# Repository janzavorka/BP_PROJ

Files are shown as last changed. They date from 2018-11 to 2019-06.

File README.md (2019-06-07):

# BP_PROJ

### piskvorky_MP [➥](piskvorky_MP/)
- Piškvorky pro až 5 hráčů
- 1x arduino Due jako server, max 5x arduino Ethernet s dotykovým displejem jako client
- připojovánou přes router s DHCP (serveru nutno přidělit pevnou IP)
- aktualizovaný návod na ovládání [zde](https://github.com/janzavorka/BP_PROJ/blob/master/piskvorky_MP/manual.md)
---

### Piskvorky_red [➥](Piskvorky_red/)
- Původní verze verze hry pouze pro dva hráče
- HW: 2x Arduino Ethernet, 2x 2,4" dotykový display
- jedno arduino jako server, druhé jako client (pevná IP adresa)
---

### Knihovny [➥](Knihovny/)
- Knihovny použité pro ovládání (nemusí být aktuální verze)
- Domovské stránky knihoven:
    - [SimpleTimer](https://github.com/schinken/SimpleTimer)
    - Pro ovládání displeje:
        - [MCUFRIEND_kbv](https://github.com/prenticedavid/MCUFRIEND_kbv)
        - [Adafruit_TouchScreen](https://github.com/adafruit/Adafruit_TouchScreen)
---

### Menu [➥](Menu/)
- Návrh původního menu pro piškvorky
---

### piskvorky_case [➥](piskvorky_case/)
- Návrh krabiček pro jednotlivá zařízení ([Autodesk Inventor Professional 2019 Student Edition](https://www.autodesk.cz/products/inventor/overview))
- Realizace pomocí 3D tisku

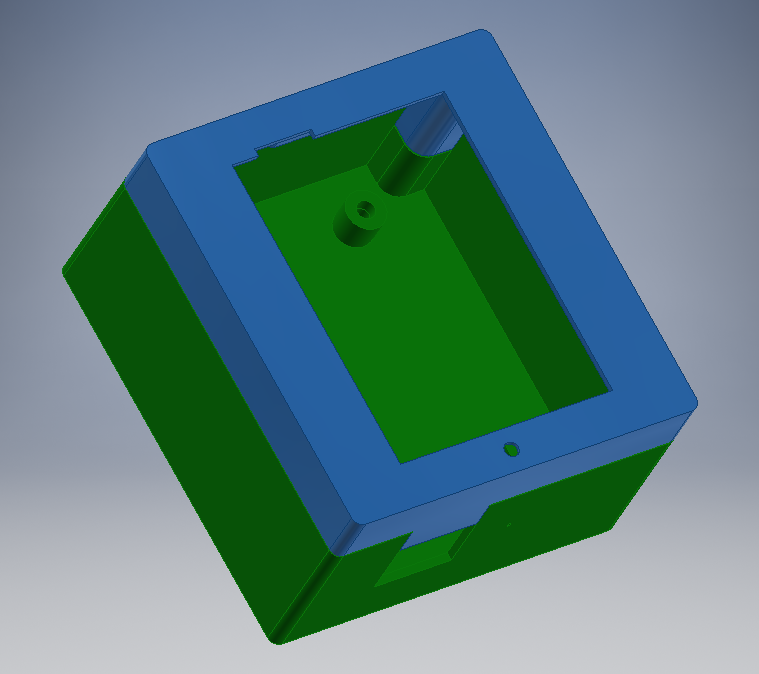
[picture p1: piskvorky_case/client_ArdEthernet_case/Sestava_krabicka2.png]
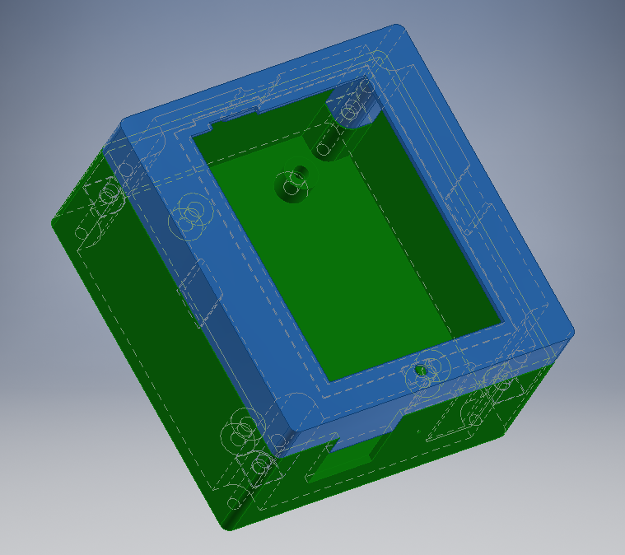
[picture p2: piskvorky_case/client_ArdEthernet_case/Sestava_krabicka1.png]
|   |
|:---------:|
|Krabička pro clienta (Arduino Ethernet s 2,4" displejem)|

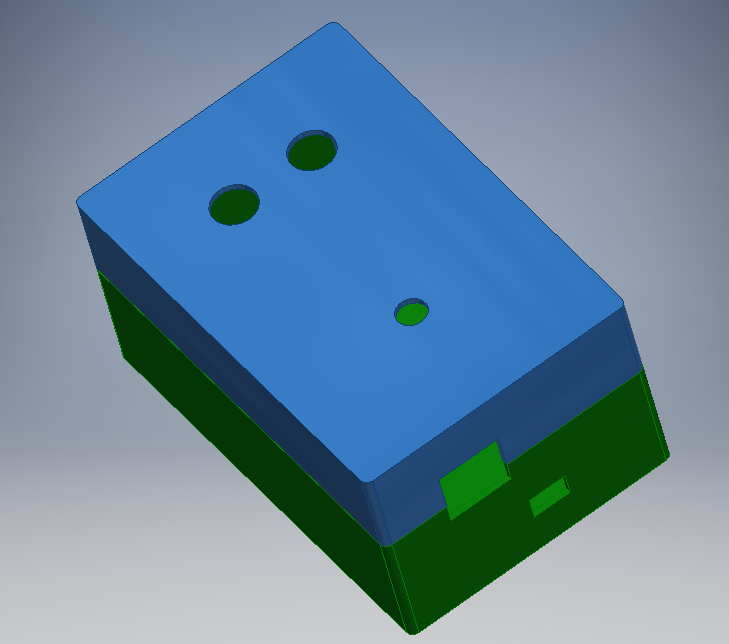
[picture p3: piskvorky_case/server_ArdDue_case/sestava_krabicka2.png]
Krabička pro server
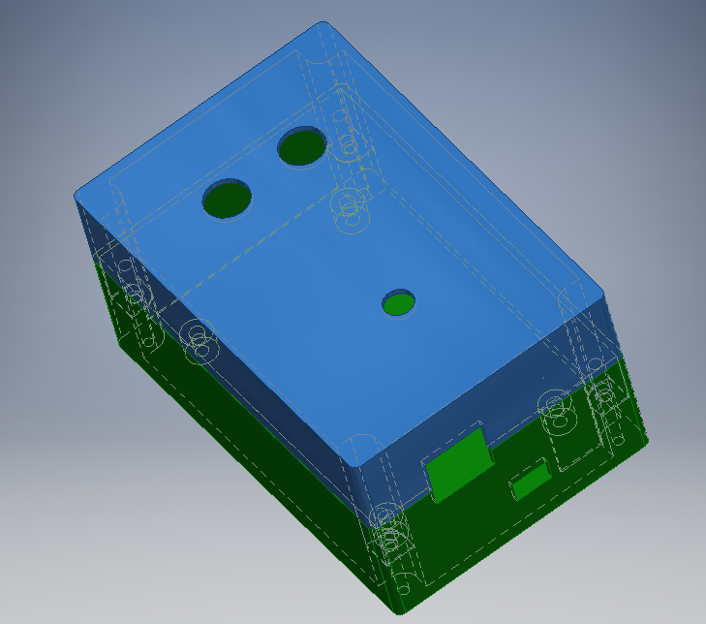
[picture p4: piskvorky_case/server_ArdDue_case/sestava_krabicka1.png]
Krabička pro server
|   |
|:---------:|
|Krabička pro server (Arduino Due s Ethernet modulem + tlačítka a signalizační LED)|

 ---

### piskvorky_MP_old [➥](piskvorky_MP_old/)
- Starší funkční verze projektu
---

### BAP [➥](BAP/zaverecna_prace_FEL/)
-  Bakalářská práce, předmět BBAP15	 [(pdf)](BAP/zaverecna_prace_FEL/main.pdf)
- Prezentace k obhajobě [(pdf)](BAP/prezentace_obhajoba/zavorja4_BAP_prezentace.pdf)
---

### Zprava_BPROJ [➥](Zprava_BPROJ/)
-  Výstupní zpráva z celého projektu pro předmět B2BPROJ4 [(pdf)](Zprava_BPROJ/BPROJ_zprava.pdf)
---

### RGB_LED_cal [➥](RGB_LED_cal/)
- Slouží ke kalibraci barev pro RGB LED u serveru (Arduino Due)
- RGB LED připojení:
    - R -> D6
    - G -> D7
    - B -> D8
- RGB LED se připojí na příslušné PWM piny, změna barev a celkové intenzity probíhá pomocí sériového monitoru
- Příkaz _"help"_ vypíše nápovědu přímo na sériový monitor
- Příkaz: _"led rrr,ggg,bbb,inten"_, kde:
    - _rrr,ggg,bbb_ jsou voleny z <0;&nbsp;255> a reprezentují jednotlivé barvy
    - _inten_ je volena z <0;&nbsp;100> a reprezentuje celkovou intenzitu LED
 ---

 ### Notes.md [➥](Notes.md)
 - Několik zjištění a postřehů z tvorby tohoto projektu

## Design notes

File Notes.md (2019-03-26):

# Notes for this project

### Plugin pro Atom
- Funkční plugin pro Atom: [arduino-upload](https://atom.io/packages/arduino-upload)
- Pro funkčnost nutné Arduino IDE, v nastavení pluginu specifikovat cestu k _arduino_debug.exe_
- Vytváří .bin, .hex soubory, ignorovány pomocí [.gitignore](/.gitignore)
- Pro správný výpis informací/chyb během kompilace/uploadu by měl být jazyk v Arduino IDE nastaven na _English_

### Kalibrace displejů
- Při kalibraci displeje se standardně připojí Arduino k počítači pomocí převodníku USB->USART aby bylo možné číst údaje při kalibraci ze sériové linky
- Připojený displej ovšem odebírá kolem 300 mA což s při připojení delším USB kabelem vytvoří úbytek napětí a kalibrace není tak přesná (výkyv klidně o 300 mV)
- Eliminováno připojením externího zdroje 5 V

### Arduino PoE
- Pro Arduino Ethernet lze dokoupit a připájet PoE shield, tato sestava byla i ofociálně prodávána na [Arduino storu.](https://store.arduino.cc/arduino-ethernet-rev3-with-poe)
- Příslušné otvory jsou na Arduinu Ethernet k dispozici a jsou zapojeny
- Problém pro tento projekt je, že napájení z PoE modulu je přivedeno na vstup regulátoru, co má Arduino na desce. Při použití PoE modulu s 5 V na výstupu bude napětí na výstupu regulátoru o cca 0,8 V nižší (tj. ne potřebnýcch 5 V). Při použití modulu s 12 V výstupem se bude regulátor přehřívat kvůli velkému odběru displeje.
- Z [datasheetu](https://www.semiconductorstore.com/pages/asp/DownloadDirect.asp?sid=1553431563413) PoE modulu plyne, že pokud je pin ADJ připojen na pin +VDC, bude napětí na výstupu PoE modulu 5,50 V (což je na desce Arduina realizováno). Po započítání úbytku napětí na regulátoru by bylo napětí cca 4,8 V (musel by se překalibrovat displej na tuto hodnotu).

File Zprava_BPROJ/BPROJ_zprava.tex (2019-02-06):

\documentclass[a4paper,12pt, twoside]{article} % papír A4, písmo 12 bodu
\usepackage[utf8x]{inputenc} %kodovaní UTF-8
\usepackage{ucs} %kodovani unicode
\usepackage[czech]{babel} %podpora cestiny
\usepackage[T1]{fontenc} %pouzij variantu pisma T1 (hacky, carky)
\usepackage[left=3.5cm,right=2cm,top=2.5cm,bottom=2.5cm]{geometry} %okraje stranky
\usepackage{amsmath,amsfonts,amssymb} %podpora matematiky
\usepackage{gensymb,marvosym} %symboly celsius (\celsius) apod.
\usepackage{times} %font Times New Roman (matematika bude vychozim pismem Computer Modern) 
\clubpenalty 10000  %kontrolovat sirotky
\widowpenalty 10000 %kontrolovat vdovy
\usepackage{setspace} \onehalfspacing %podpora pro zmenu radkovani + radkovani 1,5
\usepackage{enumerate} %podpora pro zmenu cislovani
\usepackage[unicode]{hyperref} %podpora hypertextu
\usepackage{fancyhdr} %vlastni zahlavi a zapati
\usepackage{graphicx} %podpora grafiky
\graphicspath{{img/}} %vychozi adresar s obrazky
\usepackage[normalem]{ulem} %Pro tabulku z Tablesgenerator.com
\useunder{\uline}{\ul}{} %Pro tabulku z Tablesgenerator.com
%"\catcode`\-=12" %V případě nefunkčnosti tabulek z tablegenerator.com
%--prostredi pro vkladani grafu ---
\usepackage{float}
\newfloat{graf}{hbtp}{ext}
\floatname{graf}{Graf}
%---pouziti:
%	\begin{graf}[hbtp]
%	\includegraphics[width=10cm]{graf.png}
%	\caption{Popisek grafu}
%	\end{graf}
%

%Redefinice prostředí abstract
\renewenvironment{abstract}
 {\small
  \begin{center}
  \bfseries \large \abstractname\vspace{-.5em}\vspace{0pt}
  \end{center}
  \list{}{%
  \itshape
    \setlength{\leftmargin}{0mm}
    \setlength{\rightmargin}{\leftmargin}%
  }%
  \item\relax}
 {\endlist}
 
%Prostředí pro klíčová slova
\newenvironment{keywords}
 {\small
 \vspace*{1cm}
  \list{Klíčová slova:}{
    \setlength{\leftmargin}{1cm}%
    \setlength{\rightmargin}{0cm}%
  }%
  \item\relax}
 {\endlist}

%--------------- UDAJE O PRACI -------
\newcommand{\jmeno}{Jan Závorka} %Jméno autora 
\newcommand{\nazev}{Arduino - piškvorky} %Název práce (čeština)
\newcommand{\nazevEN}{Arduino - tic-tac-toe}
\newcommand{\workType}{Projekt bakalářský} %Typ práce
\newcommand{\fakulta}{Fakulta elektrotechnická} %Fakulta
\newcommand{\katedra}{Katedra radioelektroniky} %Katedra
\newcommand{\vedouci}{Ing. Stanislav Vítek, Ph.D.} %Vedoucí práce
\newcommand{\datum}{\today} %Případně místo \today vložit svoje napevno 
%-------------------------------------

\begin{document}
%>>>>>>> Titulní strana
\begin{titlepage}
\centering

\begin{center}
\vspace*{1cm}{\Large \bf ČESKÉ VYSOKÉ UČENÍ TECHNICKÉ V PRAZE} \\
{\large \bf \fakulta} \\
{\large \bf \katedra} \\
\vspace*{2cm} {\LARGE {\bf \nazev}}\\
\vspace*{0.7cm}
{\LARGE {\bf \nazevEN}} \\
\vspace*{1.cm}{\large \workType}
\end{center}

~\vfill
\begin{tabular}{p{.2\linewidth} p{.5\linewidth} p{.25\linewidth}}
~ & ~ & ~ \\
Studijní obor: & {\bf Elektronika a komunikace} & ~\\[.4em]
{ Vedoucí práce:} & \multicolumn{2}{l}{{\bf \vedouci} } \\
\end{tabular}\\
~\vfill
\begin{center}
{\Large \bf \jmeno} \\
{\Large \bf Praha, \datum}
\end{center}
\end{titlepage}
%>>>>>>> Prohlášení
\setcounter{page}{0} %cislo strany
\pagestyle{empty} %Nezobrazovat číslo stránky
\newpage ~\vfill „Prohlašuji, že jsem předloženou práci vypracoval samostatně a že jsem uvedl
veškeré použité informační zdroje v souladu s Metodickým pokynem o
dodržování etických principů při přípravě vysokoškolských závěrečných prací.“\\[3em]
V~Praze dne \today \hspace{.2\textwidth} \dotfill\\
\hspace*{11cm} Podpis
%>>>>> ABSTRACT <<<<<<
\newpage
%\begin{abstract}
%----- TADY BUDE ABSTRACT -----
%\end{abstract}
%>>>>>>> KEYWORDS <<<<<<<
%\begin{keywords}
%Arduino ethernet, piškvorky, komunikace Arduino-Arduino
%\end{keywords}
%>>>>> Obsah <<<<<<<
\newpage
\tableofcontents %vytiskne obsah
%>>>>>>> Seznam tabulek a obrázků <<<<<<<
\newpage
\listoftables
\listoffigures
% --- definice zapati a cislovani ---
\newpage 
\pagestyle{fancy} %vlastni zahlavi/zapati
\renewcommand{\headrulewidth}{0pt} %bez linky v zahlavi
\renewcommand{\footrulewidth}{.5pt} %linka v zapati
\lhead{}       \chead{} \rhead{} %pole zahlavi (prazdna)
\lfoot{\nazev} \cfoot{} \rfoot{\thepage} %pole zapati
%
%>>>>>>> Vlatní text práce <<<<<<<
\clearpage
\section{Úvod} 
\label{sec:uvod}
Cílem bylo vytvořit jednoduchý projekt, který by demonstroval možnosti komunikace Arduin po lokální síti. Po několika experimentech se jako zajímavá varianta jevila jednoduchá hra pro více hráčů. Vzhledem k použitému hardwaru se jako nejlepší možnost ukázala hra Piškvorky (v této verzi pro 2 - 5 hráčů). 
%
%=====================================
\section{Hardware}
\label{sec:hardware}
Z počátku bylo vše postaveno na deskách Aruino Ethernet. Pro možnost hry více než dvou hráčů bylo jedno Arduino použito jako server (bez displeje), které mělo za úkol řídit celou hru a Arduina s displejem (jako clienti) sloužili pouze jako zobrazovací zařízení a ke komunikaci s uživatelem (prostřednictvím dotykové displeje). Tato volba s sebou přinesla několik problému. 

Prvním problémem je malá paměť Arduina Ethernet (dle \cite{arduinoEthernet_page} je pro program k dispozici 32 kB paměti). 
Po přidání všech knihoven (konkrétně popsáno v kapitole \ref{sec:knihovny}) zůstane pro samotný program k dispozici 30 \% programové paměti, což je dost limitující ve spojení s použitím barevného dotykového displeje.

Dalším problém s omezenými prostředky Arduina Ethernet nastal při vývoji serveru. Díky absenci dotykového displeje bylo pro samotný kód k dispozici dostatek místa, ale problémy nastaly při komunikaci, kdy během odesílání dat (přenáší se pole o velikosti 140 bajtů pro každého clienta zvlášť, detailněji v kapitole   \ref{sec:komunikace_server_client}) docházelo k náhodným pádům a restartům Arduina. Tento problém byl vyřešen použitím desky Arduino Due.

Celková finální sestava pro tento projekt se sestávala z následujícího hardwaru:
\begin{itemize}
\item 1x router Huawei EchoLife HG520i, viz. kapitola \ref{sec:router}.
\item 3x client s Arduino Ethernet (celková sestava clienta popsána v kapitole \ref{sec:client}).
\item 1x server s Arduino Due (celková sestava serveru popsána v kapitole \ref{sec:server}).
\item příslušné napájecí adaptéry pro router (součástí balení) a pro Arduina (5 V, 2000 mA).
\end{itemize}

\begin{figure}[hbtp]
\centering
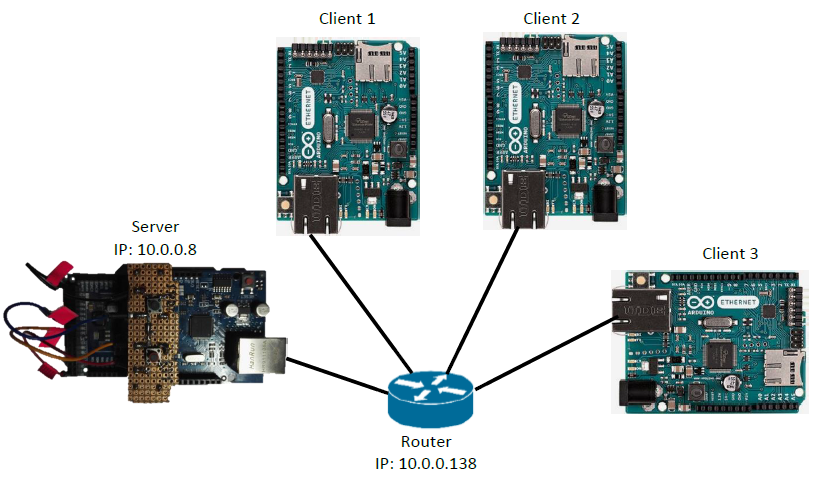
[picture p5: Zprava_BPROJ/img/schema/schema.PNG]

\caption{Schéma zapojení celé sestavy, zdroj \cite{router_symbol}, \cite{arduinoEthernet_page}}
\end{figure}
%_____________________________________
\newpage
\subsection{Client}
\label{sec:client}
Základem je, jak už bylo zmíněno výše, Arduino Ethernet s mikrokontrolérem ATmega328P. Jako zobrazovací a ovládací prvek byl zvolen 2.4" barevný TFT LCD displej s rozlišením 320x240 pixelů s rezistivní dotykovou plochou ve formě shieldu.
Vzhledem k rozměrům (výšce) RJ-45 konektoru, který je umístěný na desce s Arduinem, je nutné pro správné připojení displeje použít lištu s oboustrannými kolíky o délce minimálně 15 mm. Protože u displejů použitých v této práci byly kolíky připájené už od výrobce, byla dodatečně vyrobena patice z dutinkové lišty a lišty s oboustrannými kolíky.

%Foto clienta
\begin{figure}[hbtp]
\centering
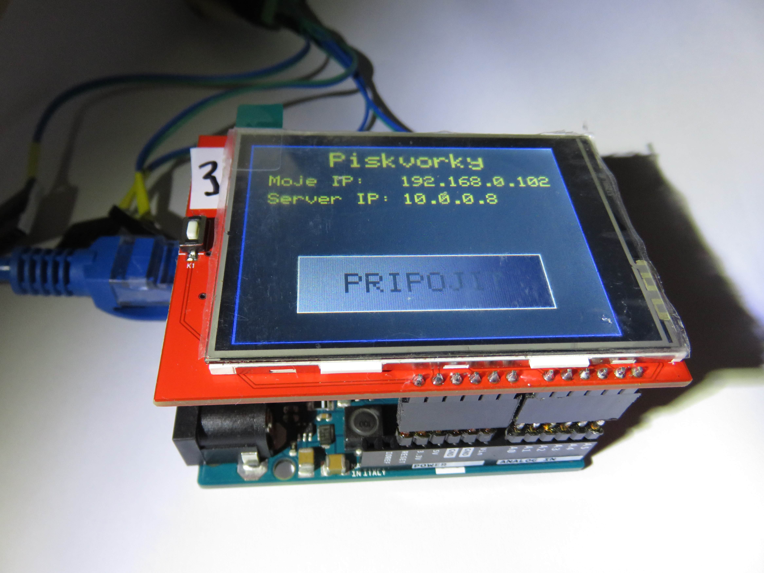
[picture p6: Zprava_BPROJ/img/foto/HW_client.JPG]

\caption{\label{fig:HW_client} Fotografie funkční verze clienta}
\end{figure}
%_____________________________________

\subsection{Server}
\label{sec:server}
Základem serveru je Arduino Due (bližší specifikace v \cite{ArduinoDue_page}). Pro připojení do sítě byl zvolen Ethernetový shield s čipem Wiznet W5100. 

Pro pohodlné ovládání hry jsou k serveru připojena dvě tlačítka, tlačítko s červeným kroužkem slouží pro zastavení a restart hry, tlačítko se zeleným kroužkem slouží pro start hry. Schéma zapojení je vidět na obrázku \ref{fig:server_switch_module}. Zapojení bylo pro testovací účely zhotoveno na univerzální desce plošných spojů. Připojení je realizováno pomocí vodičů, kolíky umístěné v desce slouží pouze k připevnění k Arduinu nebo shieldu. Vodiče s připojí podle barvy následovně: 
\begin{enumerate}
\item Černý - GND
\item Modrý - D40
\item Oranžový - D38
\item Červený - 5 V
\end{enumerate}
Místo pinů D40 a D38 lze použít libovolné jiné, ale tato změna musí být upravena v kódu pro server (viz. kapitola \ref{sec:nastaveni_server}).
%Schéma modulu s tlačítky
\begin{figure}[hbtp]
\centering
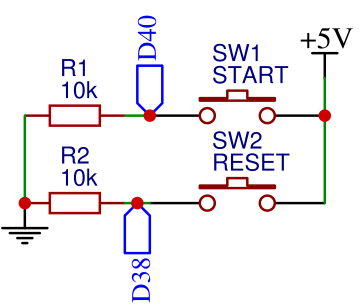
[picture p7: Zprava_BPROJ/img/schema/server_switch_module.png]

\caption{\label{fig:server_switch_module}Schéma zapojení tlačítek pro ovládání serveru}
\end{figure}
%Fotografie serveru
\begin{figure}[hbtp]
\centering
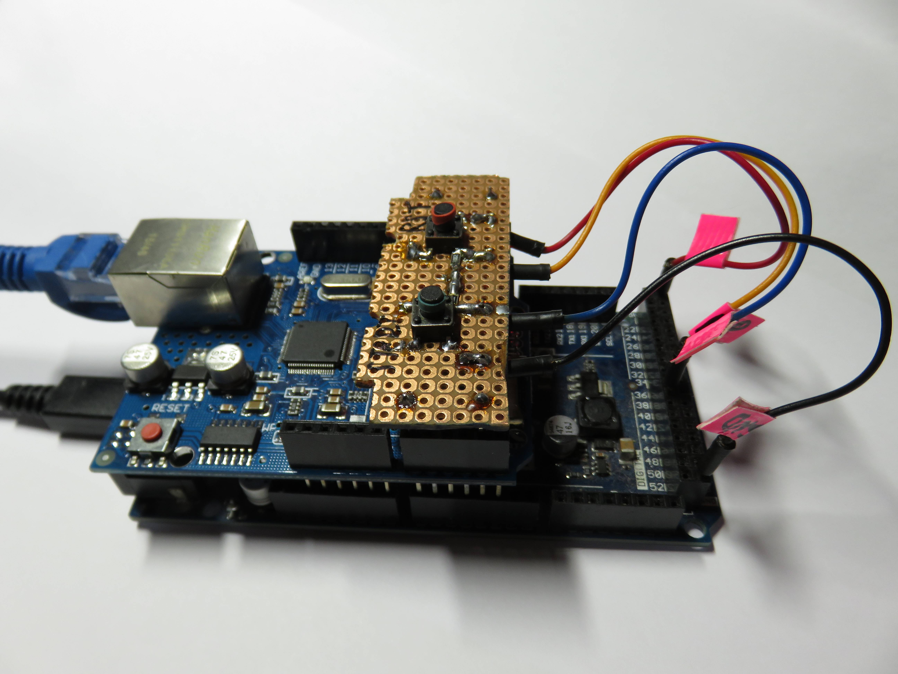
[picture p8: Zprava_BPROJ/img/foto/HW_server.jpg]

\caption{\label{fig:HW_server}Fotografie funkční verze serveru}
\end{figure}
%____________________________________
\subsection{Napájení}
\label{sec:napajeni}
Napájení je řešeno externím zdrojem 5 V DC. Client se k napájení připojuje na programovací vstup (místo převodníku USB/UART), na piny: 1 = GND a 3 = 5V (zprava). Připojení externího zdroje pomocí souosého konektoru a využití integrovaného stabilizátoru není možné, protože client s displejem odebírá za provozu kolem 300 mA. 

Je třeba také dbát na správné dimenzování napájecího zdroje, aby nedocházelo k poklesu napájecího napětí, protože tím by došlo k výkyvu reference pro dotykovou plochu a dotyky by nemusely být správně vyhodnoceny. 
%_____________________________________
\subsection{Router a nastavení sítě}
\label{sec:router}
Pro testování byl použit Huawei EchoLife HG520i. V nastavení byly vypnuty všechny funkce (WiFi apod.) a byl nakonfigurován DHCP server. Konfigurační soubor dostupný v příloze \ref{priloha:github_router_conf}.

Aby se Arduina mohla spojit, je nutná aby měl server statickou IP adresu. Tento router neumožňuje přiřazení IP adresy k dané MAC, proto má server pevně přiřazenou IP (její změna popsána v kapitole \ref{sec:nastaveni_server}). Tato adresa musí být ze stejné sítě jako je router ale mimo rozsah DHCP serveru.

Clientům je IP adresa přiřazována automaticky pomocí DHCP.
%_____________________________________
%=====================================
\clearpage
\section{Software}
%_____________________________________
\subsection{Knihovny}
\label{sec:knihovny}
Seznam použitých knihoven pro clienta:
\begin{itemize}
\item \textit{Ethernet library}: komunikace po LAN (se serverem), zdroj \cite{library_ethernet}.
\item \textit{UTFGLUE}: ovládání displeje, zdroj \cite{library_UTFGLUE}.
\item \textit{TouchScreen}: práce s dotykovou plochou, zdroj  \cite{library_touch}.
\end{itemize}

Seznam použitých knihoven pro server:
\begin{itemize}
\item \textit{Ethernet library}: komunikace po LAN (s jednotlivými clienty), zdroj \cite{library_ethernet}.
\end{itemize}
%_____________________________________
\subsection{Komunikace}
\subsubsection{Komunikace Server -> Client}
\label{sec:komunikace_server_client}
Během komunikace tímto směrem vždy server odešle celou herní desku (pole typu byte \textit{board}), celkem tedy 136 bajtů. Pokud client toto pole v pořádku přijme, dojde k jeho vyhodnocení a vykonání potřebných funkcí (překreslení displeje, vyžádání akce od uživatele, zobrazení hlášky). Hodnoty pole mění pouze server. Popis pole a co které hodnoty představují je vidět v tabulce \ref{tab:board_content}. 

Při odesílání je pole rozděleno do packetů. Každý packet obsahuje 8 bajtů pole \textit{board}, pořadové číslo packetu (aby client mohl pole zpětně sestavit) a dva bajty kontrolního součtu. 

Client průběžně přijímá jednotlivé části, pokud dorazí nějaká část chybná (nesedí kontrolní součet), client si může vyžádat od serveru znovuodeslání (realizace popsána v kapitole \ref{sec:komunikace_client_server}). Pokud client přijme všechny části, pole \textit{board} vyhodnotí.
%Tabulka herní desky (pole board)
\input{img/tabulky/board_content.tex}
%
\subsubsection{Komunikace Client -> Server}
\label{sec:komunikace_client_server}
Při této komunikaci se přenáší vždy dva bajty, přičemž celá zpráva je odeslána dvakrát po sobě. Server po přijetí obou zpráv zprávy porovná a pokud se neliší provede dané instrukce (význam v tabulce \ref{table:clietn-server}). V případě neshody je zpráva zahozena. 
%Tabulka přenášeného packetu
\input{img/tabulky/client_packet.tex}
%_____________________________________
\newpage
\subsection{Změny a nastavení}
Všechny hodnoty, které je možno podle potřeby konfigurovat a nedojde tím k nesprávnému fungování zařízení jsou vždy označeny komentářem v kódu:
\begin{verbatim}
/* ---------- KONFIGURACE ----------*/
\end{verbatim}
Konkrétní konfigurovatelného hodnoty jsou popsány v podkapitolách, detaily pak přímo ve zdrojovém kódu (příloha \ref{priloha:github_zdrojovy_kod}) pomocí komentářů.
\subsubsection{Server}
\label{sec:nastaveni_server}
\begin{itemize}
\item \textit{Adresa MAC} \ldots vzhledem k tomu, že zařízení je provozováno na samostatné síti, adresy byly voleny náhodně a nemůže dojít ke kolizi MAC adres. V případě, že zařízení bude provozováno v síti s cizími zařízeními,  může být nutné MAC adresu změnit. K odstranění nebo snížení pravděpodobnosti kolize lze použít například postup popsaný v \cite{nastaveni_mac}. Zjistí se MAC existujícího cizího zařízení (byla mu přidělena výrobcem), zvětší se poslední bajt o jedna a takto vzniklá MAC adresa se přidělí našemu zařízení.
%%%
\item \textit{Připojení tlačítek} \ldots nastavují se čísla pinů, ke kterým jsou připojena ovládací tlačítka, nastavení pouze změnou kódu.
%%%
\item \textit{IP adresa} \ldots požadavky v kapitole \ref{sec:router}, nastavení změnou v kódu.
%%%
\item \textit{počet polí k výhře} \ldots nastavení počtu polí, které je nutné obsadit aby došlo k výhře. Obsazené pole musí být v souvislé řadě svisle, vodorovně nebo diagonálně. 
\end{itemize}
%%%%%%%
\subsubsection{Client}
\label{sec:nastaveni_client}
\begin{itemize}
\item \textit{Adresa MAC} \ldots platí to stejné jako pro server, popsáno v kapitole \ref{sec:nastaveni_server}.
%%%
\item \textit{IP adresa serveru} \ldots nastavuje se IPv4 adresa, která byla přiřazena serveru.
%%%
\item \textit{Kalibrace dotykové plochy} \ldots nastavují se čtyři hodnoty, minimum a maximum pro osu \textit{x} a pro osu \textit{y}. Hodnoty lze zjistit například použitím příkladového programu obsažené v knihovně UTFGLUE. Lze ho nalézt v příklady~->~MCUFRIEND\_kbv~->~TouchScreen\_calibr\_kbv.
\end{itemize}
%_____________________________________
%=====================================
\clearpage
\section{Uvedení do provozu a postup hry}
\subsection{Server}
\begin{enumerate}
\item Server se připojí pomocí síťového kabelu k routeru a připojí se i napájení. Server lze připojit microUSB kabelem k počítači a sledovat informace a stav hry na sériové lince.

%%
\item Po připojení alespoň dvou clientů lze spustit hru zeleným tlačítkem. Hru lze kdykoliv přerušit červeným tlačítkem. Ovládání hry je možné kromě tlačítky také příkazy přes sériovou linku (v Arduino IDE: Nástroje->Sériový monitor nebo například pomocí \href{https://www.putty.org/}{Putty}), jejich seznam je v tabulce \ref{tab:server_prikazy}.
\end{enumerate}
%Tabulka příkazů
\input{img/tabulky/server_prikazy.tex}
%_____________________________________
\subsection{Client}
\begin{enumerate}
\item Client se připojí pomocí síťového kabelu k routeru a připojí se k napájení. Pokud nebyl kabel správně připojen nebo client neobdržel IP adresu od DHCP serveru, zobrazí se na displeji žlutá hláška \uv{Zkontrolujte pripojeni kabelu}.

%%%
\item Pokud připojení do sítě proběhlo v pořádku, zobrazí se úvodní obrazovka (obrázek:~\ref{fig:faze1}).  Zobrazeny jsou informace o nastavené IP adrese serveru a o IP adrese, která byla clientovi přiřazena DHCP serverem.  
\begin{figure}[H]
\centering
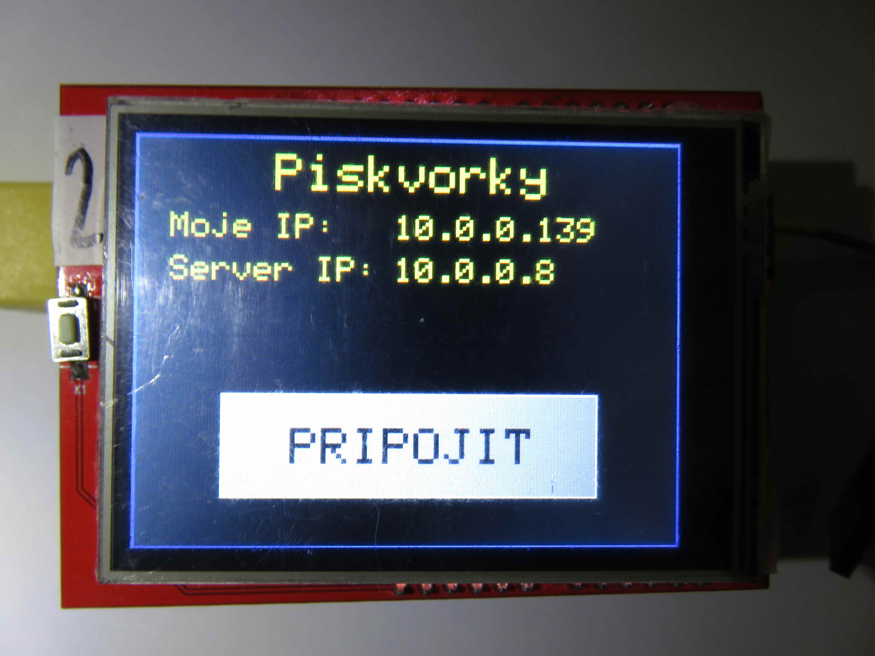
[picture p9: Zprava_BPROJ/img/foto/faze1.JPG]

\caption{\label{fig:faze1} Obrazovka clienta po úspěšném připojení do sítě}
\end{figure}

%%%
\item Připojení k piškvorkovému serveru lze spustit stisknutím tlačítka \uv{\textit{PRIPOJIT}}. Připojování je indikováno pomocí displeje (obrázek \ref{fig:faze2}). Připojování může být kdykoliv přerušena stiskem tlačítka \uv{\textit{PRERUSIT}}. Připojování bude dokončeno pokud na serveru není rozehraná hra.
\begin{figure}[H]
\centering
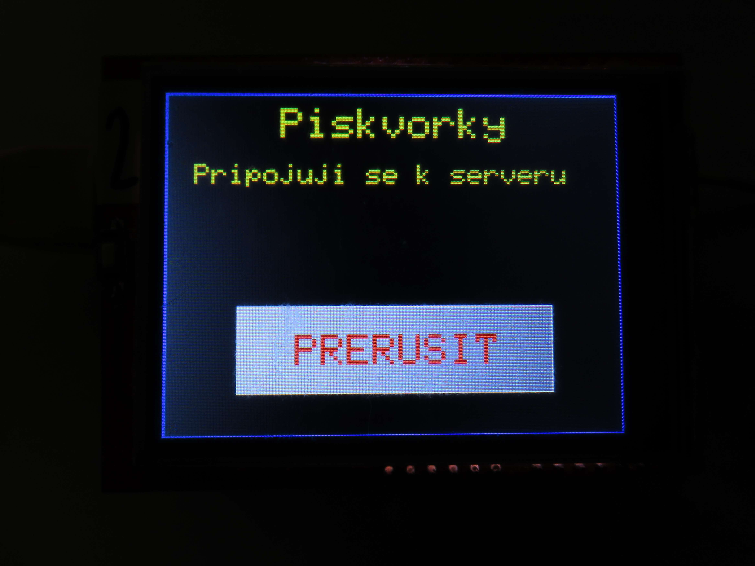
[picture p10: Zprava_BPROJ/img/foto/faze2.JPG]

\caption{\label{fig:faze2} Obrazovka clienta při připojování k serveru}
\end{figure}

%%%
\item Pokud připojení proběhlo úspěšně, client má od serveru přiřazené číslo a barvu. To je indikováno pomocí displeje (obrázek \ref{fig:faze3}), kde barva textu odpovídá barvě hráče. Než započne hra je možné se ze serveru odpojit stiskem tlačítka \uv{\textit{ODPOJIT}}. Nyní se čeká na zahájení hry.
\begin{figure}[H]
\centering
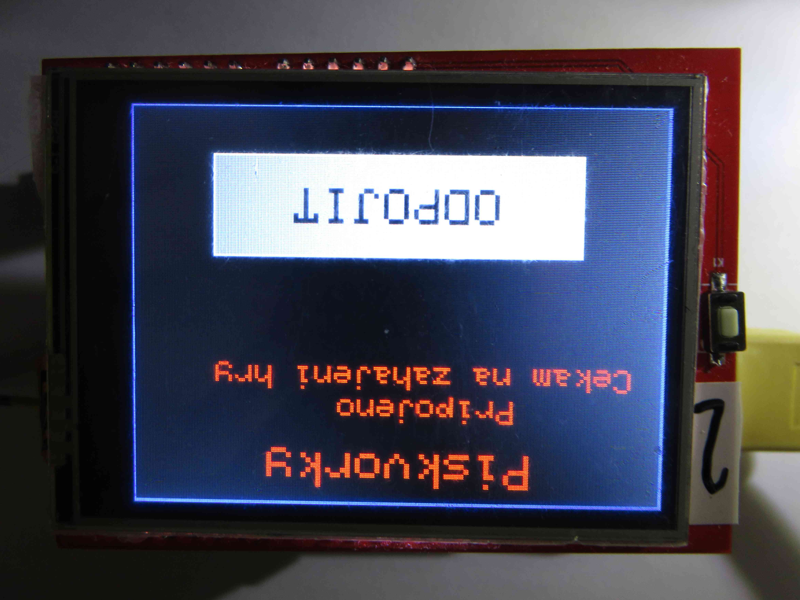
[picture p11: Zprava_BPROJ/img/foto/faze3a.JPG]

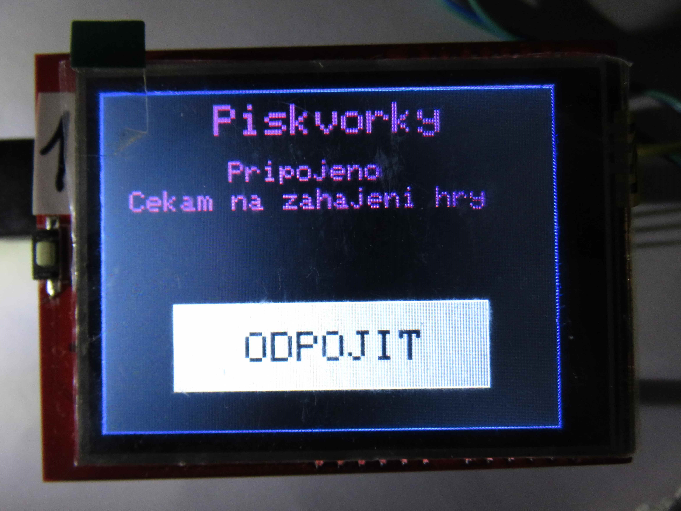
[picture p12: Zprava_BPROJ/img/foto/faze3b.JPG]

\caption{\label{fig:faze3} Obrazovky dvou různých clientů  po úspěšném připojení k piškvorkovému serveru}
\end{figure}
\label{item:faze3}

%%%
\item V případě, že ze strany serveru byla započata hra, vykreslí se na obrazovce herní pole (obrázek \ref{fig:faze4}). 
\begin{figure}[H]
\centering
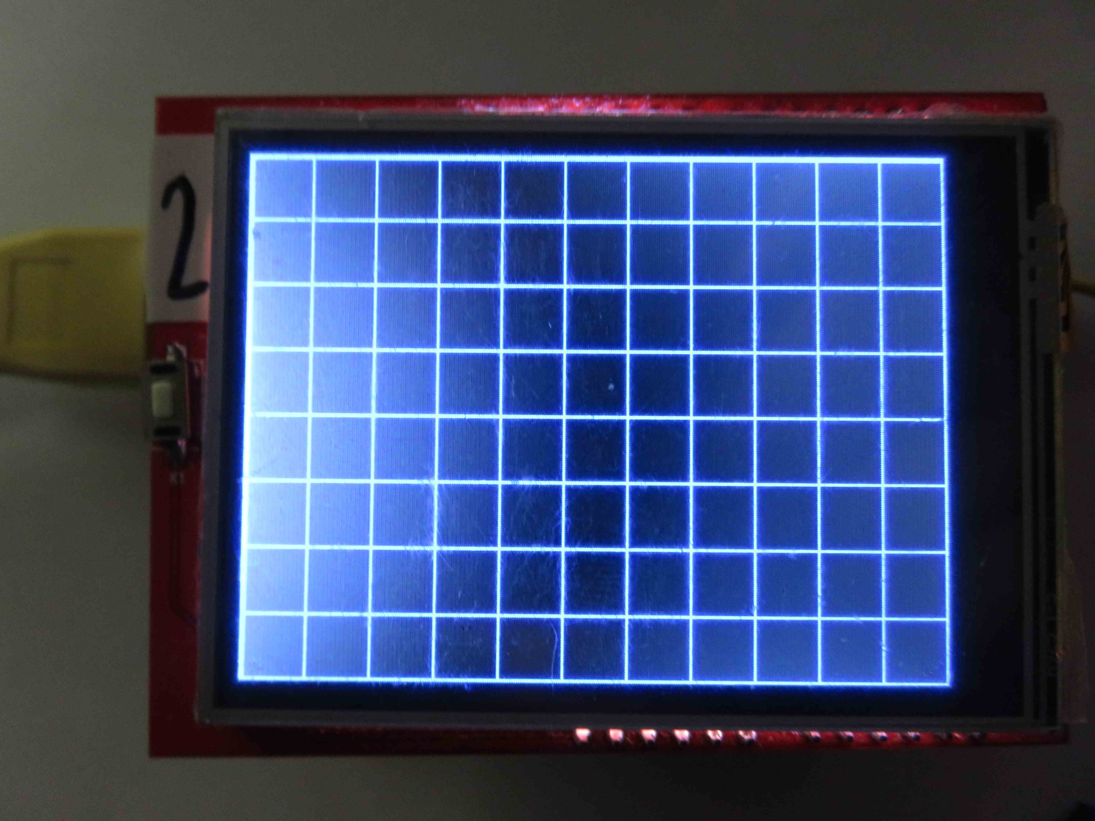
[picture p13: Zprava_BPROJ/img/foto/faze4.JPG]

\caption{\label{fig:faze4} Obrazovka clienta po započaté hře}
\end{figure}

%%
\item Během hry: pokud je mřížky šedá, hraje jiný hráč, pokud má mřížka nějakou barvu (barva se shoduje s barvou hráče) je na tahu daný hráč. Ten má za úkol stiskem libovolného volného čtverečku umístit svůj žeton. 

Pokud ho stiskne, dojde k jeho vyplnění příslušným žetonem (barevným kruhem), mříž zešedne a je na řadě další hráč. Rozehraná hra je vidět na obrázku \ref{fig:faze5}.
\begin{figure}[H]
\centering
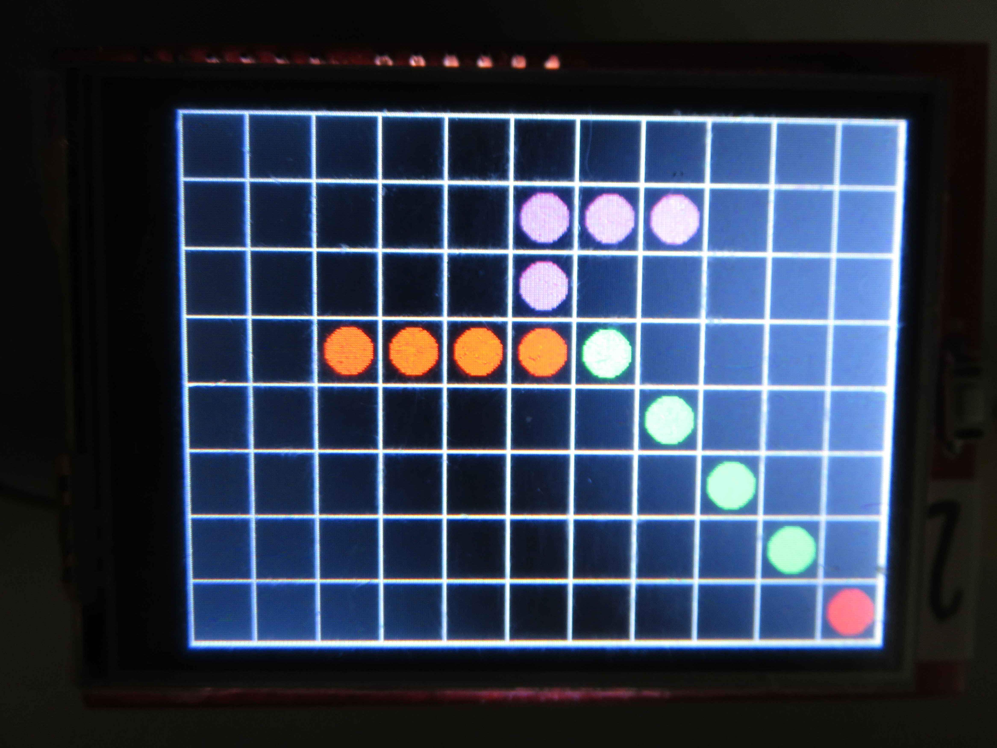
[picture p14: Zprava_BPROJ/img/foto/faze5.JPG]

\caption{\label{fig:faze5} Rozehraná hra tří hráčů, obrazovka jednoho z clientů}
\end{figure}

%%
\item Hráči se střídají do té doby než: jsou všechna pole vyplněna (ukončeno remízou) nebo některý hráč spojil požadovaný počet žetonů (podle nastavení serveru, možnosti uvedeny v kapitole \ref{sec:nastaveni_server}). O výsledku hry jsou hráči informováni hláškou na displeji (obrázek \ref{fig:faze6}). Tato hláška po deseti sekundách zmizí a hra přechází do fáze \ref{item:faze3}.
\begin{figure}[H]
\centering
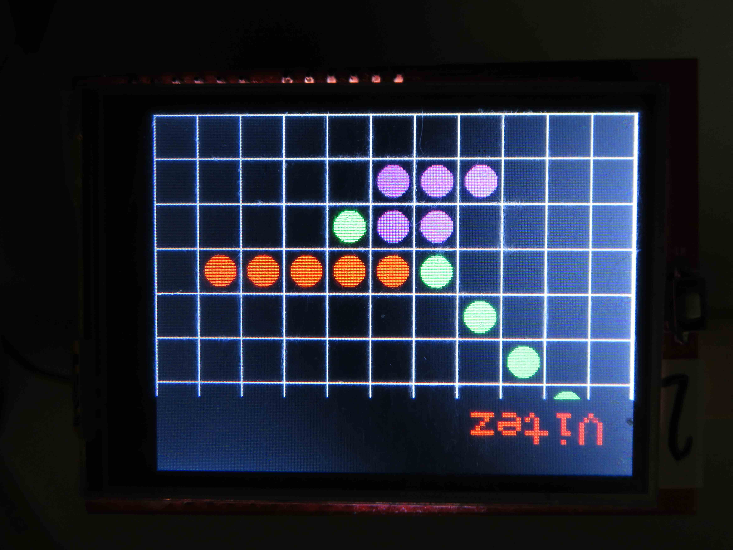
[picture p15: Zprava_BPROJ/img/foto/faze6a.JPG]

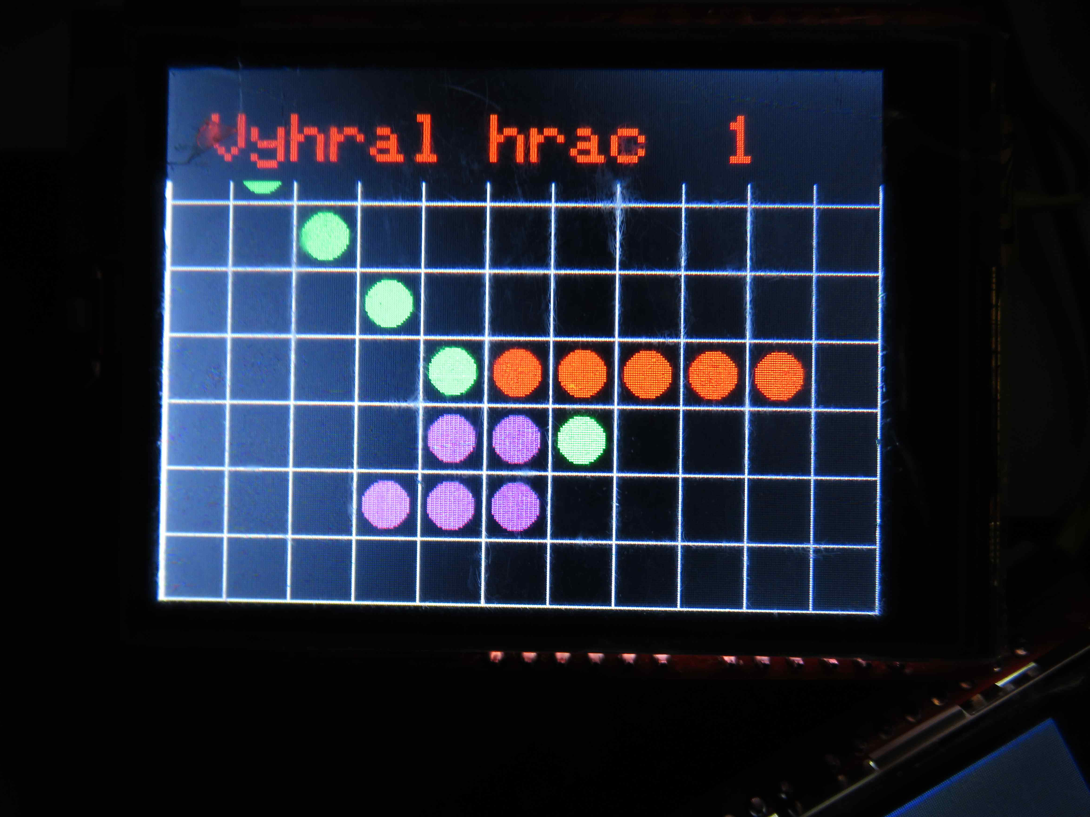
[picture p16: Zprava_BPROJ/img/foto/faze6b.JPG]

\caption{\label{fig:faze6} Zobrazená hláška na displeji výherce (vlevo) a ostatních hráčů (vpravo), barva textu se shoduje s barvou hráče}
\end{figure}
\end{enumerate}
\clearpage
\section{Závěr}
Podařilo se sestrojit zařízení, které zábavnou formu ukazuje možnosti komunikace Arduin po lokální síti. Během realizace se vyskytly určitě problém (z nichž většina byla popsána v této zprávě), které se podařilo vyřešit ať už změnou hardwaru nebo případně určitými kompromisy na straně softwaru (například možnost připojení omezeného počtu hráčů).  

Všechny zdrojové kódy, konfigurační soubory a i elektronická verze této práce (včetně  \LaTeX ového  kódu) jsou k dispozici na autorově \href{https://github.com/janzavorka/BP_PROJ}{Githubu}. Dále zde budou umisťovány i aktualizované kódy s opravami případných chyb.
%
%>>>>>>> Seznam literatury <<<<<<<
\clearpage
%--- Změna nadpisu literatury
\renewcommand{\refname}{Seznam použité literatury a zdrojů informací}
\addcontentsline{toc}{section}{Seznam použité literatury a zdrojů informací}
\begin{thebibliography}{99}
\bibitem{router_symbol}
Network Diagram Symbols and Icons. \textit{LucidChart} [online]. [cit. 2019-02-06]. Dostupné z: https://www.lucidchart.com/pages/network-diagram-icons-and-symbols?a=0
%%%
\bibitem{arduinoEthernet_page}
\textit{Arduino store: ARDUINO ETHERNET REV3} [online]. [cit. 2019-02-05]. Dostupné z: https://store.arduino.cc/arduino-ethernet-rev3-without-poe
%%%
\bibitem{library_ethernet}
\textit{Arduino: Ethernet library} [online]. [cit. 2018-12-18]. Dostupné z: https://www.arduino.cc/en/Reference/Ethernet
%%%
\bibitem{ArduinoDue_page}
\textit{Arduino store: ARDUINO DUE} [online]. [cit. 2019-02-05]. Dostupné z: https://store.arduino.cc/arduino-due
%%%
\bibitem{library_UTFGLUE}
MCUFRIEND\_kbv library. \textit{Github} [online]. [cit. 2019-02-05]. Dostupné z: https://github.com/prenticedavid/MCUFRIEND\_kbv
%%%
\bibitem{library_touch}
Adafruit\_TouchScreen library. \textit{Github} [online]. [cit. 2019-02-05]. Dostupné z: https://github.com/adafruit/Adafruit\_TouchScreen
%%%
\bibitem{nastaveni_mac}
MALÝ, Martin. Arduino: webový server i klient do ruky. \textit{Root.cz} [online]. 27. 7. 2010 [cit. 2019-02-06]. Dostupné z: https://www.root.cz/clanky/arduino-webovy-server-i-klient-do-ruky/
\end{thebibliography}
%--- SEZNAM SOFTWARU ---
\clearpage
\phantomsection %pridej odkaz do PDF zalozek
\addcontentsline{toc}{section}{Seznam použitého softwaru}
\section*{Seznam použitého softwaru}
\begin{enumerate}%[--]
	\item \TeX maker, \TeX Live
	\item \href{https://www.arduino.cc/en/main/software}{Arduino IDE}
	\item \href{https://www.tablesgenerator.com/latex_tables}{Tables Generator}
	\item \href{https://www.citace.com/citace-pro}{Citace.com}
	\item \href{https://easyeda.com/}{EasyEDA}
	\item \href{https://www.irfanview.com/}{IrfanView}
	\item \href{https://linuxmint.com/}{Linux Mint 18.1 Cinnamon 64-bit}
\end{enumerate}
%--- SEZNAM PRILOH ---
\phantomsection %pridej odkaz do PDF zalozek
\addcontentsline{toc}{section}{Seznam příloh}
\section*{Seznam příloh} 
\begin{enumerate}[{Příloha} 1:]
\item \label{priloha:github_router_conf} Konfigurační soubor routeru Huawei EchoLife HG520i na Githubu, dostupné z: \href{https://goo.gl/h8494S}{https://goo.gl/h8494S}
%%%
\item \label{priloha:github_zdrojovy_kod} Zdrojové kódy pro server i clienta na Githubu, dostupné z: \href{https://goo.gl/5roM9V}{https://goo.gl/5roM9V}
\end{enumerate}
\end{document}

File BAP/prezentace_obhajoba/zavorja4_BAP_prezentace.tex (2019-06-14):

\documentclass{beamer}
\usepackage[utf8x]{inputenc} %kodovaní UTF-8
\usepackage{ucs} %kodovani unicode
\usepackage[czech]{babel} %podpora cestiny
\usepackage[T1]{fontenc} %pouzij variantu pisma T1 (hacky, carky)
\usepackage{graphicx}
%\usepackage[dvipsnames]{xcolor} %barvy textu

% >>>>>>> Šablona pro prezentaci <<<<<<<
\usetheme{Frankfurt}
\useinnertheme{circles}
\usepackage{subfigure}
\usefonttheme{professionalfonts}
\usepackage{lmodern} % fonts in a LaTeX document
\usepackage{color}
\definecolor{mygray}{rgb}{0.5,0.5,0.5}
\definecolor{CVUTblue}{cmyk}{1, 0.43, 0, 0} % CVUT blue

%\usecolortheme[named=CVUTblue]{structure}

\usepackage{movie15} %Pro video
\usepackage{geometry}

%Figure numbering
\setbeamertemplate{caption}[numbered]

%Odstranění navigační lišty a přidání čísle slajdů
\beamertemplatenavigationsymbolsempty

%\addtobeamertemplate{navigation symbols}{}{%
%    \usebeamerfont{footline}%
%    \usebeamercolor[fg]{footline}%
%    \hspace{1em}%
%    \insertframenumber/\inserttotalframenumber
%}

\makeatletter
\setbeamertemplate{navigation symbols}{
    \ifbeamer@inappendix%
  \else%
    \usebeamerfont{footline}%
        \usebeamercolor[fg]{footline}%
    \insertframenumber\,/\,\insertmainframenumber%
  \fi%
}
\makeatother

% >>>>>>> Funkce <<<<<<<

% >>>>>>> Informace o práci <<<<<<<
\def\uv#1{\char92\relax #1\char34\relax}
%%%%%%%%%%%%%%%%%%%%%%%%%%%%%%%%%%%%%%%%%%%%%%%%%%%%%%%%%%%%%%%%%%
\newcommand\FirstName{Jan}
\newcommand\FirstNameAbbreviated{F}
\newcommand\LastName{Závorka}
\newcommand\Email{zavorja4@fel.cvut.cz}
\newcommand\DissertationTitle{Interaktivní hra využívající IoT prostředky}
\newcommand\Department{Katedra radioelektroniky}
\newcommand\Faculty{Fakulta elektrotechnická}
\newcommand\University{České vysoké učení technické v Praze \\[.3em] }
\newcommand\FacultyAndUniversityAbbr{FEL ČVUT}
%%%%%%%%%%%%%%%%%%%%%%%%%%%%%%%%%%%%%%%%%%%%%%%%%%%%%%%%%%%%%%%%%%
\subject{SUBJECT}
\author[\FirstNameAbbreviated. \LastName]{\FirstName{} \LastName \\ {\color{mygray}\Email}}
\title{\DissertationTitle}
%\titlegraphic{\includegraphics[width=1.5cm]{img/LogoCVUT.pdf}}
\institute[\FacultyAndUniversityAbbr]{\Department\\ \Faculty\\ \University \\[1em]}
\date{\today}
%\logo{\includegraphics[width=4cm]{img/LogoCVUT.pdf}}

\begin{document}
%\setcounter{numberoframes}{\inserttotalframenumber}
{
\beamertemplatenavigationsymbolsempty
\begin{frame}[plain]
\maketitle
\end{frame}
\addtocounter{framenumber}{-1}
}
%
\section*{Obsah}
\begin{frame}[allowframebreaks]
\frametitle{Obsah}
\tableofcontents
\end{frame}

\section{Cíl práce}
\begin{frame}
\frametitle{Cíl práce}
Demonstrační zařízení:
\begin{itemize}
\item Energeticky nenáročná zařízení
\item Forma jednoduché hry
\item Komunikace po síti 
\item Využití při propagačních akcích
\end{itemize}
\end{frame}

\section{Realizace}
\subsection{Návrh}
\begin{frame}
\frametitle{Realizace}
 \begin{itemize}
 \item Hra piškvorky
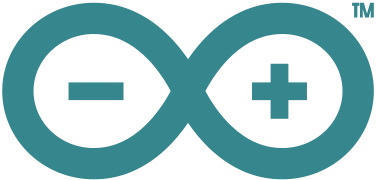
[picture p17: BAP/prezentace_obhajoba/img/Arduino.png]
 \item Platforma Arduino 
 	\begin{itemize}
 		\item Server - řízení hry
 		\item Klient - interakce s uživatelem (3x)
 	\end{itemize}
 \item 3D tisk krabiček (PLA)
 \item Komunikace po lokální síti (centrální prvek switch)
 
 \pause
 \begin{figure}
 \centering
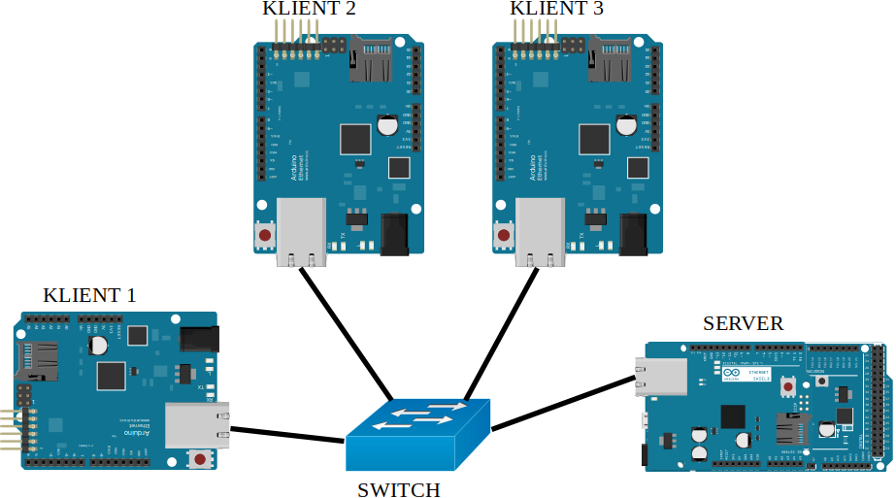
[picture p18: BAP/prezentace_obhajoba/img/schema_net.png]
 
 \caption{Schéma zapojení jednotlivých zařízení do sítě}
 \end{figure}
 \end{itemize}
\end{frame}

\subsection{Zařízení typu server}
\begin{frame}
\frametitle{Realizace - server}
\begin{columns}[c]
 \column{.5\textwidth}
	\begin{figure}
		\centering
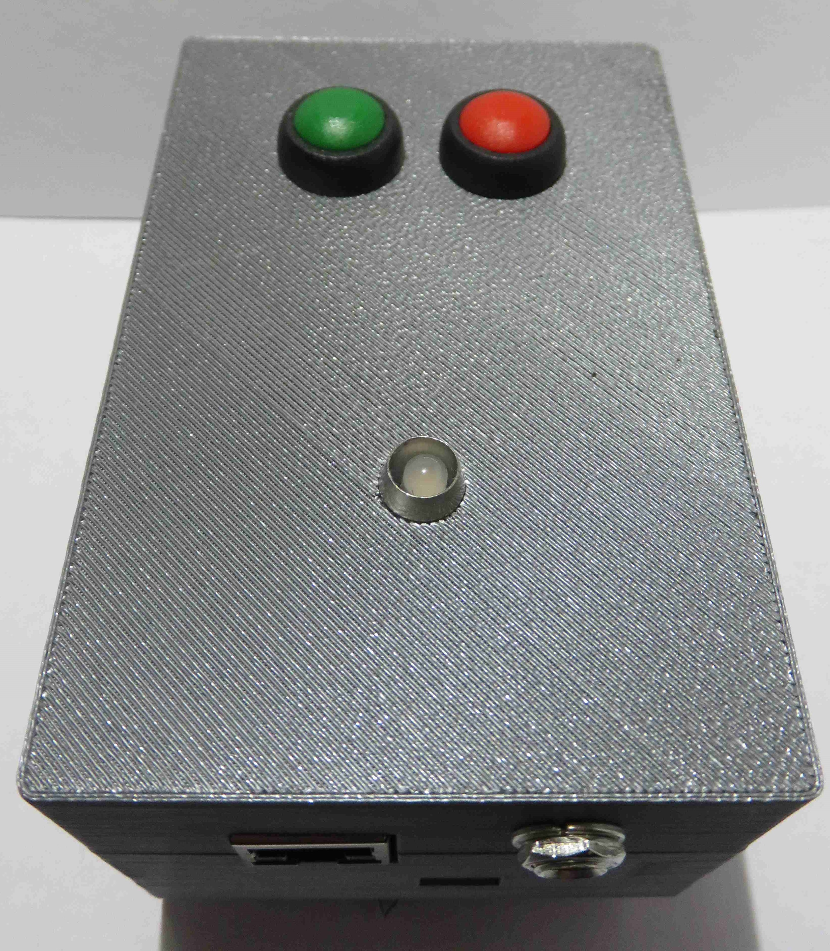
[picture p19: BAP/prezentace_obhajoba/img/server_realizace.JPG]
		
		\caption{Fotografie serveru}
	\end{figure}
%
 \column{.5\textwidth}
	\only<1>{
 		\begin{itemize}
 			\item Arduino Due + Ethernet shield + vlastní DPS
 			\item RJ-45 konektor
 			\item Souosý napájecí konektor (6~-~16~V)
 			\item Indikace stavu pomocí svítivé diody
 			\item Ovládání pomocí tlačítek a sériového rozhraní (microUSB)
 		\end{itemize}
	} 	
 	\only<2>{
		\refstepcounter{framenumber}
		
 		{\color{green} Zelené tlačítko:} Spuštění hry, 
 		
 		\hspace{2.5cm} posun hráče
 		
		{\color{red} Červené tlačítko:} Zastavení hry 	
		\begin{table}
			\centering
			\caption{Stavy svítivé diody}
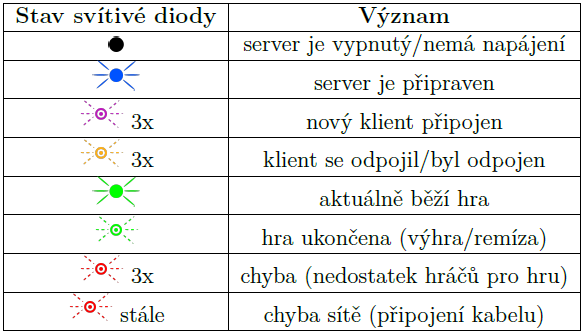
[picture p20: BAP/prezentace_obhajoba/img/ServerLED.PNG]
			
		\end{table}
	}
\end{columns}
\end{frame}

\subsection{Zařízení typu klient}
\begin{frame}
\frametitle{Realizace - klient}
\begin{columns}[c]
 \column{.5\textwidth}
	\begin{figure}
		\centering
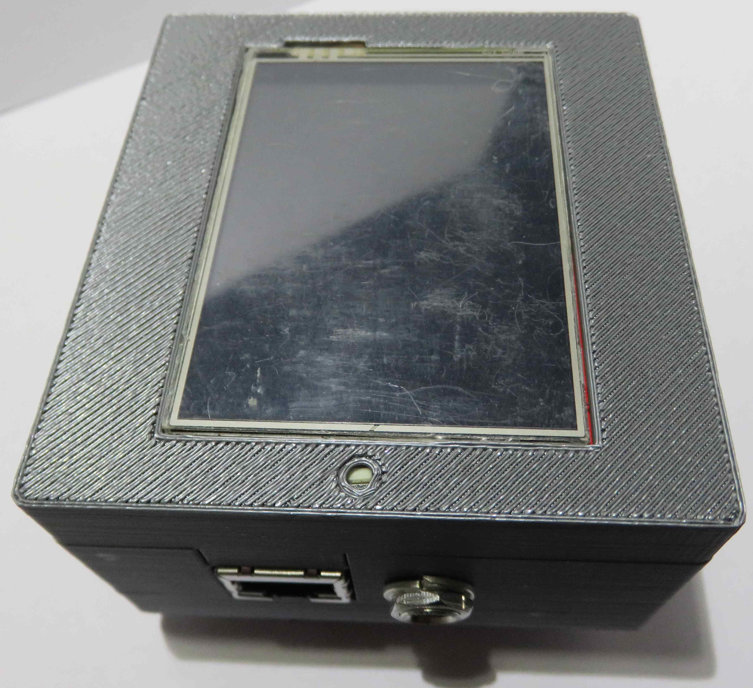
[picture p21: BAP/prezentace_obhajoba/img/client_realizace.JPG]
		
		\caption{Fotografie klienta}
	\end{figure}
%
 \column{.5\textwidth}
 		\begin{itemize}
 			\item Arduino Ethernet
 			\item RJ-45 konektor
 			\item Souosý napájecí konektor (6~-~20~V), modul s DC-DC měničem
 			\item $2,4^{\prime\prime}$ barevný displej
 			\item Rezistivní dotyková plocha
 		\end{itemize}	
\end{columns}
\end{frame}

\begin{frame}
\frametitle{Realizace - klient}
\begin{columns}[c]
 \column{.5\textwidth}
	\begin{figure}
		\centering
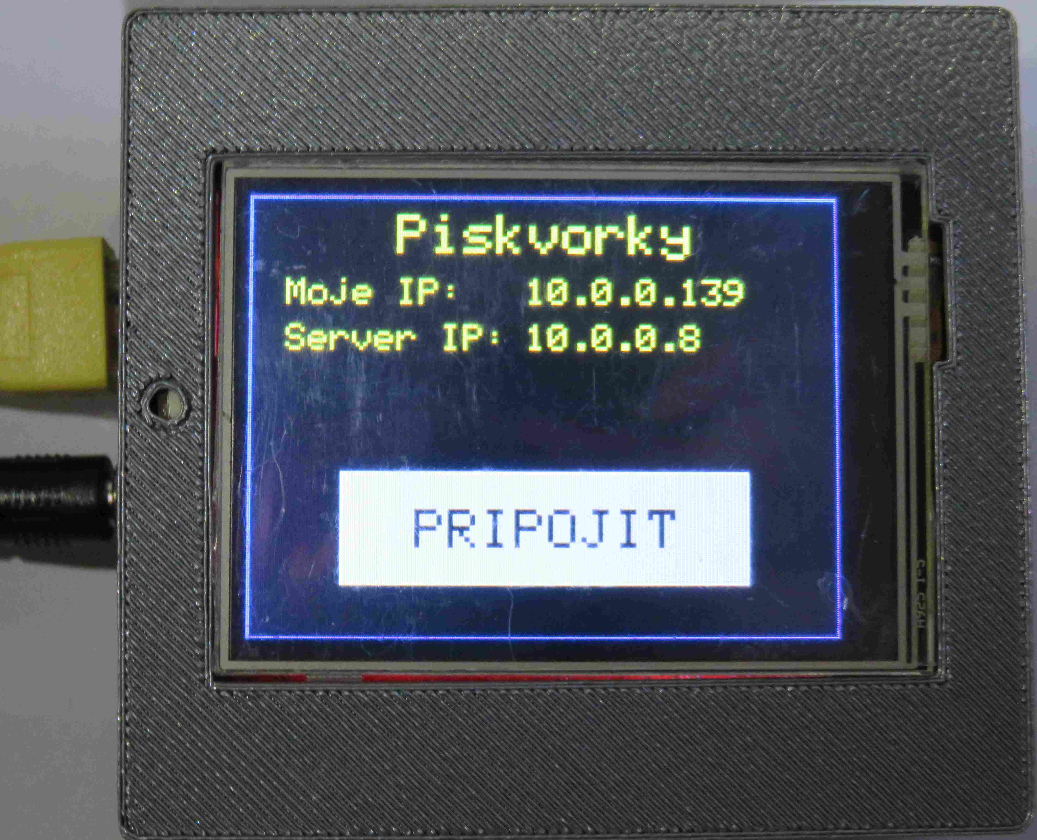
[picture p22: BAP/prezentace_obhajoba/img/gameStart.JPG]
		
		\caption{Obrazovka klienta po spuštění}
	\end{figure}
	
	Hl. obrazovka -> připojování -> připojeno -> hra -> oznámení o~ukončení -> připojeno
	
%
 \column{.5\textwidth}
 	\begin{figure}
		\centering
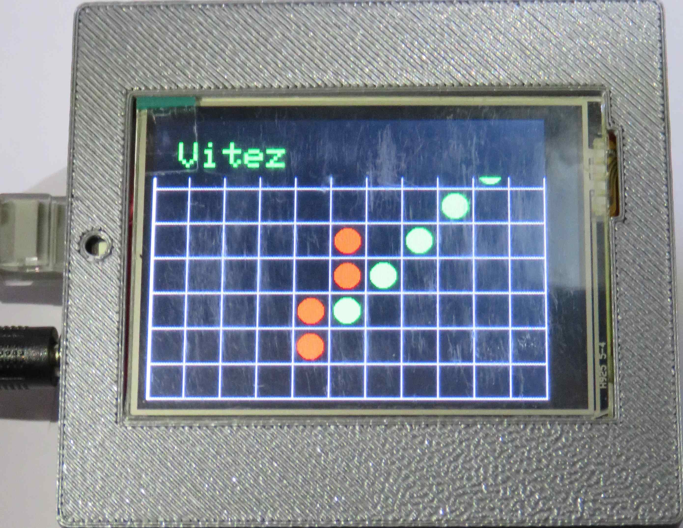
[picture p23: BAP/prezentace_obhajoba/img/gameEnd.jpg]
		
		\caption{Obrazovka klienta - konec hry}
	\end{figure}
	
	Políčka 5x5 mm - stylus i prst
	\vspace{.9cm}
 		
\end{columns}
\end{frame}

\subsection{Komunikace}
\begin{frame}
\frametitle{Komunikace server - klient}
\begin{itemize}
	\item Přenos pomocí pole (136 bajtů)
	\item Obsah:
	\begin{itemize}
		\item obsazenost jednotlivých políček
		\item řídicí kód
		\item počet odehraných kol
		\item číslo klienta na tahu
		\item barvy klientů
		\item IP adresy klientů
	\end{itemize}
	 \item Odesílání: 
	 \begin{itemize}
	 	\item rozděleno na pole po 8 bajtech
	 	\item vybaveno pořadovým číslem
	 	\item zabezpečeno kontrolním součtem
	 \end{itemize}
	 \item Pokud nesedí kontrolní součet, klient si může vyžádat znovuodeslání
\end{itemize}
\end{frame}

\begin{frame}
\frametitle{Komunikace klient - server}
\begin{itemize}
	\item Přenos pole (2 bajty)
	\item Řídicí kód a daná informace
	\item Pole se odesílá 2x, na straně serveru se porovnává
\end{itemize}

\begin{table}
	\centering
	\caption{Rozložení pole pro komunikaci klient - server}
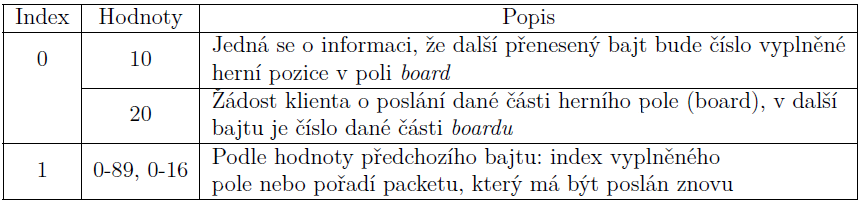
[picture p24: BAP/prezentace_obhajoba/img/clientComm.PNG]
	
\end{table}
\end{frame}

\section{Diskuze a ukázka}
\begin{frame}
\begin{center}
\vspace*{1cm}
{\bf Děkuji za pozonost!}\\
\vspace*{1.2cm}
{\bf\Large \FirstName{} \LastName{}}\\
{\tt \Email} \\[1em]
Stránka projektu na GitHubu: \\
\url{https://github.com/janzavorka/BP_PROJ}
\vspace*{1cm}
\end{center}
\end{frame}

\appendix

\section{Otázka 1}
\begin{frame}
\frametitle{Využití PoE (Power over Ethernet)}
Možnosti pro klientské zařízení:
\begin{itemize}
	\item deska Arduino Ethernet má přípravu pro PoE (existují varianty osazeným PoE modulem)
	\only<2->{
		\item Modul s výstupním napětí 5~V nebo 12~V (resp. 5,5~V a 12,5~V)
		\item Výstup PoE modulu napojen na vstup lin. stabilizátoru Arduina
	}
\end{itemize}
\only<1>{
	\begin{figure}
		\centering
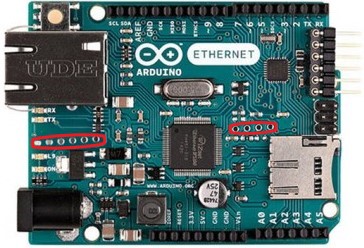
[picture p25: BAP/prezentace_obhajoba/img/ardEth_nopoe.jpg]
		
		\caption{Arduino Ethernet s označenými piny pro připojení PoE modulu}
	\end{figure}
}

\only<2>{
	\refstepcounter{figure}
	\begin{figure}
		\centering
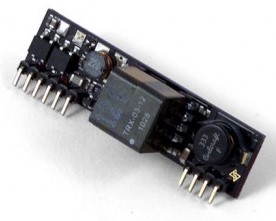
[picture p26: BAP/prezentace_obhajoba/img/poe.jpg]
		
		\caption{Modul PoE pro Arduino}
	\end{figure}
}

\only<3->{
Problémy:
\begin{itemize}
	\item 5~V modul - úbytek na lin. stab. $\approx 0,8~V$: reference pro displej
	\item 12~V modul - stabilizátor nezvládá velký ztrátový výkon (odběr 350~mA)
\end{itemize}
}
\end{frame}

%\begin{frame}
%\frametitle{Využití PoE (Power over Ethernet)}
%Pro server:
%\begin{itemize}%
%	\item Ethernet shield s PoE
%	\item Nutný switch s podporou PoE
%	\item PoE čistě pro server zbytečné
%\end{itemize}
%\end{frame}

\end{document}

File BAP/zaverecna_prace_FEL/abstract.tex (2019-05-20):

\section*{Abstrakt}
Tato bakalářská práce se zabývá vývojem a výrobou jednoduchých zařízení, která umožňují demonstrovat využití energeticky nenáročných zařízení v~IoT sítích. Propojená zařízení mají podobu jednoduché hry pro více hráčů~-~piškvorek a je postaveno na platformě Arduino. Vzniklá síť je tvořena až pěti koncovými zařízeními (klienty) s~dotykovými displeji pro interakci s uživatelem a jednoho centrálního řídicího prvku (serveru). V práci je popsán konkrétní použitý hardware, včetně návrhu krabiček. Dále je zde podrobně rozepsán vytvořený software, včetně možnosti úprav pro použití s~jinými moduly. Nakonec je uveden i návod na oživení a obsluhu.\\

\vspace{.5cm}
\noindent
Klíčová slova: Arduino Ethernet, IoT demonstrátor, Arduino hra, Arduino IoT

\section*{Abstract}
{
\selectlanguage{english}
This bachelor thesis deals with the development and production of a simple devices which can demonstrate usage of low power devices in~IoT networks. This network of devices have a form of the multiplayer game - Noughts and crosses, and it is based on Arduino platform. The network have up to five end nodes (clients) with touch screen for~interaction with the user and one control device (server).  There is described used hardware including design of cases for all devices in this thesis. There is also a~description of software including a~list of possible changes which could be made for the purpose to use this product with different modules. In the end, there is a manual for~starting and operating this devices.

\vspace{.5cm}
\noindent
Key words: Arduino Ethernet, IoT demonstration device, Game based on Arduino, Arduino IoT
}

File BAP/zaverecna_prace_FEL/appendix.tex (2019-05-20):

\appendix
\section{Soubor s daty}
Součástí této práce je i soubor \uv{zavorja4\_BP\_priloha.zip} s zdrojovými kódy a dalšími daty. Soubor má následující strukturu:
\vspace*{.5cm}
\noindent
%
\setlength{\DTbaselineskip}{20pt}
\DTsetlength{1em}{2em}{0.1em}{1pt}{4pt}
\dirtree{%
.1 zavorja4\_BP\_priloha  .
.2 {bakalarska\_prace\_JanZavorka.pdf}.
.2 soubory\_krabicek.
.3 klient.
.4 {case\_bottom.stl}.
.4 {case\_top.stl}.
.3 server.
.4 {case\_bottom.stl}.
.4 {case\_top.stl}.
.2 zdrojove\_kody.
.3 piskvorky\_MP\_client \makebox[1cm]{\dotfill} \begin{minipage}[t]{5cm}\fontfamily{cmr}\selectfont\textit{Zdrojové kódy pro klienta, pro správné fungování musí být zachován název složky a souborů uvnitř}{.}
\end{minipage}
.
.4 {piskvorky\_MP\_client.ino}.
.4 {displayControl.ino}.
.4 {gameControl.ino}.
.4 {communication.ino}.
.3 piskvorky\_MP\_server\makebox[1cm]{\dotfill} \begin{minipage}[t]{5cm}\fontfamily{cmr}\selectfont\textit{Zdrojové kódy pro server, pro správné fungování musí být zachován název složky a souborů uvnitř}{.}
\end{minipage}.
.4 {piskvorky\_MP\_server.ino}.
.4 {boardControl.ino}.
.4 {gameControl.ino}.
.4 {communication.ino}.
.4 {indicationLED.ino}.
.4 {SerialControl.ino}.
}%
%

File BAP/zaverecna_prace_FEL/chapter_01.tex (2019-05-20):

\section{Hardware}
Celá platforma se skládá z jednoho řídicího prvku (viz. kapitola~\ref{sec:HWserver}) a třech klientských zařízení (viz. kapitola~\ref{sec:HWclient}), přičemž maximální počet je softwarově omezen na pět. Při~použití s WIZnet W5100 kontrolérem na straně serveru lze maximálně připojit čtyři klienty. Datové spojení je realizováno hvězdicovou topologií (schéma na obrázku~\ref{fig:schema_net}). Jako centrální prvek byl použit switch \mbox{D-Link DGS-105}.
Celá demonstrační sestava se~pak skládá z:
\begin{itemize}
  \item 1x switch D-Link DGS-105
  \item 1x server s Arduino DUE
  \item 3x klient s Arduino Ethernet a dotykovým displejem
  \item 4x propojovací UTP kabel
  \item 1x napájecí adaptér pro switch (5 V/1 A součástí balení)
  \item 4x napájecí adaptér 12 V/1500 mA
\end{itemize}

\begin{figure}[hbtp]
  \centering
  
  \caption{\label{fig:schema_net} Schéma zapojení jednotlivých zařízení do sítě, zdroj \cite{fig_ArdEthernet, fig_ArdEthShield, fig_switchIco, fig_ArdDue}}
\end{figure}

\subsection{Zařízení typu server}
\label{sec:HWserver}
Zařízení je založeno na desce \textit{Arduino Due}. Tato deska  obsahuje mikrokontrolér\linebreak\mbox{Atmel SAM3X8E ARM Cortex-M3} s 512 kB flash paměti a nabízí dostatečný výkon pro správné fungování serveru. Původní varianta totiž počítala s nasazením desky \mbox{\textit{Arduino Ethernet}} i jako serveru. To se ovšem vzhledem k omezeným prostředkům ukázalo jako problematické, proto byla zvolena právě deska \textit{Arduino Due}.

Pro připojení do sítě je použit Ethernetový shield s čipem Wiznet W5100, který je přímo napojen na Arduino. Tímto je dána ona limitace maximálně na 4 hráče, protože dle datasheetu výrobce čipu~\cite{datasheet_w5100} je maximální počet spojení právě čtyři. Ethernetový shield komunikuje s Arduinem pomocí SPI sběrnice. V některých verzích Arduino Ethernet shieldu (především neoficiálních klonů) se objevují problémy se startem samotného shiledu. Stejným problémem trpěl i shiled použitý v této práci, podrobný popis problému a použité funkční řešení je popsané v kapitole \ref{sec:ArdShiel_mod}.

Pro pohodlné ovládání jsou k serveru připojena dvě tlačítka a jedna barevná svítivá dioda. Význam jednotlivých stavů svítivé diody a funkce tlačítek je popsána v kapitole~\ref{sec:ovladani}. Propojení těchto periferií s Arduinem je realizováno pomocí jednostranné DPS, schéma zapojení je pak na obrázku~\ref{fig:server_module}.

\begin{figure}[hbtp]
  \centering
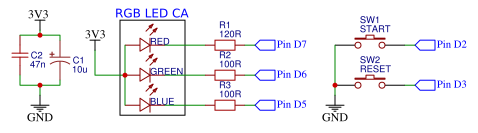
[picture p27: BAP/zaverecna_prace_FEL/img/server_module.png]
  
  \caption{\label{fig:server_module} Schéma zapojení periferií u serveru}
\end{figure}

Napájení je řešeno externím adaptérem. Dle stránek výrobce~\cite{ArdDue_web} je možné použít napětí 6~-~16~V (využívá se interní stabilizátor), přičemž odběr je kolem 140~mA při~napájení 12~V. V případě, že je pro ovládání použita sériová linka (server je připojen USB kabelem k počítači, ovládání tímto způsobem je popsáno v~kapitole~\ref{sec:ovladani}), postačuje napájení dodané přes USB kabel a není potřeba připojovat externí napájecí zdroj.

Celé zařízení je pak umístěno v krabičce, jejíž návrh je na~obrázku~\ref{fig:server_navrh} a realizace na~obrázku~\ref{fig:server_realizace}. Krabička byla navržena v programu Autodesk Inventor Professional 2019 Student Edition a realizovaná 3D tiskem na tiskárně Original Prusa i3 MK3S. Krabička je osazena červeným a zeleným tlačítkem, barevnou svítivou 5~mm diodou (se společnou anodou) a souosým napájecím konektorem 5,5x2,1~mm. Pro upevnění Arduina jsou použity šrouby M2,5x10 a závitové vložky M2,5x6 vtavené do připravených otvorů v~krabičce. Arduino deska sice nabízí montážní otvory o~průměru 3~mm, ale vzhledem k~rozložení součástek zde není dostatek místa pro hlavu šroubu~M3.

\subsection{Úprava Ethernet shieldu}
\label{sec:ArdShiel_mod}
Některé Arduino shieldy založené na kontroléru WIZnet (především neoficiální klony) mají problém se správný startem. Problém se projevuje tak, že při zapnutí napájení nedojde ke správnému připojení do sítě (indikační svítivé diody na shiledu sice blikají, ale Ethernet shield není k síti připojen). Tento problém se projevil pouze v případě, kdy bylo Arduino napájeno externím zdrojem (při připojení přes USB k počítači vše fungovalo normálně). Správné připojení k síti pak nastalo pouze pokud bylo stisknuto tlačítko \textit{RESET} na Ethernet shieldu.

Dle webu~\cite{EthShieldError} je problém způsoben krátkým resetovacím časem Arduina. Existuje několik způsobů, jak tento problém vyřešit. Pro Ethernet shield použitý v této práci byla aplikována metoda popsaná~v~\cite{EthShieldModification}. Nejdříve bylo potřeba izolovat reset shieldu od resetu Arduina. To bylo provedeno odstřihnutím pinu \textit{Reset} na Ethernet shieldu a~odvrtáním prokovky, která vede resetovací signál z ICSP konektoru. Dále byl připojen rezistor $10 \ \mathrm{k\Omega}$ mezi pin \textit{Reset} a napájecí pin 3,3 V. Nakonec byl připojen kondenzátor o kapacitě $1 \ \mathrm{\mu F}$ mezi pin \textit{Reset} a zem (pin \textit{Gnd}). Tímto způsobem byl daný problém vyřešen.

\begin{figure}[hbtp]
\centering
\begin{minipage}[c]{\textwidth/2-.7cm}

\end{minipage}
\begin{minipage}[c]{\textwidth/2-.7cm}

\end{minipage}
\\
\begin{minipage}[c]{\textwidth/2-0.5cm}
\caption{\label{fig:server_navrh}Návrh krabičky pro server\newline}
\end{minipage}
\begin{minipage}[c]{\textwidth/2-.5cm}
\caption{\label{fig:server_realizace}Zkompletovaná krabička pro server}
\end{minipage}
\end{figure}

%\begin{figure}[hbtp]
%  \centering
%  \includegraphics[height=7cm]{img/foto/server_navrh.png}
%  \caption{\label{fig:server_navrh}Návrh krabičky pro server}
%\end{figure}

%\begin{figure}[hbtp]
%  \centering
%  \includegraphics[height=7cm]{img/foto/server_realizace.jpg}
%  \caption{\label{fig:server_realizace}Zkompletovaná krabička pro server}
%\end{figure}

%\newpage
\subsection{Zařízení typu klient}
\label{sec:HWclient}
Zařízení je založeno na desce Arduino Ethernet, která je vybavena mikrokontrolérem ATmega328 s 32 kB flash pamětí. Tato deska byla zvolena především kvůli tomu, že má vestavěný ethernetový kontrolér, který tak nezabírá piny pro připojení shieldu s displejem. Malá flash paměť se však během vývoje ukázala jako značně limitující, protože při nahrání všech potřebných knihoven (popsáno v kapitole~\ref{sec:knihovny}) zůstalo k dispozici 30~\% programové paměti. I z tohoto důvodu byla zvolena jako hra piškvorky, která není programově příliš složitá a také bylo nutné vynechat složitější menu například s~nastavením barvy nebo změny IP adresy serveru (to se nyní musí provádět změnou v kódu a přeprogramováním Arduina, více v~kapitole~\ref{sec:client-nastaveni}).

Jak už bylo zmíněno výše, tato deska má vestavěný ethernet kontrolér WIZnet, konkrétně typ W5100. U klienta není maximální počet spojení limitující, klient drží pouze jedno spojení se serverem. Jedinou nevýhodou kontroléru W5100 tak zůstává, že~neobsahuje registr, ve kterém je uložena informace o fyzickém připojení ethernetového kabelu k desce~\cite{datasheet_w5100}. Tím je zkomplikována detekce připojení a odpojení kabelu a zůstává tak pouze možnost vizuální kontroly pomocí svítivých diod na konektoru RJ-45.

Pro interakci s uživatelem je klient vybaven $2,4^{\prime\prime}$ barevným TFT LCD displej s~rozlišením 320x240 pixelů s~rezistivní dotykovou plochou. Displej je vybaven  řadičem SUM74HC245T. Vzhledem k rozměrům (výšce) RJ-45 konektoru, který je umístěn na~desce, je nutné pro správné připojení použít lištu s oboustrannými kolíky o délce kolíku minimálně 15~mm. Protože u displejů použitých v tomto projektu byly kolíky připájeny už od výrobce, byla dodatečně vyrobena patice z dutinkové lišty a lišty s~oboustrannými kolíky.

Pro napájení byl zvolen externí napájecí adaptér. Připojení na integrovaný stabilizátor není možné, protože Arduino s displejem při 5~V odebírá přibližně 400~mA, což integrovaný stabilizátor nedokáže poskytnout (vlivem velkého ztrátového výkonu dochází k jeho značnému zahřívání). Napájení přímo napětím 5~V není také příliš vhodné, neboť vlivem například ztrát přívodních vodičů může dojít ke kolísání napětí, čímž dojde i k pohybu reference AD převodníku připojenému k dotykové vrstvě displeje a~tak~může docházet k nesprávnému vyhodnocení stisku (může se lišit reálné místo stisku od~toho, které vyhodnotil mikrokontrolér). Jako nejlepší varianta se ukázalo použití modulu se snižujícím DC-DC měničem. Modul obsahuje spínací regulátor MP1584 a~dle dodavatele je schopen pracovat s napětím 6~-~25~V (při výstupním napětí 5~V) a~dodat proud až 1,5~A, což je pro tuto aplikaci dostačující.

Stejně jako v případě serveru je celé zařízení umístěno ve vytištěné krabičce, návrh a realizovaná krabička jsou na obrázcích \ref{fig:client_navrh}, \ref{fig:client_realizace}. Princip uchycení Arduina je stejný jako v případě serveru, pro napájení je opět osazen souosý napájecí konektor 5,5x2,1~mm. Dále je z boku výřez pro konektor RJ-45 pro připojení do ethernetové sítě a na vrchu se nachází výřez pro displej, vedle kterého je umístěn otvor pro přístup k resetovacímu tlačítku.

\begin{figure}[hbtp]
\centering
\begin{minipage}[c]{\textwidth/2-1cm}

\end{minipage}
\begin{minipage}[c]{\textwidth/2-1cm}

\end{minipage}
\\
\begin{minipage}[c]{\textwidth/2-0.5cm}
\caption{\label{fig:client_navrh}Návrh krabičky pro klienta\newline}
\end{minipage}
\begin{minipage}[c]{\textwidth/2-.5cm}
\caption{\label{fig:client_realizace}Zkompletovaná krabička pro klienta}
\end{minipage}
\end{figure}

%\begin{figure}[hbtp]
%  \centering
%  \includegraphics[height=7cm]{img/foto/client_navrh.png}
%  \caption{\label{fig:client_navrh}Návrh krabičky pro klienta}
%\end{figure}

%\begin{figure}[hbtp]
%  \centering
%  \includegraphics[height=7cm]{img/foto/client_realizace.jpg}
%  \caption{\label{fig:client_realizace}Zkompletovaná krabička pro klienta}
%\end{figure}

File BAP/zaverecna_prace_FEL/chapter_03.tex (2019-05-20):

\section{Oživení a obsluha}
\label{sec:ovladani}
Příprava ke spuštění probíhá v několika krocích:
\begin{enumerate}
  \item Připraví se centrální jednotka (v tomto případě switch) a k ní se pomocí síťového kabelu připojí všechna zařízení (klienti i server). Zapojení je znázorněno na obrázku~\ref{fig:schema_net}.

  \item Připojit napájení k serveru i klientům, pro server napájení 6~-~16~V~DC schopné dodat alespoň 250~mA, pro klienty 6~-~25~V~DC alespoň 500~mA.

  \item Pokud je vše v pořádku, na serveru svítí svítivá dioda modrou barvou a na displejích klientů je úvodní obrazovka s tlačítkem \uv{\textit{PRIPOJIT}} (viz. obrázek~\ref{fig:faze1}).
\end{enumerate}

\subsection{Ovládání klienta}
\begin{enumerate}
\item Po úspěšném zapnutí se vykreslí úvodní obrazovka (obrázek~\ref{fig:faze1}).  Zobrazeny jsou informace o nastavené IP adrese serveru a o IP adrese klienta (podle režimu přiřazena DHCP serverem nebo ručně).
\begin{figure}[H]
\centering

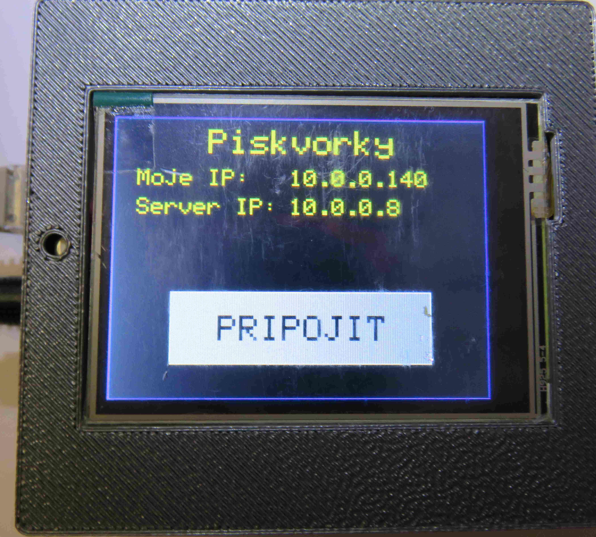
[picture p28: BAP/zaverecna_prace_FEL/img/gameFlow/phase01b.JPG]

\caption{\label{fig:faze1} Obrazovka dvou klientů po úspěšném spuštění}
\end{figure}

%%%
\item Připojení k piškvorkovému serveru lze spustit stisknutím tlačítka \uv{\textit{PRIPOJIT}}. Připojování je indikováno pomocí displeje (obrázek~\ref{fig:faze2}). Připojování může být kdykoliv přerušeno stiskem tlačítka \uv{\textit{PRERUSIT}}. Připojování bude dokončeno pokud na serveru není rozehraná hra.
\begin{figure}[H]
\centering


\caption{\label{fig:faze2} Obrazovka dvou klientů při připojování k serveru}
\end{figure}

%%%
\item Pokud připojení proběhlo úspěšně, klient má od serveru přiřazené číslo a barvu. To je indikováno pomocí displeje (obrázek~\ref{fig:faze3}), kde barva textu odpovídá barvě hráče. Než započne hra je možné se ze serveru odpojit stiskem tlačítka \uv{\textit{ODPOJIT}}. Jinak se čeká na zahájení hry.
\begin{figure}[H]
\centering


\caption{\label{fig:faze3} Obrazovky dvou různých klientů  po úspěšném připojení k piškvorkovému serveru}
\end{figure}
\label{item:faze3}

%%%
\item V případě, že ze strany serveru byla započata hra (příkazem nebo stiskem zeleného tlačítka na serveru), vykreslí se na obrazovce herní pole (obrázek~\ref{fig:faze4}).

Jednotlivé čtverce mají pro tento typ displeje fyzický rozměr přibližně 0,5x0,5~mm. Tato velikost byla zvolena proto, že je možné na takto malý displej umístit dostatečně velké pole (11x8 čtverců) a zároveň je možné jej bez problémů ovládat stylusem a případně i prstem.
\begin{figure}[H]
\centering


\caption{\label{fig:faze4} Obrazovka klienta po započaté hře (a) čekající hráč, (b) hrající hráč}
\end{figure}

%%
\item Během hry: pokud je mřížka šedá, hraje jiný hráč; pokud má mřížka nějakou barvu (barva se shoduje s barvou hráče), je na tahu daný hráč. Ten má za úkol stiskem libovolného volného čtverečku umístit svůj žeton.

Když uživatel stiskne čtverec, dojde k jeho vyplnění příslušným žetonem (barevným kruhem), mříž zešedne a je na řadě další hráč. Rozehraná hra je vidět na~obrázku~\ref{fig:faze5}.
\begin{figure}[H]
\centering


\caption{\label{fig:faze5} Rozehraná hra dvou hráčů}
\end{figure}

%%
\item Hráči se střídají do té doby než: jsou všechna pole vyplněna (ukončeno remízou) nebo některý hráč spojil požadovaný počet žetonů (v základním nastavení pět~žetonů). O výsledku hry jsou hráči informováni hláškou na displeji (obrázek~\ref{fig:faze6}). Tato hláška po deseti sekundách zmizí (nastaveno v proměnné \texttt{clientMessageLast} v milisekundách) a hra přechází do fáze~3.
\begin{figure}[H]
\centering


\caption{\label{fig:faze6} Zobrazená hláška na displeji (a) výherce a (b) ostatních hráčů, barva textu se shoduje s barvou vítězného hráče}
\end{figure}
\end{enumerate}
%\notFinished
\subsection{Ovládání serveru}
Server lze ovládat dvěma způsoby. Prvním z nich je ovládání pomocí dvou tlačítek.

Pokud je stisknuto červené tlačítko, dojde k přerušení aktuálně běžící hry (dosavadní stav hry je resetován).

Pokud je stisknuto zelené tlačítko a neběží hra (indikační LED svítí modře) - stiskem tlačítka dojde ke spuštění hry (s ověřením zda je k dispozici dostatek hráčů).
Pokud hra již běží (indikační LED svítí zeleně) stiskem zeleného tlačítka dojde k posunutí tahu na dalšího hráče.

Druhým způsobem ovládání je posílání příkazů přes sériovou linku. V tomto případě je nutné servem připojit k počítači pomocí microUSB kabelu (konektor z přední strany serveru). K zobrazení dat lze použít nástroj \textit{Serial monitor} přímo v~Arduino~IDE nebo například sériový terminál \textit{RealTerm \footnote{Domovská stránka: https://realterm.sourceforge.io/}}. Nastavení je následují: rychlost = 9600 baudů, Data bits = 8, Stop bits = 1, Flow control = none.  Každý příkaz musí být zakončen novým řádkem (LF). Seznam příkazů je v tabulce \ref{tab:server_prikazy}.

Informování uživatele o stavu serveru je realizováno pomocí barevné svítivé diody. Význam jednotlivých stavů je v tabulce \ref{tab:serverLED}. Symboly:  svítivá dioda svítí,  svítivá dioda bliká.

\input{tables/serverCommands.tex}

\input{tables/serverLED.tex}
%\notFinished

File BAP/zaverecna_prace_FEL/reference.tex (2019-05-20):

\renewcommand{\refname}{Reference}
\addcontentsline{toc}{section}{Reference}
\begin{thebibliography}{30}
\hypersetup{urlcolor=black}

\bibitem{iot_geographic}
  Internet of Things (IoT) Protocols and Connectivity Options: An Overview. \textit{SaM Solutions} [online]. SaM Solutions, c1993-2019, 22.8.2019 [cit. 2019-05-17]. Dostupné z: \url{https://www.sam-solutions.com/blog/internet-of-things-iot-protocols-and-connectivity-options-an-overview/}

  \bibitem{datasheet_w5100}
  W5100 Datasheet. \textit{WIZnet} [online]. c2009-2011, 8.1.2016 [cit. 2019-05-05]. Dostupné z: \url{https://www.wiznet.io/wp-content/uploads/wiznethome/Chip/W5100/Document/W5100\_Datasheet\_v1.2.7.pdf}

  \bibitem{ArdIotDDOS}
  IAM\_MAKER\_LEO. How to Make Unattackable Secure Arduino IoT Device. \textit{Instructables circuits} [online]. Autodesk, c2019 [cit. 2019-05-17]. Dostupné z: \url{https://www.instructables.com/id/How-to-make-unattackable-secure-arduino-IoT-device/}

  \bibitem{IoTprotocols}
MEHEDI, Hasan. Top 15 Standard IoT Protocols That You Must Know About. \textit{UbuntuPIT} [online]. c2017-2019 [cit. 2019-05-17]. Dostupné z:\\ \url{https://www.ubuntupit.com/top-15-standard-iot-protocols-that-you-must-know-about/}

\bibitem{fig_ArdEthernet}
Fritzing Parts: Arduino\_Ethernet. In: \textit{Paulvollmer} [online]. c2018, 2013 [cit. 2019-05-05]. Dostupné z: \url{https://paulvollmer.net/FritzingParts/parts/Arduino\_Ethernet.html}

\bibitem{fig_ArdEthShield}
Using the SD library to create and remove files on a SD card. In: \textit{Arduino} [online]. c2019, 2015/08/18 [cit. 2019-05-05]. Dostupné z: \url{https://www.arduino.cc/en/tutorial/files}

\bibitem{fig_switchIco}
Lan Switch Icon \#83279. In: \textit{Free Icons Library} [online]. c2018-2019 [cit. 2019-05-05]. Dostupné z: \url{http://chittagongit.com/icon/lan-switch-icon-25.html}

\bibitem{fig_ArdDue}
Fritzing Parts: Arduino\_DUE\_V02b. In: \textit{Paulvollmer} [online]. c2018, 2013 [cit. 2019-05-05]. Dostupné z: \url{https://paulvollmer.net/FritzingParts/parts/Arduino\_DUE\_V02b.html}

\bibitem{ArdDue_web}
Arduino store: ARDUINO DUE. \textit{Arduino} [online]. c2019 [cit. 2019-05-05]. Dostupné z: \url{https://store.arduino.cc/due}

\bibitem{EthLib}
Arduino: Ethernet library. \textit{Arduino} [online]. c2019 [cit. 2018-12-18]. Dostupné z: \url{https://www.arduino.cc/en/Reference/Ethernet}

\bibitem{lib_MCUFRIEND_kbv}
PRENTICEDAVID. MCUFRIEND\_kbv library. In: \textit{Github} [online]. c2019 [cit. 2019-02-05]. Dostupné z: \url{https://github.com/prenticedavid/MCUFRIEND\_kbv}

\bibitem{lib_adafruitGFX}
BURGESS, Phillip. Adafruit GFX Graphics Library: Overview. \textit{Adafruit} [online]. 29.6.2012 [cit. 2019-05-08]. Dostupné z: \url{https://learn.adafruit.com/adafruit-gfx-graphics-library/overview}

\bibitem{lib_touch}
ADAFRUIT. Adafruit\_TouchScreen library. \textit{Github} [online]. c2019 [cit. 2019-02-05]. Dostupné z: \url{https://github.com/adafruit/Adafruit\_TouchScreen}

\bibitem{lib_simpleTimer}
ROMANI, Marcello. SimpleTimer Library for Arduino. \textit{Arduino} [online]. c2019 [cit. 2019-05-08]. Dostupné z: \url{https://playground.arduino.cc/Code/SimpleTimer/}

\bibitem{norm_RFC6335}
IETF [INTERNET ENGINEERING TASK FORCE], IANA [INTERNET ASSIGNED NUMBERS AUTHORITY]. \textit{Service Name and Port Number Procedures: rfc6335, BCP165}. 2011, 33~s. ISSN: 2070-1721. Dostupné také z: \url{https://tools.ietf.org/html/rfc6335}

\bibitem{vyberMAC}
MALÝ, Martin. Arduino: webový server i klient do ruky. \textit{Root.cz} [online]. 27. 7. 2010 [cit. 2019-02-06]. Dostupné z: \url{https://www.root.cz/clanky/arduino-webovy-server-i-klient-do-ruky/}

\bibitem{ard_unsignedChar}
Arduino: unsigned char. \textit{Arduino} [online]. c2019 [cit. 2019-05-16]. Dostupné z: \url{https://www.arduino.cc/reference/en/language/variables/data-types/unsignedchar/}

\bibitem{EthShieldError}
Wiznet W5100 Ethernet Shield. \textit{HOBBYIST.CO.NZ} [online]. [cit. 2019-05-16]. Dostupné z: \url{https://www.hobbyist.co.nz/?q=ethernet-shield-w5100}

\bibitem{EthShieldModification}
MARCO. \textit{Arduino Wiznet ethernet shield proper reset} [online]. 22.12.2010 [cit. 2019-05-16]. Dostupné z: \url{https://marco.guardigli.it/2010/11/arduino-wiznet-ethernet-shield-proper.html}

\end{thebibliography}

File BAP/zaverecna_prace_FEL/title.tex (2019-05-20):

%%Uvodni stranka
\definecolor{cvutcolor}{cmyk}{1, 0.43, 0, 0} %modra CVUT
\newlength{\titlewidth}
\setlength{\titlewidth}{\textwidth}
\addtolength{\titlewidth}{-1.7cm}
\newlength{\heightofhw}

\newcommand{\TitlePage}[3]{{
	\thispagestyle{empty}
	\parbox{0.7cm}{\color{cvutcolor}\rule{0.35cm}{\textheight}}
	{\parbox[0][\textheight][t]{\titlewidth}{
		\sffamily
		%\vspace{1pt}
		\\[0.5em]
		%\put(10,40){\parbox{8cm}{\Large  \textbf{České}\\[0.3em] \textbf{vysoké učení}\\[0.3em] \textbf{technické}\\[0.3em] \textbf{v Praze}\\[.6em]}} \\[.1em]
		\textbf{\Large
			\color{cvutcolor} Fakulta Elektrotechnická \\[0.3em]
			\color{black} Katedra radioelektroniky
		}\\[6em]
		\color{black}{\Large \textbf{Bakalářská práce}}\\[0.8em]
		{\huge \textbf{#2}}\\[0.8em]
		{\Large \textbf{#3}}\\[0.8em]
		
		\vspace*{1.5cm}
		\color{cvutcolor}{\Large \textbf{#1}}\\[0.8em]

		\vspace*{1cm}
		~\vfill

		\textbf{\large
			\color{black} Vedoucí práce:
		\color{cvutcolor} Ing. Stanislav Vítek, Ph.D.
		}\\[0.2cm]
		\textbf{\large
 			\color{black} Studijní program:
 			\color{cvutcolor}  Elektronika a komunikace
		}\\[0.2cm]
		\textbf{\Large \color{black} Praha, \todayMonthYear}
		\vspace{2pt}
	}}
	\newpage
}}

% \begin{titlepage}
% \pagestyle{empty}

% \begin{minipage}{95mm}
% 	\vspace{1mm}
% 	\includegraphics[height=20mm]{images/logo_mmtg.pdf}\\
% 	\textsc{\scriptsize Department of Radioelectronics}\\
% \end{minipage}
% \begin{minipage}{60mm}
% 	\includegraphics[height=21mm]{images/logo_fee.pdf}\\
% 	\textsc{\scriptsize Doctoral program in Radioelectronics}\\
% \end{minipage}\\ [2cm]

% \hspace{1cm}\LARGE\textsc{Doctoral Thesis Proposal}\\\vspace{10mm}
% \hspace{5mm}{\color{cvut}\rule{15cm}{1mm}}\\\vspace{10mm}
% \hspace{1cm}\parbox[c][2.5cm][c]{13cm}{\Huge\textbf{EMCCD camera image processing}}\\\vspace{15mm}
% \hspace{5mm}{\color{cvut}\rule{15cm}{1mm}}

% \vspace{2cm}\hspace{1cm}
% \LARGE\textsc{Maria Nasyrova}

% \vspace{2cm}\hspace{1cm}
% \begin{minipage}{10cm}
% 	\LARGE
% 	Thesis supervisor
% 	\newline Ing. Stanislav V{í}tek, Ph.D.
% 	\newline CTU in Prague
% \end{minipage}

% \vfill\hspace{1cm}
% \LARGE Prague, September 2018

% \newpage

% \vspace*{1cm}

% \begin{tabular}{ll}
% \large \textbf{Applicant} & \large Ing. Maria Nasyrova\\
% \large  & \large Czech Technical University in Prague\\
% \large  & \large Faculty of Electrical Engineering\\
% \large  & \large Department of Radioelectronics\\
% \large  & \large Technická 2\\
% \large  & \large 166 27, Praha 6\\
% \large  & \large office: +420 224 352 113\\
% \large  & \large email:	 nasyrmar@fel.cvut.cz\\
% \large  & \large \\
% \large  & \large \\
% \large \textbf{Thesis supervisor} & \large Ing. Stanislav V{í}tek, Ph.D.\\
% \large  & \large Czech Technical University in Prague\\
% \large  & \large Faculty of Electrical Engineering\\
% \large  & \large Department of Radioelectronics\\
% \large  & \large Technická 2\\
% \large  & \large 166 27, Praha 6\\
% \large  & \large office: +420 224 352 226\\
% \large  & \large \\
% \large  & \large \\
% \large  & \large \\

% \end{tabular}

% \end{titlepage}

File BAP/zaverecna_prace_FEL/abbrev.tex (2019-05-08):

%\renewcommand*{\glossaryentrynumbers}[1]{}

\newacronym{maia}{MAIA}{Meteor Automatic Imager and Analyze}
\newacronym{ccd}{CCD}{charge-coupled device}
\newacronym{spmn}{SPMN}{SPanish Meteor Nerwork}
\newacronym{cams}{CAMS}{Cameras for Allsky Meteor Surveillance}
\newacronym{cmn}{CMN}{Croatian Meteor Network}
\newacronym{pfn}{PFN}{Polish Fireball Network}
\newacronym{camo}{CAMO}{Canadian Automated Meteor Observatory}
\newacronym{mcp}{MCP}{microchannel plate}
\newacronym{emccd}{EMCCD}{electron multiplying CCD}
\newacronym{cmos}{CMOS}{Complementary Metal–Oxide–Semiconductor}
\newacronym{ebi}{EBI}{Equivalent  Background  Illumination}
\newacronym{snr}{SNR}{signal-to-noise ratio}
\newacronym{psf}{PSF}{point spread function}
\newacronym{fwhm}{FWHM}{full width at half maximum}
\newacronym{nlf}{NLF}{noise level function}
\newacronym{lsd}{LSD}{local standard deviation}
\newacronym{grb}{GRB}{gamma-ray burst}
\newacronym{qe}{QE}{quantum efficiency}
\newacronym{iccd}{ICCD}{intensified CCD} 
\newacronym{fps}{fps}{frame per second}
\newacronym{dfn}{DFN}{Desert Fireball Network}
\newacronym{dsrc}{DSRC}{Digital Single Reflex Camera}
\newacronym{fripon}{FRIPON}{Fireball Recovery and Interplanetary Observation Network}
\newacronym{gpu}{GPU}{Graphic Processing Unit}
\newacronym{cuda}{CUDA}{Compute Unified Device Architecture}
\newacronym{asgard}{ASGARD}{All Sky and Guided Automatic Realtime Detection}
\makeglossaries

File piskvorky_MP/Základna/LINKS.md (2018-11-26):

# List of links to HW parts

### CAD models
- Arduino Ethernet: <https://grabcad.com/library/arduino-ethernet-1>  
    - Not completed, a few differences

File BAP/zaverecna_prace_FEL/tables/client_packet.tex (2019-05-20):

\begin{table}[hbtp]
\catcode`\-=12
\caption{\label{tab:clietn-server} Rozložení packetu pro komunikaci klient - server}
\begin{tabular}{|c|c|l|}
\hline
Index & Hodnoty                         & \multicolumn{1}{c|}{Popis}                                                                                                                                                                                \\ \hline
0     & 10                              & \begin{tabular}[c]{@{}l@{}}Jedná se o informaci, že další přenesený bajt bude číslo vyplněné\\ herní pozice v poli \textit{board}    \end{tabular} \\ \cline{2-3}
      & 20                              & \begin{tabular}[c]{@{}l@{}}Žádost klienta o poslání dané části herního pole (board), v další \\ bajtu je číslo dané části \textit{boardu}   \end{tabular}   \\ \hline
1     & \multicolumn{1}{l|}{0-89, 0-16} & \begin{tabular}[c]{@{}l@{}}Podle hodnoty předchozího bajtu: index vyplněného \\ pole nebo pořadí packetu, který má být poslán znovu\end{tabular}                                                          \\ \hline
\end{tabular}
\end{table}

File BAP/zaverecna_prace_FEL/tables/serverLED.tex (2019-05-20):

\begin{table}[hbtp]
\centering
\newcommand{\LEDsingHeight}{0.55cm}
\caption{Význam stavů svítivé diody na serveru}
\label{tab:serverLED}
\label{tab:LED_man}
\begin{tabular}{|c|c|}
\hline
\textbf{Stav svítivé diody}                                            & \textbf{Význam}                  \\ \hline
             & server je vypnutý/nemá napájení  \\ \hline
              & server je připraven              \\ \hline
 3x   & nový klient připojen             \\ \hline
   3x & klient se odpojil/byl odpojen    \\ \hline
             & aktuálně běží hra                \\ \hline
       & hra ukončena (výhra/remíza)      \\ \hline
 3x      & chyba (nedostatek hráčů pro hru) \\ \hline
 stále   & chyba sítě (připojení kabelu)    \\ \hline
\end{tabular}
\end{table}

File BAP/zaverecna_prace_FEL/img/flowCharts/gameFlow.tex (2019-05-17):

\begin{tikzpicture}[scale=2, node distance = 2cm, auto]
    % Place nodes
  \node (start) [decision] {Přijata data od klienta?};
  \node (codeTest) [decision, below of = start] {Řídicí kód?};

  \node (sendBlock) [block,  right of = codeTest, yshift = 0cm, xshift = 4cm] {Odešli část pole \texttt{board[]}};

  \node (play) [decision, below of = codeTest] {Je daný hráč na tahu?};
  \node (inBoard) [decision, below of = play] {Je pozice mimo herní plán?};
  \node (free) [decision, below of = inBoard] {Je pozice volná?};
  \node (roundsUp) [block, below of = free, text width = 12 em] {počet kol ++ \\ Odešli \texttt{board[]}, kód \uv{2}};
  %\node (1send2) [block, below of = roundsUp] {Odešli \texttt{board[]}, kód \uv{2} };
  \node (playerCheck) [decision, below of = roundsUp, yshift = .5cm] {Spojil hráč daný počet žetonů?};
  \node (roundsCheck) [decision, below of = playerCheck, yshift =- .5cm] {Počet kol >= počet pozic?};

  \node (playerWin) [block, right of = playerCheck, text width = 15 em, xshift = 5cm, yshift = -2cm] {Blikej svítivou diodou \\ Odešli \texttt{board[]}, kód \uv{10x}};

  \node (noWin) [block, right of = roundsCheck, text width = 15 em, xshift = 5cm] {Blikej svítivou diodou \\ Odešli \texttt{board[]}, kód \uv{100}};

    \node (end) [startstop, right of = roundsUp, text width = 15em, xshift = 5cm, , yshift = -2.5cm] {Ukonči hru \\ Odešli \texttt{board[]}, kód \uv{3}
    };

  \node (resend) [block, right of = play, text width = 12 em, xshift = 4.5cm] {Odešli \texttt{board[]} \\ kód \uv{1}};

  \node (nextP) [block, right of = roundsUp, text width = 12 em, xshift = 4.5cm] {Další hráč na tahu, \\ vyplň jeho číslo};

  \node (button) [io, right of = inBoard, text width = 8 em, xshift = 6cm] {Stisknuto zelené tlačítko};

  \draw [Startarrow] ([yshift=.5cm]start.north) -- node[anchor=east] {} (start.north);
  \draw [arrow] (start) -- node[anchor=east] {ANO} (codeTest);
  \draw [arrow] (codeTest) -- node[anchor=east] {10} (play);
  \draw [arrow] (play) -- node[anchor=east] {ANO} (inBoard);
  \draw [arrow] (inBoard) -- node[anchor=east] {NE} (free);
  \draw [arrow] (free) -- node[anchor=east] {ANO} (roundsUp);
  \draw [arrow] (roundsUp) -- node[anchor=east] {} (playerCheck);
  \draw [arrow] (playerCheck) -- node[anchor=east] {NE} (roundsCheck);

  %\draw [line] (roundsCheck.west) -- node[anchor=south] {NE} ([xshift = -.5cm]roundsCheck.west);
  %\draw [line] ([xshift = -.5cm]roundsCheck.west) -- node[anchor=south] {} ([xshift = -.5cm, yshift = +.9cm]start.west);
  %\draw [arrow] ([xshift = -.5cm, yshift = +.9cm]start.west) -- node[anchor=south] {} ([xshift = +.0cm, yshift = 0.3cm]start.north);

  \draw [line] (start.east) -- node[anchor=south] {NE} ([xshift = +.5cm]start.east);
  \draw [line] ([xshift = +.5cm]start.east) -- node[anchor=south] {} ([yshift = +.9cm, xshift = +.5cm]start.east);
  \draw [arrow] ([yshift = +.9cm, xshift = +.5cm]start.east) -- node[anchor=south] {} ([xshift = +.0cm, yshift = 0.3cm]start.north);

  \draw [arrow] (codeTest) -- node[anchor=south] {20} (sendBlock);
  \draw [line] (sendBlock.north) -- node[anchor=south] {} ([yshift = +.9cm, xshift = +1.8cm]start.east);
  \draw [arrow] ([yshift = +.9cm, xshift = +1.8cm]start.east) -- node[anchor=south] {} ([yshift = +.9cm, xshift = +.5cm]start.east);

  \draw [arrow] (play) -- node[anchor=south] {NE} (resend);

  \draw [arrow] (roundsCheck) -- node[anchor=south] {ANO} (noWin);

  \draw [arrow] (playerCheck) -- node[anchor=south west] {ANO} (playerWin.west);
  \draw [arrow] (playerWin) -- node[anchor=south west] {} (end);

  \draw [arrow] (inBoard) -| node[anchor=south east] {ANO} ([xshift = -1.1cm]resend.south);
  \draw [arrow] (free) -| node[anchor=south east] {NE} ([xshift = -0.8cm]resend.south);
  \draw [arrow] (nextP.north) -| node[anchor=south east] {} ([xshift = -0.5cm]resend.south);

  \draw [line] (noWin.east) -- node[anchor=south] {} ([xshift = 0.3cm]noWin.east);
  \draw [line] ([xshift = 0.3cm]noWin.east) -- node[anchor=south] {} ([xshift = 0.3cm]end.east);
  \draw [arrow] ([xshift = 0.3cm]end.east) -- node[anchor=south] {} (end.east);

  \draw [arrow] (button) -- node[anchor=south] {} ([xshift = 0.7cm]nextP.north);

  \draw [line] (roundsCheck.south) -- node[anchor=west] {NE} ([yshift = -0.2cm]roundsCheck.south);
  \draw [line] ([yshift = -0.2cm]roundsCheck.south) -- node[anchor=south] {} ([yshift = -.8cm, xshift = 0.6cm]noWin.east);
  \draw [line] ([yshift = -.8cm, xshift = 0.6cm]noWin.east) -- node[anchor=south] {} ([yshift = 0cm, xshift = 1.2cm]nextP.east);
  \draw [arrow] ([yshift = 0cm, xshift = 1.2cm]nextP.east) -- node[anchor=south] {} ([yshift = 0cm, xshift = 0cm]nextP.east);

  \draw [line] ([xshift = .8cm]resend.north) -- node[anchor=west] {} ([yshift = +.9cm, xshift = +2.8cm]start.east);
  \draw [arrow] ([yshift = +.9cm, xshift = +2.8cm]start.east) -- node[anchor=west] {} ([yshift = +.9cm, xshift = +1.8cm]start.east);

  %\draw [Startarrow] ([yshift=.5cm]start.north) -- node[anchor=east] {} (start.north);
\end{tikzpicture}

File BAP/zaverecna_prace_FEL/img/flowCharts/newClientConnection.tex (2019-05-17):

\begin{tikzpicture}[scale=2, node distance = 2cm, auto]
    % Place nodes
  \node (start) [decision] {Běží hra?};
  \node (saving) [block, below of=start, text width=6cm, yshift=-0.5cm] {Ulož příchozího klienta do pomocné proměnné \texttt{newClient}.};
  \node (test1) [decision,below of=saving, yshift=-.5cm, text width = 12em] {Bylo do proměnné \texttt{newClient} něco uloženo?};
  \node (test2) [decision,below of=test1, yshift=-1.2cm, text width = 10em] {Je pro nového klienta volná pozice v poli \texttt{clients[]}?};
  \node (test3) [decision,below of=test2, yshift=-1.2cm, text width = 10em] {Je už připojen nějaký klient se stejnou IP adresou?};
  \node (test4) [decision,below of=test3, yshift=-1.2cm, text width = 7em] {Poslal nový klient správný kód (\uv{100})?};

  \node (not) [block, right of=start, text width=10em, xshift=5cm] {Nic nedělej.};
  \node (disconnect) [startstop, right of=test2, text width=15em, xshift=6cm] {Ukonči spojení s novým klientem (\texttt{newClient.stop()}).};
  \node (resend) [block, right of=test3, text width=15em, xshift=6cm] {Odešli aktivnímu klientovi (pole \texttt{clients[]}) herní pole \texttt{board[]} znovu.};
  \node (end) [startstop,right of=test4, text width=20em, xshift=6.5cm] {
      \begin{enumerate}
        \item Zařaď nového klienta do pole aktivních klientů (pole \texttt{clients[]}).
        \item Aktualizuj IP adresy v poli  \texttt{board[]}.
        \item Odešli všem aktivním klientům aktualizované pole \texttt{board[]}.
        \item Informuj uživatele o nově připojeném klientovi blikáním svítivou diodou.
      \end{enumerate}
  };

  \draw [arrow] (start) -- node[anchor=east] {NE} (saving);
  \draw [arrow] (start) -- node[anchor=south] {ANO} (not);
  \draw [arrow] (saving) -- node[anchor=east] {ANO} (test1);
  \draw [arrow] (test1) -- node[anchor=east] {ANO} (test2);
  \draw [arrow] (test2) -- node[anchor=east] {ANO} (test3);
  \draw [arrow] (test3) -- node[anchor=east] {NE} (test4);
  \draw [arrow] (test4) -- node[anchor=south] {ANO} (end);
  \draw [arrow] (test3) -- node[anchor=south] {ANO} (resend);
  \draw [arrow] (resend) -- node[anchor=east] {} (disconnect);
  \draw [arrow] (test2) -- node[anchor=south] {NE} (disconnect);
  \draw [arrow] (test1) -| node[anchor=south east] {NE} (not);

  \draw [line] (test4) -- node[anchor=south east] {NE} ([yshift=-1cm] test4.south);
  \draw [line] ([yshift=-1cm] test4.south) -| node[anchor=south east] {} ([xshift=1.0cm, yshift=0cm] disconnect.east);
  \draw [arrow] ([xshift=1.0cm, yshift=0cm] disconnect.east) -- node[anchor=south east] {NE} (disconnect);

  \draw [line] (not.north) -- node[anchor=south east] {} ([yshift=.5cm]not.north);
  \draw [arrow] ([yshift=.5cm]not.north) -- node[anchor=south east] {} ([yshift=.2cm]start.north);

  \draw [Startarrow] ([yshift=.5cm]start.north) -- node[anchor=east] {} (start.north);
\end{tikzpicture}

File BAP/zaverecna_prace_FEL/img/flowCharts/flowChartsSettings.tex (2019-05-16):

%%%FLOWCHART data
\tikzstyle{decision} = [diamond, draw, fill=blue!20,
    text width=8em, text centered, node distance=3cm, inner sep=0pt,   aspect=2]
\tikzstyle{block} = [rectangle, draw, fill=green!20,
    text width=5em, text centered,  minimum height=2em]
\tikzstyle{line} = [thick,-,>=stealth]
\tikzstyle{cloud} = [draw, ellipse,fill=red!20, node distance=3cm,
    minimum height=2em]

    \tikzstyle{startstop} = [rectangle, rounded corners = 1em, minimum width=3cm, minimum height=1cm,text centered, draw=black, fill=red!30]
    \tikzstyle{io} = [trapezium, trapezium left angle=70, trapezium right angle=110, minimum width=2em, minimum height=.5cm, text centered, draw=black, fill=orange!30]
    \tikzstyle{process} = [rectangle, minimum width=3cm, minimum height=1cm, text centered, draw=black, fill=orange!30]
%\tikzstyle{decision} = [diamond, minimum width=3cm, minimum height=1cm, text centered, draw=black, fill=green!30]
\tikzstyle{arrow} = [thick,->,>=stealth]
\tikzstyle{Startarrow} = [very thick,->,>=stealth]

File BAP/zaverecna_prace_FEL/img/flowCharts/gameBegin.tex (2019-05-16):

\begin{tikzpicture}[scale=2, node distance = 2cm, auto]
    % Place nodes
  \node (startB) [io] {Stisknuto zelené tlačítko};
  \node (startC) [io, right of = startB, xshift = 3cm] {Zadán příkaz \uv{start}};

  \node (game1) [decision, below of=startB, yshift = 0.5cm] {Běží hra?};
  \node (game2) [decision, below of=startC, yshift = 0.5cm, xshift=-.5cm] {Běží hra?};
  \node (shift) [block, left of = game1, xshift = -2.3cm] {Přesuň tah na dalšího hráče};
  \node (error1) [startstop, right of = game2, text width = 1.5cm, xshift = 2.4cm] {Chybová hláška:  běží hra};

  \node (players) [decision, below of=game1, yshift =- 0.5cm] {Alespoň 2 hráči k dispozici?};
  \node (endGame) [startstop, right of = players, text width = 17em, xshift = 5cm] {
      \begin{enumerate}
       \item Blikni svítivou diodou
       \item Ukonči hru
       \item Rozešli \texttt{board[]} s kódem \uv{3}
      \end{enumerate}
};

  \node (startGame) [block, below of=players, yshift =- 2.5cm, text width = 20em] {
      \begin{enumerate}
          \item Vyber náhodně prvního hráče
          \item Doplň jeho číslo do pole \texttt{board[]}
          \item Rozešli \texttt{board[]} s kódem \uv{1}
          \item Změň svítivou diodu -> svítí zeleně
      \end{enumerate}
  };

  \node (prepared) [startstop, right of=startGame, xshift =5.5cm] {Nová hra spuštěna};

  \draw [arrow] (startB) -- node[anchor=south] {} (game1);
  \draw [arrow] ([xshift = -.24cm]startC.south) -- node[anchor=south] {} (game2.north);

  \draw [arrow] (game1) -- node[anchor=south] {ANO} (shift);
  \draw [arrow] (game2) -- node[anchor=south] {ANO} (error1);

  \draw [arrow] (game1) -- node[anchor=east] {NE} (players);
  \draw [arrow] (game2.south) -- node[anchor=south east] {NE} (players.north);

  \draw [arrow] (players) -- node[anchor=east] {ANO} (startGame);
  \draw [arrow] (startGame) -- node[anchor=east] {} (prepared);

  \draw [arrow] (players) -- node[anchor=south] {NE} (endGame);
\end{tikzpicture}

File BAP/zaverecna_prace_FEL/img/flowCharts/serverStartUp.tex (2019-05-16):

\begin{tikzpicture}[scale=2, node distance = 2cm, auto]
    % Place nodes
  \node (start) [decision] {Jaký je Ethernet kontrolér?};
  \node (link) [decision,below left of = start,text width = 6em, xshift = -5cm, yshift=-3cm] {Je kabel připojen?};

  \node (wait1) [block, below of = start, text width = 10em, yshift=-1cm, xshift = -1cm] {Čekej 1 sekundu.};
  \node (blink1) [block, below of = wait1, text width = 10em] {Upozorni uživatele blikáním svítivé diody};

  \node (mode) [decision, below of = start, yshift = -6cm] {Ethernetový mód?};

  \node (static) [block, below left of = mode, text width = 18em, yshift=-3cm, xshift = -4cm] {Spusť server \\ \texttt{Ethernet.begin(mac, serverAddress)}};

  \node (dhcp) [decision, below right of = mode, yshift=-2.5cm, text width = 10em, xshift = +1cm] {Spusť server \\ \texttt{Ethernet.begin(mac)} \\ Přiřazena IP adresa?};

  \node (finish) [startstop, below  of = mode, yshift=-7cm, text width = 10em] {Sever je připraven};

  \draw [arrow] (start) -| node[anchor=south west] {W5200, W5500} (link);

  \draw [line] (start.east) -| node[anchor=south east] {W5100} ([xshift = 2.5cm, yshift=0.7cm] mode.north);
  \draw [arrow] ([xshift = 2.5cm, yshift=0.7cm] mode.north) -| node[anchor=south east] {} ( mode.north);

  \draw [line] (link.south) -- node[anchor=east] {} ([xshift = 0cm, yshift=-.1cm] link.south);
  \draw [line] ([xshift = 0cm, yshift=-.1cm] link.south) -- node[anchor=south east] {ANO} ([xshift = 0cm, yshift=.7cm] mode.north);

  \draw [arrow] (link) -- node[anchor=south] {NE} (blink1);
  \draw [arrow] (blink1) -- node[anchor=south] {} (wait1);
  \draw [arrow] (wait1) -- node[anchor=south] {} ([yshift=.5cm] link.north);

  \draw [arrow] (mode.west) -| node[anchor=south] {ETHMODE\_STATIC} (static.north);

  \draw [arrow] (mode.east) -| node[anchor=south west] {ETHMODE\_DHCP} (dhcp.north);

  \draw [line] (dhcp.west) -| node[anchor=south east] {NE} ([yshift = 1.2cm] dhcp.west);
  \draw [arrow] ([yshift = 1.2cm] dhcp.west) -- node[anchor=east] {} ([yshift = 0.4cm] dhcp.north);

  \draw [line] (dhcp.south) -- node[anchor=west] {ANO} ([xshift = 0.5cm]finish.east);
  \draw [arrow] ([xshift = 0.5cm]finish.east) -- node[anchor=west] {}  (finish.east);

  \draw [line] (static.south) -- node[anchor=south] {} ([xshift = -1.6cm]finish.west);
  \draw [arrow] ([xshift = -1.6cm]finish.west) -- node[anchor=west] {}  (finish.west);

  \draw [Startarrow] ([yshift=.5cm]start.north) -- node[anchor=east] {} (start.north);
\end{tikzpicture}

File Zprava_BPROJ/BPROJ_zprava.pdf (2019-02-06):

CESKÉ VYSOKÉ U ˇ; CENÍ TECHNICKÉ V PRAZE ˇ; Fakulta; elektrotechnická Katedra radioelektroniky; Arduino - piškvorky; Projekt bakaláˇrský; Studijní obor:; Elektronika a komunikace; Vedoucí práce:; Ing. Stanislav Vítek, Ph.D.; Jan Závorka Praha, 6. února 2019

Arduino - tic-tac-toe

„Prohlašuji, že jsem pˇredloženou práci vypracoval samostatne a že jsem uvedl veškeré ˇ použité informacní zdroje v souladu s Metodickým pokynem o dodržování etických princip ˚u ˇ
pˇri pˇríprave vysokoškolských záv ˇ | ere ˇ cných prací.“ ˇ
V Praze dne 6. února 2019 | |
| Podpis

### Abstrakt

Klícová slova: Arduino ethernet, piškvorky, komunikace Arduino-Arduino ˇ

## Obsah

1 Úvod | 4
2 Hardware | 4
2.4 Router a nastavení síte | | 6 ˇ
3 Software | 8
3.3 Zmeny a nastavení | | 8 ˇ
4 Záver | 10 ˇ
Seznam použité literatury a zdroj ˚u informací | 11
Seznam použitého softwaru | 12
Seznam príloh | 12 ˇ

## Seznam tabulek

1 | Rozložení tabulky pro pˇrenos dat a ˇrízení hry mezi serverem a clientem . . | 9
2 | Rozložení packetu pro komunikaci client->server | | 9

## Seznam obrázk ˚u

1 | Fotografie funkcní verze clienta | | 5 ˇ
2 | Schéma zapojení tlacítek pro ovládání serveru | | 6 ˇ
3 | Fotografie funkcní verze serveru | | 6 ˇ

## 1 Úvod

Cílem bylo vytvoˇrit jednoduchý projekt, který by demonstroval možnosti komunikace Arduin po lokální síti. Po nekolika experimentech se jako zajímavá varianta jevila jednoduchá ˇ hra pro více hrác ˚u. Vzhledem k použitému hardwaru se jako nejlepší možnost ukázala hra ˇ Piškvorky (v této verzi pro 2 - 5 hrác ˚u). ˇ

## 2 Hardware

Z pocátku bylo vše postaveno na deskách Aruino Ethernet. Pro možnost hry více než dvou ˇ
hrác ˚u bylo jedno Arduino použito jako server (bez displeje), které m ˇ | elo za úkol ˇ | ˇrídit celou
hru a Arduina s displejem (jako clienti) sloužili pouze jako zobrazovací zaˇrízení a ke komunikaci s uživatelem (prostˇrednictvím dotykové displeje). Tato volba s sebou pˇrinesla nekolik ˇ problému.
Prvním problémem je malá pamet’ Arduina Ethernet (dle [1] je pro program k dispozici ˇ
32 kB pameti). Po p ˇ | ˇridání všech knihoven (konkrétne popsáno v kapitole 3.1) z ˚ustane pro ˇ
samotný program k dispozici 30 % programové pameti, což je dost limitující ve spojení s ˇ použitím barevného dotykového displeje.
Dalším problém s omezenými prostˇredky Arduina Ethernet nastal pˇri vývoji serveru. Díky absenci dotykového displeje bylo pro samotný kód k dispozici dostatek místa, ale pro-
blémy nastaly pˇri samotné komunikaci, kdy behem odesílání dat (p ˇ | ˇrenáší se pole o velikosti
140 bajt ˚u pro každého clienta zvlášt’, detailneji v kapitole 3.2.1) docházelo k náhodným ˇ pád ˚um a restart ˚um Arduina. Tento problém byl vyˇrešen použitím desky Arduino Due.
Arduino - piškvorky | 4

### 2.1 Client

Základem je, jak už bylo zmíneno výše, Arduino Ethernet s mikrokontrolérem ATmega328P. ˇ Jako zobrazovací a ovládací prvek byl zvolen 2.4"barevný TFT LCD displej s rozlišením
320x240 pixel ˚u s rezistivní dotykovou plochou ve forme shieldu. Vzhledem k rozm ˇ | er ˚um ˇ
(výšce) RJ-45 konektoru, který je umístený na desce s Arduinem, je nutné pro správné p ˇ | ˇri-
pojení displeje použít lištu s oboustrannými kolíky o délce minimálne 15 mm. Protože u ˇ displej ˚u použitých v této práci byly kolíky pˇripájené už od výrobce, byla dodatecnˇ e vyro- ˇ bena patice z dutinkové lišty a lišty s oboustrannými kolíky.


Obrázek 1: Fotografie funkcní verze clienta ˇ

### 2.2 Server

Základem serveru je Arduino Due (bližší specifikace v [3]). Pro pˇripojení do síte byl zvolen ˇ Ethernetový shield s cipem Wiznet W5100. ˇ
Pro pohodlné ovládání hry jsou k serveru pˇripojena dve tla ˇ | cítka, tla ˇ | cítko s ˇ | cerveným ˇ
kroužkem slouží pro zastavení a restart hry, tlacítko se zeleným kroužkem slouží pro start ˇ
hry. Schéma zapojení je videt na obrázku 2. Zapojení bylo pro testovací ú ˇ | | cely zhotoveno na ˇ
univerzální desce plošných spoj ˚u. Pˇripojení je realizováno pomocí vodic ˚u, kolíky umíst ˇ | ené ˇ
v desce slouží pouze k pˇripevnení k Arduinu nebo shieldu. Vodi ˇ | ce s p ˇ | ˇripojí podle barvy
následovne:ˇ
1. Cerný - GND ˇ
2. Modrý - D40
3. Oranžový - D38

4. Cervený - 5 V ˇ

Místo pin ˚u D40 a D38 lze použít libovolné jiné, ale tato zmena musí být upravena v kódu ˇ pro server (viz. kapitola 3.3.1).


Obrázek 2: Schéma zapojení tlacítek pro ovládání serveru ˇ


Obrázek 3: Fotografie funkcní verze serveru ˇ

### 2.3 Napájení

Napájení je ˇrešeno externím zdrojem 5 V DC. Client se k napájení pˇripojuje na programovací vstup (místo pˇrevodníku USB/UART), na piny: 1 = GND a 3 = 5V (zprava). Pˇripojení externího zdroje pomocí souosého konektoru a využití integrovaného stabilizátoru není možné, protože client s displejem odebírá za provozu kolem 300 mA.

### 2.4 Router a nastavení síteˇ

Pro testování byl použit Huawei EchoLife HG520i. V nastavení byly vypnuty všechny funkce
(WiFi apod.) a byl nakonfigurován DHCP server. Konfiguracní soubor dostupný v p ˇ | ˇríloze 1.

Aby se Arduina mohla spojit, je nutná aby mel server statickou IP adresu. Tento router ˇ
neumožnuje p ˇ | ˇriˇrazení IP adresy k dané MAC, proto má server pevne p ˇ ˇriˇrazenou IP (její
zmena popsána v kapitole 3.3.1). Tato adresa musí být ze stejné sít ˇ | e jako je router ale mimo ˇ
rozsah DHCP serveru.
Client ˚um je IP adresa pˇriˇrazována automaticky pomocí DHCP.

## 3 Software

### 3.1 Knihovny

Seznam použitých knihoven pro clienta:

- Ethernet library: komunikace po LAN (se serverem), zdroj [2].
- UTFGLUE: ovládání displeje, zdroj [4].
- TouchScreen: práce s dotykovou plochou, zdroj [5].

Seznam použitých knihoven pro server:

- Ethernet library: komunikace po LAN (s jednotlivými clienty), zdroj [2].

### 3.2 Komunikace

### 3.2.1 Komunikace Server -> Client

Behem komunikace tímto sm ˇ | erem vždy server odešle celou herní desku (pole typu byte ˇ
board), celkem tedy 136 bajt ˚u. Pokud client toto pole v poˇrádku pˇrijme, dojde k jeho vyhodnocení a vykonání potˇrebných funkcí (pˇrekreslení displeje, vyžádání akce od uživatele,
zobrazení hlášky). Hodnoty pole mení pouze server. Popis pole a co které hodnoty p ˇ | | ˇredsta-
vují je videt v tabulce 1. ˇ
Pˇri odesílání je pole rozdeleno do packet ˚u. Každý packet obsahuje 8 bajt ˚u pole ˇ | | board,
poˇradové císlo packetu (aby client mohl pole zp ˇ | etn ˇ e sestavit) a dva bajty kontrolního sou ˇ | ctu. ˇ
Client pr ˚ubežn ˇ e p ˇ ˇrijímá jednotlivé cásti, pokud dorazí n ˇ | ejaká ˇ | cást chybná (nesedí kont- ˇ
rolní soucet), client si m ˚uže vyžádat od serveru znovuodeslání (realizace popsána v kapitole ˇ
3.2.2). Pokud client pˇrijme všechny cásti, pole ˇ | board vyhodnotí.

### 3.2.2 Komunikace Client -> Server

Pˇri této komunikaci se pˇrenáší vždy dva bajty, pˇricemž celá zpráva je odeslána dvakrát po ˇ
sobe. Server po p ˇ | ˇrijetí obou zpráv zprávy porovná a pokud se neliší provede dané instrukce
(význam v tabulce XXX). V pˇrípade neshody je zpráva zahozena. ˇ

### 3.3 Zmeny a nastavení ˇ

### 3.3.1 Server

Tabulka 1: Rozložení tabulky pro pˇrenos dat a ˇrízení hry mezi serverem a clientem
Index | Hodnoty | Popis
0-89 | | Každý index odpovídá jednomu ctvere ˇ cku na herní desce piškvorek ˇ
| 0 | Pole je prázdné (neobsazené)
| 1-5 | Obsazeno nekterým hrá ˇ cem/clientem ˇ
90 | | Pˇrenos ˇrídicí informace pomocí kódu
| 0 | Vše je OK, pˇrekreslit obrazovku
| 3 | Pˇríprava nové hry, zobrazit úvodní obrazovku
| 9 | Informace pro hrác odpojen, že bude odpojen ˇ
| 10 | Hraje nejaký hrá ˇ ce ( ˇ císlo daného hrá ˇ ce v poli 91) ˇ
| 100 | Hra skoncila remízou ˇ
| 10x | Hodnota podle hráce, který vyhrál: 101-105 (’x’ je ˇ císlo hrá ˇ ce) ˇ
| 20x | Problémy s daným hrácem: 201-205 (’x’ je ˇ císlo hrá ˇ ce) ˇ
91 | 1-5 | Císlo hrá ˇ ce, který je na tahu ˇ
93 | 0-89 | Pocet odehraných kol (vypl ˇ nuje server) ˇ
95-96 | Kód barvy | Barva hráce 1 ˇ
97-98 | | Barva hráce 2 ˇ
99-100 | | Barva hráce 3 ˇ
101-102 | | Barva hráce 4 ˇ
103-104 | | Barva hráce 5 ˇ
105-108 | IPv4 adresa | IP adresa hráce 1 ˇ
109-112 | | IP adresa hráce 2 ˇ
113-116 | | IP adresa hráce 3 ˇ
117-120 | | IP adresa hráce 4 ˇ
121-124 | | IP adresa hráce 5 ˇ

Tabulka 2: Rozložení packetu pro komunikaci client->server
Index | Hodnoty | Popis
0 | 1x | Jedná se o informaci, že další pˇrenesený bajt bude císlo vypln ˇ eného ˇ pole (ctvere ˇ cku) herní desky (board), za ’x’ (na míst ˇ e jednotek) ˇ je vyplneno ˇ císlo hrá ˇ ceˇ
| 2x | Žádost klienta o poslání dané cásti herního pole (board), v další ˇ bajtu je císlo dané ˇ cásti (packetu), za ’x’ (na míst ˇ e jednotek) ˇ je vyplneno ˇ císlo hrá ˇ ceˇ
1 | 0-89, 0-16 | Podle hodnoty pˇredchozího bajtu: index vyplneného ˇ pole nebo poˇradí packetu, který má být poslán znovu

## 4 Záverˇ

## Seznam použité literatury a zdroj ˚u informací

[1] Arduino store: ARDUINO ETHERNET REV3 [online]. [cit. 2019-02-05]. Dostupné z: https://store.arduino.cc/arduino-ethernet-rev3-without-poe
[2] Arduino: | Ethernet | library | [online]. | [cit. | 2018-12-18]. | Dostupné | z:
https://www.arduino.cc/en/Reference/Ethernet
[3] Arduino store: ARDUINO DUE [online]. [cit. 2019-02-05]. Dostupné z: https://store.arduino.cc/arduino-due
[4] MCUFRIEND_kbv library. Github [online]. [cit. 2019-02-05]. Dostupné z: https://github.com/prenticedavid/MCUFRIEND_kbv
[5] Adafruit_TouchScreen library. Github [online]. [cit. 2019-02-05]. Dostupné z: https://github.com/adafruit/Adafruit_TouchScreen

## Seznam použitého softwaru

1. TEXmaker, TEXLive
2. Arduino IDE (https://www.arduino.cc/en/main/software)
3. Tables Generator (https://www.tablesgenerator.com/latex_tables)
4. Citace.com (https://www.citace.com/citace-pro)
5. EasyEDA (https://easyeda.com/)
6. IrfanView (https://www.irfanview.com/)
7. Linux Mint 18.1 Cinnamon 64-bit (https://linuxmint.com/)

## Seznam príloh ˇ

Pˇríloha 1: Konfiguracní soubor routeru Huawei EchoLife HG520i na Githubu, dostupné z: ˇ https://goo.gl/h8494S

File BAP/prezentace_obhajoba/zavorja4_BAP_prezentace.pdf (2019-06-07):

## Interaktivní hra využívající IoT prostředky

Katedra radioelektroniky Fakulta elektrotechnická; 7. června 2019

Jan Závorka
zavorja4@fel.cvut.cz

České vysoké učení technické v Praze

Obsah | Cíl práce | Realizace | Diskuze

## Obsah I

1 Obsah

2 Cíl práce

3 Realizace

4 Diskuze

## Cíl práce

Demonstrační zařízení:
- Energeticky nenáročná zařízení
- Forma jednoduché hry
- Komunikace po síti

## Realizace

- Hra piškvorky
- Platforma Arduino
- Server - řízení hry
- Klient - interakce s uživatelem
- 3D tisk krabiček (PLA)
- Komunikace po lokální síti (centrální prvek switch)

## Realizace

- Hra piškvorky
- Platforma Arduino
- Server - řízení hry
- Klient - interakce s uživatelem
- 3D tisk krabiček (PLA)
- Komunikace po lokální síti (centrální prvek switch)


Obrázek 1: Schéma zapojení jednotlivých zařízení do sítě

## Realizace - server


Děkuji za pozonost!

## Jan Závorka

zavorja4@fel.cvut.cz

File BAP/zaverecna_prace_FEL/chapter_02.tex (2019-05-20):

\section{Popis softwaru}
\subsection{Knihovny}
\label{sec:knihovny}
Pro realizaci byly použity následující knihovny:
\begin{itemize}
  \item \textit{Ethernet library}: knihovna slouží pro připojení Arduina k internetu. Jak je uvedeno na webových stránkách \cite{EthLib} jsou podporovány desky a shieldy založené na~konrolérech W5100, W5200, W5500. Tato knihovna je použita jak u~serveru, tak i u klientů. U serveru připojený ethernet shield obsadí piny 10, 11, 12, 13. Komunikace Arduina se shieldem (ethernet kontrolérem) probíhá po SPI sběrnici.

  \item \textit{MCUFRIEND\_kbv library}: knihovna slouží k ovládání displeje u klienta. Pro~správnou funkci je nutné, jak se zmiňuje autor na domovské stránce knihovny~\cite{lib_MCUFRIEND_kbv},  mít k dispozici také knihovnu \textit{Adafruit\_GFX}~\cite{lib_adafruitGFX}. Pro použití displeje se nejdříve vytvoří instance třídy \texttt{UTFGLUE}, kde je nutné správně definovat piny pro daný shield, v tomto případě \texttt{UTFTGLUE LCD(0x0154,A2,A1,A3,A4,A0);}. Pro řízení displeje jsou pak volány patřičné metody formou \textit{LCD.metoda(parametry);}, například pro vyplnění celého displeje černou \texttt{LCD.clrScr();}. Pomocí ukázkového zdrojového kódu z této knihovny \textit{(examples/TouchScreen\_
calibr\_kbv)} byly získány kalibrační hodnoty pro dotykovou plochu displeje.

  \item \textit{Adafruit\_TouchScreen}: slouží k zaznamenání hodnot ze čtyřvodičové dotykové plochy. Stejně jako u knihovny pro displej je nejdříve nutné vytvořit instanci dané třídy \texttt{TouchScreen} v tomto případě tak \texttt{TouchScreen Touch(XP, YP, XM, YM, 300);}, kde \textit{XP, YP, XM, YM} jsou piny, na které je vyvedená dotyková plocha (pro použitý shield jsou to: XP = 6, YP = A1, XM = A2, YM = 7). Hodnota 300 by dle popisu knihovny \cite{lib_touch} označuje elektrický odpor dotykové plochy X (měřeno multimetrem mezi piny XP a XM). Pro použité shiledy je hodnota přibližně $300  \ \mathrm{\Omega}$. Dále je třeba určit minimální a maximální tlak pro vyhodnocení dotyku pomocí \texttt{\#define MINPRESSURE} a \texttt{\#define MAXPRESSURE}. Vyhovující jsou hodnoty uvedené v ukázkových kódech pro knihovnu a to konkrétně 10~pro~\texttt{MINPRESSURE} a 1000 pro \texttt{MAXPRESSURE}.

  \item \textit{SimpleTimer Library for Arduino}: jednoduchá knihovna, která slouží k řízení určitých časových událostí (kde není třeba velká přesnost), například pro zobrazení a~skrytí chybových hlášek, blikání indikační svítivé diody u serveru. Dle~webových stránek \cite{lib_simpleTimer} je knihovna založená na funkci \texttt{milis();} (vrací počet milisekund od~začátku běhu programu) a nevyužívá přerušení ani hardwarový timer.
\end{itemize}

\subsection{Konfigurační hodnoty}
V této kapitole jsou popsány jednotlivé konfigurační hodnoty, by mohly být upraveny pro správnou funkci celého zařízení. Změny se vždy provádí přímo ve zdrojovému kódu, vždy pouze v hlavním souboru: \textit{piskvorky\_MP\_client.ino} pro klienta\linebreak a~\mbox{\textit{piskvorky\_MP\_server.ino}} pro server. Jak už bylo zmíněno v kapitole~\ref{sec:HWclient}, vzhledem k~malé paměti pro program nebylo možné implementovat menu, proto je nutné změny provádět přímo ve zdrojovém kódu a dané zařízení pak přeprogramovat. V případě serveru je k dispozici microUSB konektor, který je dostupný skrze obdélníkový otvor na boku zařízení. V případě klienta je nutné demontovat víko, odpojit napájecí modul (v modré bužírce) a připojit Arduino k počítači pomocí převodníku USB~-~ UART.

Jednotlivé konfigurační bloky jsou vždy ohraničeny komentáři, mezi nimiž se nacházejí jednotlivé proměnné, popis jejich funkce a omezení hodnot. Níže je uveden příklad ohraničení bloku pro nastavení sítě (IP adresa a port):
\begin{verbatim}
/* ---------- KONFIGURACE - nastavení sítě ----------*/

/* ---------- KONEC - nastavení sítě ----------*/
\end{verbatim}

\subsubsection{Konfigurace serveru}
\label{sec:server-nastaveni}
%Nastavení sítě
Nejprve je nutné vybrat síťový režim, v případě \textit{ETHMODE\_STATIC} je použita IP~adresa, která je uložena v proměnné \textit{serverAddress}. V případě volby \textit{ETHMODE\_DHCP} je adresa přiřazena DHCP serverem a je nutné dodržet aby se přiřazená adresa neměnila a byla zároveň nastavená u jednotlivých klientů.

Dále je třeba nastavit příslušnou MAC adresu, použitému Ethernet shieldu nebyla přiřazena výrobcem, takže je nutné nějakou zvolit. Vzhledem k tomu, že zařízení je~provozováno na samostatné lokální síti, byla MAC adresa vybrána náhodně. V případě, že~v~síti jsou další zařízení, je možné vybrat MAC adresu například podle postupu popsaného v~\cite{vyberMAC}. Vezme se MAC adresa nějaké zařízení v síti a poslední bajt se zvětší o~jedna a takto vzniklá MAC adresa se přiřadí shieldu.
Vybraná MAC adresa je~v~poli~\texttt{mac}.

Jako poslední je potřeba přiřadit port, na kterém budou zařízení komunikovat. Dle~normy~\cite{norm_RFC6335} je možné zvolit jakýkoliv dynamický port (49152-65535), protože tyto porty nebudou nikdy přiřazeny žádné službě. Port je uložen v proměnné \texttt{localPort} a~stejný port musí být nastaven i u klientů.
\lstinputlisting[language=C++, style=customc_config, firstline=1, lastline=8, title= Blok konfigurace ethernet shieldu pro server]{codes/server_config.cpp}

%Nastavení pinů
\clearpage
Jak je popsáno v kapitole \ref{sec:HWserver}, jsou k serveru připojena dvě tlačítka a jedna barevná svítivá dioda. V případě, že je nutné tyto periferie připojit jinak, je možné změnit čísla pinů v konfiguračním bloku \textit{nastavení pinů a LED}. Tlačítka využívají interní pull-up rezistory a jejich zapojení je uvedeno na obrázku \ref{fig:server_module}.
\lstinputlisting[language=C++, style=customc_config, firstline=10, lastline=22, title= Blok konfigurace pinů pro svítivou diodu a tlačítka]{codes/server_config.cpp}

%Nastavení barev
Jako poslední je možné nastavit jakou barvu budou mít jednotliví klienti. V ukázkovém případě jsou barvy přiřazeny z výběru, který je uveden v kódu, ale je možné také definovat vlastní ve formátu RGB565 (16-bit barva).
\lstinputlisting[language=C++, style=customc_config, firstline=24, lastline=30, title= Blok konfigurace jednotlivých barev pro klienty/hráče]{codes/server_config.cpp}

\subsubsection{Konfigurace klienta}
\label{sec:client-nastaveni}
%Nastavení profilů
Klientů se v celé sestavě nachází několik (v tomto případě tři). Ti se liší pouze určitým nastavením (IP adresa, MAC adresa, kalibrační hodnoty displeje), proto jsou vytvořeny profily pro jednotlivé klienty (softwarově omezeno na pět). Každému profilu se~nastaví požadované parametry a při nahrávání programu do Arduina se pak profily mění pomocí \texttt{\#define CLIENTx}, kde x je číslo jednotlivých klientů/profilů. Pokud není zvolen žádný profil, použity jsou defaultní hodnoty a uživatel je o tom informován při~překladu pomocí direktivy \texttt{\#warning} (zobrazí se hlášení, ale překlad neukončí).
\lstinputlisting[language=C++, style=customc_config, firstline=1, lastline=3, title= Blok výběru profilu pro klienta]{codes/client_config.cpp}

%Nastavení MAC adres
V této části se přiřazují jednotlivé MAC adresy daným profilům. Výhodou oficiálních Arduino Ethernet desek je, že mají MAC adresu přidělenou výrobcem a je možné ji nalézt na bílém štítku ze spodní strany.
\lstinputlisting[language=C++, style=customc_config, firstline=6, lastline=38, title= Blok přiřazení MAC adres jednotlivým klientským profilům]{codes/client_config.cpp}

%Nastavení IP adres
\clearpage
Stejně jako v případě serveru i zde je možné vybrat ze dvou režimů sítě, a to \textit{ETHMODE\_STATIC} a \textit{ETHMODE\_DHCP}. V případě volby \textit{ETHMODE\_DHCP} není na adresu přiřazenou DHCP serverem kladen žádný zvláštní nárok. V případě použití režimu \textit{ETHMODE\_STATIC} je ještě nutné dodefinovat IP adresy pro jednotlivé klienty. Opět lze s výhodou využít profilů. Pokud se použije defaultní, je o tom uživatel opět při překladu informován.
Kromě toho je ještě nutné doplnit IP adresu serveru, ke kterému se budou klienti připojovat. Ta byla nastavena při konfiguraci serveru (kapitola \ref{sec:server-nastaveni}) stejně tak jako port, který je také nutno zvolit stejný.
\lstinputlisting[language=C++, style=customc_config, firstline=40, lastline=66, title= Blok nastavení síťového režimu a IP adres]{codes/client_config.cpp}

%Nastavení kalibrace displeje
\clearpage
Jako poslední je nutné nastavit kalibrační hodnoty dotykové plochy displeje. Nejjednodušší způsob jejich získání je použít ukázkový program v knihovně\linebreak \mbox{\textit{MCUFRIEND\_kbv library}}, který lze nalézt  v \textit{(examples/TouchScreen\_
calibr\_kbv)}. V ukázkovém programu je třeba upravit podle použitého shiledu nastavení pinů. Poté stačí postupovat podle pokynů na displeji a výsledek se vypíše na sériovou linku (lze použít integrovaný v Arduino IDE - \textit{Tools->Serial Monitor}). Krom kalibračních hodnot je také nutné doplnit orientaci displeje (\texttt{\#define TOUCH\_LANDSCAPE} nebo \texttt{\#define TOUCH\_PORTRAIT}). V případě, že nebude zvolena ani jedna možnost, překlad bude ukončen a bude vypsána chybová hláška (direktiva \texttt{\#error}). I v tomto případě lze s výhodou využít profilů.
\lstinputlisting[language=C++, style=customc_config, firstline=68, lastline=109, title= Blok nastavení kalibračních hodnot dotykové plochy]{codes/client_config.cpp}

\subsection{Komunikace server - klient}
\label{sec:comm_server-client}
Server komunikuje s klienty pomocí pole \textit{board}. Jedná se o jednorozměrné pole typu \textit{byte}\footnote{Dle webu Arduina \cite{ard_unsignedChar} se jedná o stejný typ jako \textit{unsigned char}. Kvůli konzistentnosti stylu programování Arduina je však doporučeno používat datový typ \textit{byte}.} o velikosti 136 (velikost musí být dělitelná osmi). V tomto poli jsou vyplněné všechny důležité informace o stavu hry i~jednotlivých klientech. Význam jednotlivých hodnot v poli \textit{board} je popsán v tabulce~\ref{tab:packet_server-client}.

Při odesílání je toto pole rozděleno na části po osmi bajtech. Každá tato část je~vybavena pořadovým číslem a dvoubajtovým kontrolním součtem (v něm je zahrnuto i~pořadové číslo) a následně odeslána připojeným klientům.

Klienti postupně přijímají všechny části a v případě bezchybného příjmu data vyhodnotí. V případě, že klient na základě kontrolního součtu identifikoval chybnou část, odešle požadavek podle pravidel komunikace klient - server (popsáno v kapitole \ref{sec:comm_client-server}). Server pak v případě přijetí požadavku odešle danému klientovi vyžadovanou část pole.

\subsection{Komunikace klient - server}
\label{sec:comm_client-server}
Klient komunikuje se serverem, až na výjimku při sestavení spojení, prostřednictvím dvoubajtového pole. Popis jednotlivých částí pole je v tabulce \ref{tab:clietn-server}. Pro kontrolu přenosu se každá zpráva odešle třikrát. Na straně serveru se pak porovnají dvě ze tří přijatých zpráv a ostatní přijatá data se zahodí. Klient může poslat data maximálně jednou za~sekundu (posláním dat se rozumí odeslání tří stejných zpráv).

Pokud při porovnání server zjistí, že přijeté zprávy nejsou stejné, odešle danému klientovi znovu herní desku. V případě, že byl daný hráč na tahu a přenos požadavku na vyplnění pole se nezdařil, je mu prostřednictvím znovuodeslání pole znovu aktivován tah.

V případě, že klient přijal od serveru chybná data, odešle požadavek ve tvaru \mbox{\{20, x\}}, kde \textit{x} je číslo chybně přijaté části pole. Pokud je toto serverem správně přijato, odešle požadovanou část znovu (dle pravidel komunikace server - klient, kapitola \ref{sec:comm_server-client}).

\input{tables/board_content.tex}

\input{tables/client_packet.tex}

\newpage
\subsection{Sestavení spojení}
\subsubsection{Příprava serveru}
Při spuštění serveru dojde nejprve k identifikaci ethernet kontroléru. V případě, že je identifikován kontrolér WIZnet W5200 nebo WIZnet W5500, je k dispozici funkce \texttt{Ethernet.linkstatus()}, která umožňuje získat informaci o~fyzickém připojení kabelu. Pokud není kabel připojen, je toto signalizováno blikáním signalizační svítivé diody červenou barvou (viz. tabulka \ref{tab:LED_man}) a program nepokračuje dále, dokud není kabel připojen.

V případě, že server získává adresu z DHCP serveru, je možné ještě ověřit správné připojení pomocí kontroly získané adresy. V knihovně Arduino Ethernet \cite{EthLib} je toto řešeno návratovou hodnotou funkce \texttt{Ethernet.begin(mac)} (v režimu DHCP má pouze jeden parametr a to lokální MAC adresu, jinak funkce \texttt{Ethernet.begin()} nemá návratovou hodnotu). Proces přípravy serveru je znázorněn na obrázku \ref{fig:flow:serverStartUp}.

Pokud je však nastaven mód se statickou IP adresou a je použit shield s ethernet kontrolérem například WIZnet W5100 (jako je tomu v této práci), není zde žádná vhodná možnost kontroly správného připojení. Jedna z možností by byla, že~by~se~server pokusil poslat zprávu \textit{Echo Request} nějakému známému zařízení v síti a očekávat odpověď \textit{Echo Reply}. Ale vzhledem k tomu, že jako centrální prvek je v tomto zapojení zvolen switch a žádné další zařízení v síti není, je i tato možnost nepoužitelná.

V této fázi je příprava serveru dokončena, postup navázání spojení s klientem je popsán v následující kapitole \ref{sec:connection_communication}.

\begin{figure}
  \centering
  \input{img/flowCharts/serverStartUp.tex}
  \caption{\label{fig:flow:serverStartUp} Diagram procesu přípravy a zapnutí serveru}
\end{figure}

\subsubsection{Příprava klienta}
Příprava probíhá obdobně jako u serveru, ale vzhledem k tomu, že použité Arduino Ethernet desky mají kontrolér WIZnet W5100, je vynechána část s kontrolou připojení kabelu. Jediná možná detekce správného připojení kabelu je tak pouze v režimu, kdy je IP adresa získávána z DHCP serveru. V~takovém případě se na displeji vypíše zpráva \textit{Zkontrolujte pripojeni kabelu} a klient čeká dokud IP adresu neobdrží. V~opačném případě je přepnuto na úvodní obrazovku.

V této fázi je klient připraven a čeká na příkaz uživatele připojit se k serveru.

\clearpage
\subsubsection{Sestavení pojení}
\label{sec:connection_communication}
Pokud nastavení a spuštění serveru proběhlo správně, server v nekonečné smyčce (\texttt{void loop()\{\}}) pravidelně ověřuje, zda nějaké zařízení nevyžaduje připojení. To je realizováno metodou z knihovny \cite{EthLib} - \texttt{server.accept()}. V případě příchozího spojení vrátí tato metoda objekt typu client, v opačném případě \textit{NULL}. To je uloženo do proměnné \texttt{newClient}. Metoda \texttt{server.accept()} vrací data o daném příchozího spojení pouze jednou a proto je nutné je uložit do extra proměnné.

Připojení klienta spustí uživatel stisknutím příslušného tlačítka na displeji. Klient se v pravidelných intervalech pokouší o navázání spojení funkcí \linebreak \mbox{\texttt{client.connect(serverAddress, localPort)}}. V případě, že je připojení k serveru úspěšné, pošle klient serveru zprávu \uv{100}. Tento kód informuje server, že se jedná o~klienta pro piškvorky, pokud by server přijal jiná data, spojení zruší.

Pokud server zaznamená nové příchozí spojení, spustí kontrolu nového hráče. Celý proces připojení nového hráče je naznačen na obrázku \ref{fig:flow:newClientServer}.

\begin{figure}
  \centering
  \input{img/flowCharts/newClientConnection.tex}
  \caption{\label{fig:flow:newClientServer} Diagram procesu příjmu nového klienta na straně serveru}
\end{figure}

V této fázi se čeká na připojení dalších klientů. Pravidelně je také kontrolováno, zda se nějaký klient neodpojil. V případě, že ano, jsou jeho data smazána jak z pole \texttt{clients[]}, tak z herního pole \textit{board} a o této skutečnosti jsou ostatní klienti informováni zprávou (odeslání pole \textit{board}) s kódem 20x, kde \textit{x} je číslo odpojeného klienta. Tato zpráva je zobrazena na displejích klientů po dobu 4000 ms (nastaveno v proměnné \texttt{clientErrMessageLast}).

Nyní se čeká na zahájení hry ze strany uživatele (stisk zeleného tlačítka na serveru nebo příkazem přes sériovou linku, viz. kapitola \ref{sec:ovladani}).

\subsection{Řízení průběhu hry}
Po příkazu ke spuštění hry se nejdříve ověří, zda jsou k dispozici alespoň dva hráči. Pokud tomu tak není, hra se nezahájí a uživatel je o tom informován indikační svítivou diodou (viz. tabulka \ref{tab:serverLED}).

V případě, že je k dispozici dostatečný počet hráčů, je náhodně vybrán (funkce \texttt{random()}) první hráč a všem hráčům se rozešle pole \texttt{board[]} s vyplněným herní kódem (1) a číslem hráče (metoda odeslání popsána v kapitole \ref{sec:comm_server-client}). Jednotliví hráči porovnají pořadí svých IP adres v poli \texttt{board[]} a zjištěný index porovnají s číslem hráče vyplněným na pozici 91 v poli \texttt{board[]}, hráč, který nalezne shodu, je na tahu, ostatní vyčkávají. Proces startu hry je na obrázku \ref{fig:flow:gameBegin}.
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

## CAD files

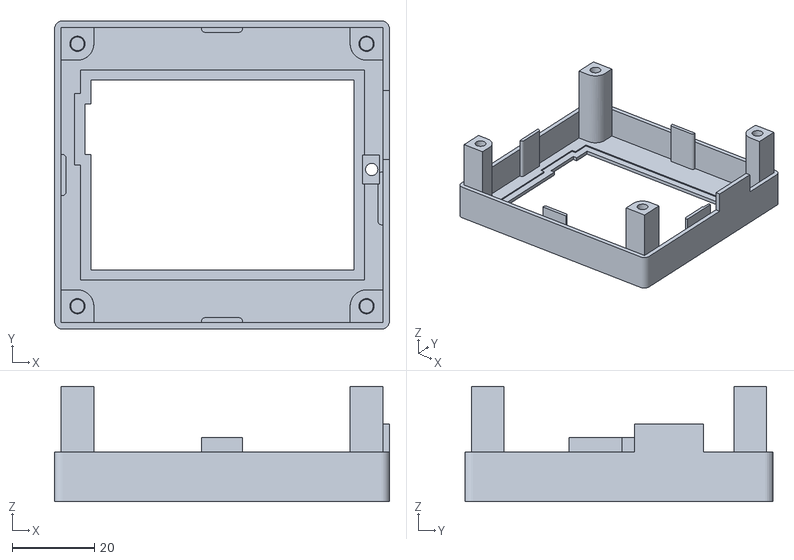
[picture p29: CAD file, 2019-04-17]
BAP/zavorja4_BP_priloha/soubory_krabicek/klient/case_top.stl
81.7 x 75.2 x 28.1

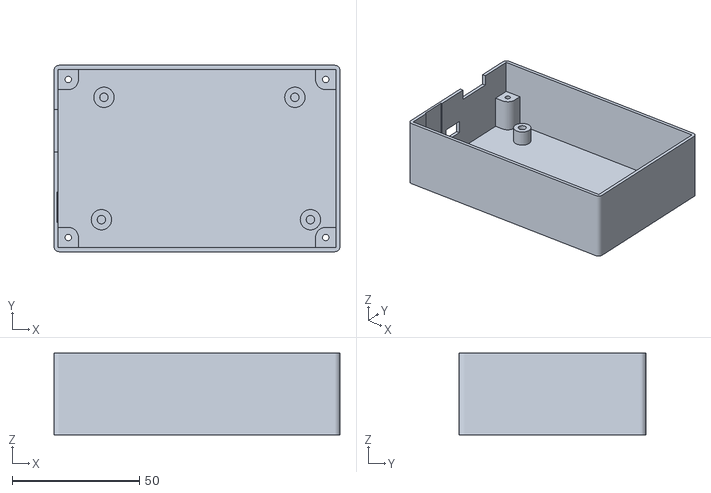
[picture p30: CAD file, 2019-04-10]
BAP/zavorja4_BP_priloha/soubory_krabicek/server/case_bottom.stl
112.2 x 73.2 x 32.1

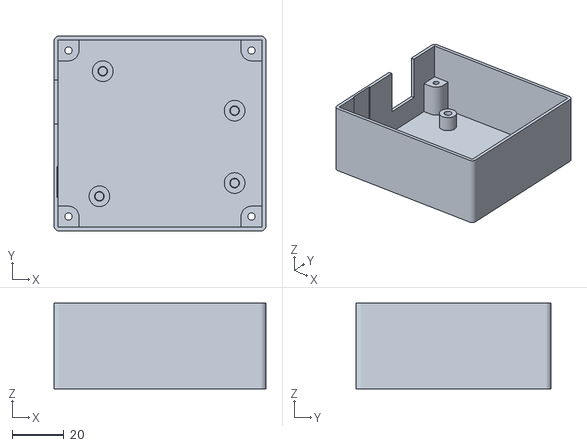
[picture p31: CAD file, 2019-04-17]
BAP/zavorja4_BP_priloha/soubory_krabicek/klient/case_bottom.stl
81.7 x 75.2 x 33.1

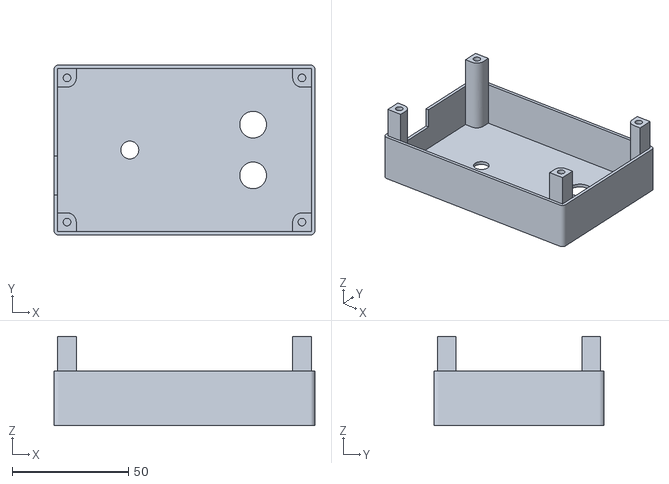
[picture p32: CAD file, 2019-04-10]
BAP/zavorja4_BP_priloha/soubory_krabicek/server/case_top.stl
112.2 x 73.2 x 38.4

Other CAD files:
piskvorky_case/client_ArdEthernet_case/OldVersions/Sestava_krabicka.0012.iam
piskvorky_case/client_ArdEthernet_case/OldVersions/case_bottom.0015.ipt
piskvorky_case/client_ArdEthernet_case/OldVersions/case_top.0020.ipt
piskvorky_case/client_ArdEthernet_case/Sestava_krabicka.iam
piskvorky_case/client_ArdEthernet_case/case_bottom.ipt
piskvorky_case/client_ArdEthernet_case/case_top.ipt
piskvorky_case/server_ArdDue_case/OldVersions/case_bottom.0015.ipt
piskvorky_case/server_ArdDue_case/OldVersions/case_top.0014.ipt
piskvorky_case/server_ArdDue_case/OldVersions/case_top.0015.ipt
piskvorky_case/server_ArdDue_case/OldVersions/sestava_krabicka.0011.iam
piskvorky_case/server_ArdDue_case/case_bottom.ipt
piskvorky_case/server_ArdDue_case/case_top.ipt
piskvorky_case/server_ArdDue_case/sestava_krabicka.iam

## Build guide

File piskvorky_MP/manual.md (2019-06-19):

# Návod na použití piškvorek

### Význam indikační LED u serveru
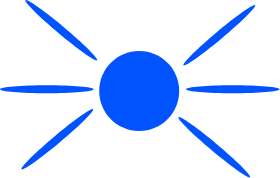
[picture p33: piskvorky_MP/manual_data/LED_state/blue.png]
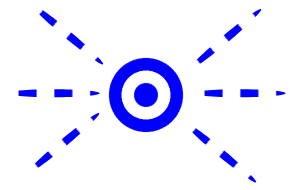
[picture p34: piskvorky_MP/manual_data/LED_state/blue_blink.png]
Význam:  svítí,  bliká

| Stav | Význam |
| :---:  |:---:|
|  | server je vypnutý/nemá napájení |
|  | server je připraven |  
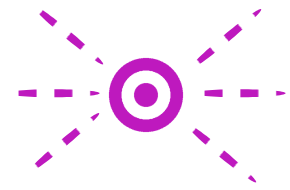
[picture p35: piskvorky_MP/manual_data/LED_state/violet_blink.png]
|  3x | nový klient připojen |
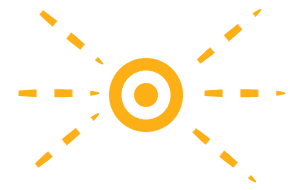
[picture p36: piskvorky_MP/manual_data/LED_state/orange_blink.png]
|  3x | klient se odpojil/byl odpojen |
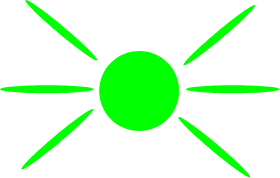
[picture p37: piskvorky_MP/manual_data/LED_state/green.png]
|  | aktuálně běží hra |
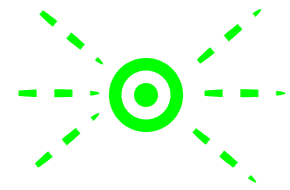
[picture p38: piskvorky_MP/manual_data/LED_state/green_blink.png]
|  | hra ukončena (výhra/remíza) |
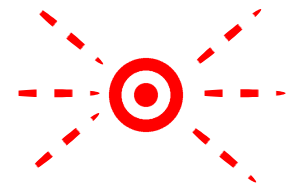
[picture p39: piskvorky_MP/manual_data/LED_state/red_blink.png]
|  3x | chyba (nedostatek hráčů pro hru)|
|  stále | chyba sítě (připojení kabelu) |

---

### Funkce tlačítek na serveru
#### Zelené tlacitko `Zelené tlačítko`:
  - Pokud neběží hra (indikační LED svítí modře ) - stiskem tlačítka dojde ke spuštění hry (s ověřením zda je k dispozici dostatek hráčů)
  - Pokud hra již běží (indikační LED svítí zeleně ) - stiskem tlačítka dojde k posunutí tahu na dalšího hráče

#### Cervene tlacitko `Červené tlačítko`:
  - Pokud je stisknuto, dojde k přerušení hry aktuálně běžící hry (dosavadní stav hry je resetován)
---

### Příkazy pro server
|  Příkaz | Význam |
|:---:|:---:|
| help  | Vypíše nápovědu (dostupné příkazy) |
| info  | Vypiší informace o serveru (HW, verze SW, apod.) |
| players | Zobrazí čísla a IP adresy připojených hracu |
| kick 'x'| Odpojí hráče číslo _x_ |
| nextP | Přepne na dalšího hráče |
|  start  | Spustí hru (ekvivalent zeleného tlačítka) |
|  reset  | Přeruší a resetuje hru (ekvivalent červeného tlačítka) |

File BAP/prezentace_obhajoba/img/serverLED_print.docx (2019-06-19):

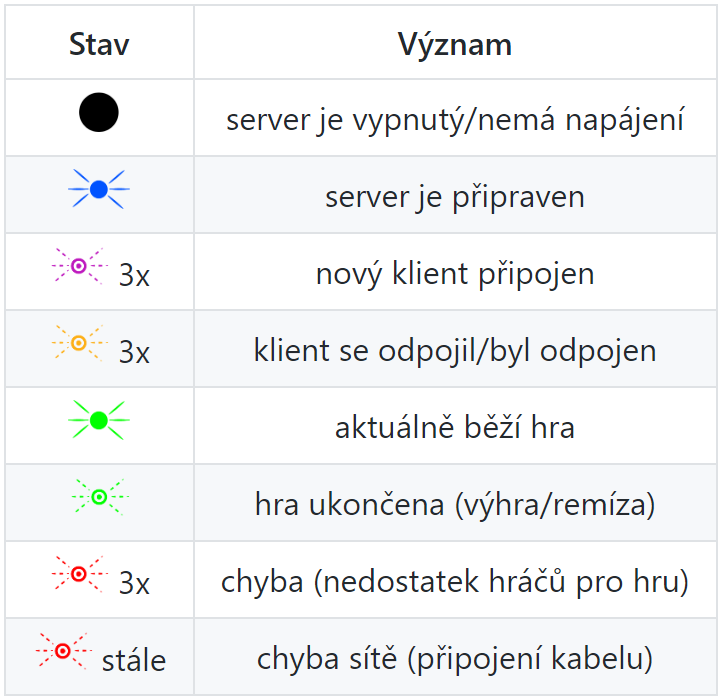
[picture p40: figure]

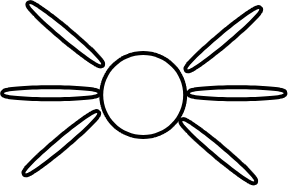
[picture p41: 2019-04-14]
BAP/zaverecna_prace_FEL/img/manual/white.png

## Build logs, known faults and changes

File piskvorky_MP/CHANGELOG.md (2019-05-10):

# BP_PROJ: Piskvorky MP

### 10.05.2019
- Změna komunikačního portu na 55555, dle RFC6335
- Úprava komnetřá v kódu pro klienta

### 06.05.2019
- Úprava MAC adresa na ty, které mají desky Arduino Ethernet přiřazené od výrobce (na štítku zespodu)
- Výměna displeje pro klienta číslo 3, přidání kalibračních dat pro nový displej

### 05.05.2019
- Server:
  - Přidáno nastavení síťového režimu (_ETHMODE\_DHCP_ a _ETHMODE\_STATIC_, stejný princip jako u clienta)
  - Upraveny podmínky u direktiv _#elif_ (přidáno _defined()_)
- Client:
    - Upraveny podmínky u direktiv _#elif_ (přidáno _defined()_)

### 21.04.2019
- Program pro clienta:
  - Upraveny přidání schémata v nastavení pro jednotlivé clienty pomocí direktiv (#define CLIENT_x_)
  - Přidán režim doutykové plochy displeje _TOUCH\_LANDSCAPE_ případně _TOUCH\_PORTRAIT_
  - Přidán síťové režimy:
    - _ETHMODE\_DHCP_: client získává IP adresu z DHCP serveru
    - _ETHMODE\_STATIC_: client používá statickou IP adresu nastavenou v kódu
  - Přidány komentáře ke konfiguracím

### 14.04.2019
- Program pro server:
  - Přidány možnost pro debuging
- Úprava manuálu pro piškvorky (_manual.md_): do tabulky přidán příkaz pro přepnutí na dalšího hráče a přidán popis funkce tlačítek

### 13.04.2019
- Program pro server:
  - Přidání příkazu pro odpojení hráčem
  - Přidána varianta, že pokud má server v kódu nastavenou adresu 0.0.0.0, nechá si IP adresu přiřadit DHCP serverem
  - Přídán příkaz pro přeskočení hráčem
  - Pokud běží hra a je stisknuto zelené tlačítko, hra se přesune na dalšího hráče
- Přidání hlavičky do zdrojových kódů, celkové úprava zdrojáků a doplnění komentářů
- Úprava readme.md: přidání odkazů (šipky) de jednotlivých složek
- Úprava manuálu pro piškvorky (_manual.md_): do tabulky přidán příkaz pro odpojení hráče
- Přesun projektu do složky _piskvorky_MP_ a přejmenování příslošných složek pro zdrojáky, úprava názvů v _readme.md_

### 09.03.2019
- Program pro server:
  - Doladěno funguvání indikační LED
  - Provedeno několik testů

- Program pro server:
  - Upravena funkce pro odesílání dat serveru
  - Přidána funkce pro kontrolu spojení se serverem (v případě, že došlo ke ztrátě spojení, je spojení zrušeno i ze strany clienta a vypíše se chybová hláška)
  - Přidáno vyhodnoce kódu devět (vyžádané odpojení ze strany serveru)
  - Kalibrace displejů
  - Drobné kosmetické úpravy kódu a doplnění komentářů
- Zhotoveny kalibrace Clientů 1 a 2 dle zjištění popsané v [notes](https://github.com/janzavorka/BP_PROJ/blob/master/Notes.md).

### 09.03.2019
- Dokončení programu pro clienta (kvůli místu v paměti odstraněna sériová linka)
- Malé úpravy v kódu pro server, odstraněna chyba v přijímací funkci

### 06.03.2019
- Program pro clienta: vylepšení vykreslování dat na displeji, začátek úprav vyhodnocování stisku tlačítek

### 03.03.2019
- Úprava programu pro clienta pro komunikaci se serverem

### 26.02.2019
- Automatické detekce ethernet kontroléru při zapnutí
- Pro kontroléry W5200 a W5500 kontrola připojení kabelu, chyba indikována blikající červenou LED
- Vylepšení a dodělání fukcí pro řízení hry
- Přidány funkce pro indikaci stavu hry pomocí RGB LED

### 25.02.2019
- Úprava funkcí pro řízení hry

### 23.02.2019
- Celkové přepracování programu pro server
- Pro server přidána LED dioda indikující stav
- Přidání zabezpečovacích funkcí pro komunikaci client->server a server -> client

### 12.12.2018
- Program pro clienta
 - pro všechny client desky zkalibrovány displeje, u clienta 3 nutná úprava v loopu (dislej má jinou orientaci)
 - oprava zobrazování hlášek (výhra, prohra, remíza)

### 09.12.2018
- Vytvoření desky s dvěma tlačítkama pro ovládání serveru
- Program pro server
 - přidání fce dvou tlačítek (start, stop), vyhodnocení stisku v loopu (nelze využít interrupty (rozhodilo by odesílání dat))

### 08.12.2018
- Použití Arduino Due jako server
- Program pro server
 - herní deska se odesílá po 8 bajtech
 - oprava funkce pro získání čísla dalšího hráče (docházelo k zacyklení)
 - přidána funkce pro kontrolu výhry
- Program pro clienta
 - Oprava zobrazování barevných koleček (nyní se zobrazují správně)
 - oprava zamrznutí hráče, kdy během jeho tahu dojde k resetu hry ze strany serveru

### 03.12.2018
- Program pro server
 - úprava funkce pro získání dalšího clienta

### 27.11.2018
- Program pro clienta
 - oprava připojovací funkce
 - doladění úvodních obrazovek

### 25.11.2018
- Práce na programu pro clienta:
 - Dodělány jednotlivé fáze hry
 - Funkce pro spojení se serverem
 - Mnoho dalších drobných úprav
- Program pro server
 - správné vyhodnocení odpojených clientů
 - při tahu daného clienta se pošle jen index dané pozice, ne celý herní board

### 12.11.2018
- Program pro clienta:
 - přidání třídy pro tlačítka

### 11.11.2018
- Příprava programu pro clienta
 - Úprava parametrů pro síťové připojení
 - Příprava rozložení packetu pro komunikaci
- Základ programu pro server

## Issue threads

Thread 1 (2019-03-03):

Kontrola hrajícího hráče

janzavorka, 2019-03-03:
V programu pro server přidat do funkce fillPlayerToken(), že hráč, který pole vyplňuje je skutečně na tahu (informace v boardu)

janzavorka, 2019-03-09:
Do funkce byla přidána podmínka pro ověření hrajícího hráče: `if(player == board[gb_actPlayer])`, v případě, že hráč není na tahu, pole nebude vyplněno a vypíše se chybová hláška na sériovou linku.
```C++
bool fillPlayerToken(byte coord, byte player){
   if(player == board[gb_actPlayer]){
      if(coord >= 0 && coord < meshX*meshY){
        if(board[coord] == 0){
            board[coord] = player;
            sendBoard(2);
            return true;
        }
        else{
          Serial.print("CHYBA - hrac ");
          Serial.print(player);
          Serial.print(" se pokousi vyplnit obsazene pole: ");
          Serial.println(coord);
          return false;
        }
      }
      else{
        Serial.print("CHYBA - hrac ");
        Serial.print(player);
        Serial.print(" se pokousi vyplnit pole mimo rozsah: ");
        Serial.println(coord);
        return false;
      }
    }
    else{
      Serial.print("CHYBA - hrac ");
      Serial.print(player);
      Serial.print(" neni na tahu");
      return false;
    }
}
```

Closed 2019-03-09.

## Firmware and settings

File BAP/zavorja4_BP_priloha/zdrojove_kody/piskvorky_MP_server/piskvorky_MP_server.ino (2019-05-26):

/*>>>>>>> Piškvorky s arduinem po LAN <<<<<<<
*  !!! Součást programu pro server, samostatně nefunkční !!!
*
* - Autor: Jan Závorka
* - Email: zavorja4@fel.cvut.cz
* - Domovská stránka projektu: https://github.com/janzavorka/BP_PROJ
* - Seznam souborů: piskvorky_MP_server.ino; boardControl.ino; communication.ino; gameControl.ino; indicatioLED.ino; SerialControl.ino
*
* --- Popis:
* - Hra piškvorky pro max 5 hráčů
* - Jednotliví hráči jsou vybaveni deskami ArduinoEthernet s dotykovým displejem
* - Hru řídí server postavený na Arduino Due s Ethernet shieldem
* - Komunikace probíhá po lokální síti
*/

/* ---------- DEBUGING ----------*/
//Aktivovani jednotlivych debugovacích částí (pro aktivování odkomentovan daný #define)
//#define DEBUG
//#define DEBUG0CTS //Zapnutí výpisu pro debugování komunikace client->server
//#define DEBUG0STC //Zapnutí výpisu pro debugování komunikace server->client
//#define DEBUG0GAMEFL //Zapnutí výpisu pro debugování průběhu hry

//Pro debuging přes sériovou linku
#ifdef DEBUG
  #define DEBUG_PRINT(x)     Serial.print (x)
  #define DEBUG_PRINTLN(x)  Serial.println (x)
#else
  #define DEBUG_PRINT(x)
  #define DEBUG_PRINTLN(x)
#endif

#ifdef DEBUG0CTS
  #define DEBUG0CTS_PRINT(x)     Serial.print (x)
  #define DEBUG0CTS_PRINTLN(x)  Serial.println (x)
#else
  #define DEBUG0CTS_PRINT(x)
  #define DEBUG0CTS_PRINTLN(x)
#endif

#ifdef DEBUG0STC
  #define DEBUG0STC_PRINT(x)     Serial.print (x)
  #define DEBUG0STC_PRINTLN(x)  Serial.println (x)
#else
  #define DEBUG0STC_PRINT(x)
  #define DEBUG0STC_PRINTLN(x)
#endif

#ifdef DEBUG0GAMEFL
  #define DEBUG0GAMEFL_PRINT(x)     Serial.print (x)
  #define DEBUG0GAMEFL_PRINTLN(x)  Serial.println (x)
#else
  #define DEBUG0GAMEFL_PRINT(x)
  #define DEBUG0GAMEFL_PRINTLN(x)
#endif
/* ---------- END DEBUGING ----------*/

/* ---------- vložení knihoven ----------*/
#include <Ethernet.h> //Komunikace přes ethernet
#include <SimpleTimer.h> //Časovače

/* ----------Datum změny----------*/
char makeDate[] = "20.05.2019";

/* !!! ---------- KONFIGURACE - nastavení ethernetu ---------- !!! */
//Režimy sítě: ETHMODE_DHCP=server získá IP adresu z DHCP serveru; ETHMODE_STATIC=použije se nastavená IP adresa
//Při módu, kdy je IP adresa přiřazena DHCP serverem, je nutné aby se IP adresa neměnila a aby byla správně nastavena na straně clientů
#define ETHMODE_STATIC //Varianty: ETHMODE_DHCP; ETHMODE_STATIC

// Nastavení MAC adresy (měla by být unikátní)
byte mac[] = {
  0x54, 0xAB, 0x3A, 0x5B, 0x6F, 0x47
};
//
//Nastavení IP adresy serveru, pokud je nastaveno 0.0.0.0 bude IP přiřazena DHCP serverem
//IP adresa serveru musí být vyplněna v kódu pro klienty
IPAddress serverAddress(10,0,0,8);
//
//Port na kterém bude probíhat komunikace
unsigned int localPort = 55555; //Defaultně 55555
/* !!! ---------- KONEC nastavení ethernetu ---------- !!! */

EthernetServer server = EthernetServer(localPort);
const byte  maxPlayers = 4; //Softwarové maximum 5, pro WIZnet W5100 max 4
EthernetClient clients [maxPlayers];
bool clientConnected = false;
bool serverReady = false;

//Casovac
SimpleTimer timer;
namespace std {void __throw_bad_function_call() { while(1); }; } //Pro správné fungování simpleTimer knihovny

//piny pro tlačítka
bool pinReady = false; //Slouží k deaktivaci tlačítek aby se zabránilo vícedotykům současně

/* !!! ---------- KONFIGURACE - nastavení pinů a LED ---------- !!! */
//Piny tlačítka start a reset
#define startPIN 2
#define resetPIN 3
//
//Piny na kterých jsou připojené jednotlivé barvy LED, musí podporovat PWM
#define LED_red 7
#define LED_green 5
#define LED_blue 6
//
//Nastavení maximálního jasu všech LED, interval <0; 100>
const byte LED_br = 40;
/* !!! ---------- KONEC nastavení pinů a LED ---------- !!! */

/* ----------Časové intervaly různých událostí----------*/
const int buttonOff = 1000; //Po jakou dobu bude dotyková plocha deaktivována (zabrání multidotykům)
unsigned long long refresh_buttonOff = 0;

const long clientMessageLast = 10000; //Doba zobrazení zprávy na straně clienta (v milisekundách)
const long clientErrMessageLast = 4000; //Doba zobrazení chybového hlášení na straně clienta


/* ----------Ovládání pomocí sériové linky----------*/
const byte max_buffik = 30;
String buffik = "";

//Rozměry herní sítě
const byte meshX = 11;
const byte meshY =  8;
/* ----------HRA----------*/
byte serverPhase = 0; //označuje fázi hry= 0: čekání na připojení klientů, 1: hra
byte lastPlayer = 0; //Označuje posledního hráče, který hrál
byte crossNum = 5; //Počet koleček, které je nutné spojit pro výhru
byte clientsData [maxPlayers][2][3]; //první index: číslo hráče; druhý index: číslo zprávy (aby bylo provedeno, obě se musí rovnat); třetí index: datový packet1, datový packet2, přijato/nepřijato (0/1) - vyplní server při příjmu dat

/* ----------Barvy----------*/
#define BLACK           0x0000      /*   0,   0,   0 */
#define NAVY            0x000F      /*   0,   0, 128 */
#define DARKGREEN       0x03E0      /*   0, 128,   0 */
#define DARKCYAN        0x03EF      /*   0, 128, 128 */
#define MAROON          0x7800      /* 128,   0,   0 */
#define PURPLE          0x780F      /* 128,   0, 128 */
#define OLIVE           0x7BE0      /* 128, 128,   0 */
#define LIGHTGREY       0xC618      /* 192, 192, 192 */
#define DARKGREY        0x7BEF      /* 128, 128, 128 */
#define BLUE            0x001F      /*   0,   0, 255 */
#define GREEN           0x07E0      /*   0, 255,   0 */
#define CYAN            0x07FF      /*   0, 255,   0 */
#define RED             0xF800      /* 255,   0,   0 */
#define MAGENTA         0xF81F      /* 255,   0, 255 */
#define YELLOW          0xFFE0      /* 255, 255,   0 */
#define WHITE           0xFFFF      /* 255, 255, 255 */
#define ORANGE          0xFD20      /* 255, 165,   0 */
#define GREENYELLOW     0xAFE5      /* 173, 255,  47 */

/* !!! ---------- KONFIGURACE - nastavení barev hráčů ---------- !!! */
//Barvy jaké budou mít jednotliví hráči
//Lze zadat barvu ze seznamu nebo barvu v 16-bit tvaru
#define PLAYER1COLOR RED
#define PLAYER2COLOR GREEN
#define PLAYER3COLOR PURPLE
#define PLAYER4COLOR GREENYELLOW
#define PLAYER5COLOR OLIVE
/* !!! ---------- KONEC nastavení barev hráčů ---------- !!! */

/* ----------Piškvorky----------*/
byte packetLength = 136;
byte board [136];  //Herní deska
/* >>>>> Rozložení herního packetu <<<<<
 *  0-89:   Obsazení herních polí (standadně 0, server doplňuje čísla)
 *  90:     Hlášení prostřednictvím kódu
 *            0:    nic nedělej
 *            1:    vše OK, hraje se, překresli obrazovku
 *            2:    pouze překreslit, nikdo nehraje
 *            3:    připravit novou hru, čekání na hráče (úvodní obrazovka)
 *            9:    odpojit se
 *            100:  hra skončila remízou
 *            101:  vyhrál hráč 1
 *            102:  vyhrál hráč 2
 *            103:  vyhrál hráč 3
 *            104:  vyhrál hráč 4
 *            105:  vyhrál hráč 5
 *            201:  problémy s hráčem 1
 *            202: ....
 *            205: problémy s hráčem 5
 *  91:     Číslo hrajícího hráče
 *  93:     Počet odehraných kol, zvyšuje se na straně serveru
 *  95-96:  Barva hráče 1
 *  97-98:  Barva hráče 2
 *  99-100: Barva hráče 3
 *  100-101:Barva hráče 4
 *  102-103:Barva hráče 5
 *  104-107:IP hráče 1
 *  108-111:IP hráče 2
 *  112-115:IP hráče 3
 *  116-119:IP hráče 4
 *  120-123:IP hráče 5
 */
//Označení jednotlivých pozic v boardu
#define gb_code       90
#define gb_actPlayer  91
#define gb_filled     92
#define gb_round      93
#define gb_PC1        95
#define gb_PC2        97
#define gb_PC3        99
#define gb_PC4        101
#define gb_PC5        103

const byte colorAddr [] = {gb_PC1, gb_PC2, gb_PC3, gb_PC4, gb_PC5}; //Pole adres barev hráčů v poli board
const byte IPaddr [] = {105, 109, 113, 117, 121}; //Počáteční adresy (indexy) jednotlivých IP adres hráčů v boardu
//Počet bajtů, které budou mít jednotlivé packety při odesílání
const byte boardPart = 8; //Délka části pole board

/* ----------Ovládání indikační LED----------*/
//Barvy pro LED (tvar RGB)
byte LEDcol_red[] = {255, 0, 0};
byte LEDcol_green[] = {0, 255, 0};
byte LEDcol_blue[] = {0, 0, 255};
byte LEDcol_orange[] = {255, 80, 0};
byte LEDcol_violet[] = {255,0,255};
//byte LEDcol_red[] = {255, 0, 0};

//class pro RGB LED
class RGB_LED{
  private:
    byte p_RED = 0;
    byte p_GREEN = 0;
    byte p_BLUE = 0;
    byte static_col[3] = {255,255,255}; //Pro statické svícení
    byte blink_col[3] = {255,255,255}; //Pro blikání
    bool blinkState = false;
    byte intensity = 0;
    byte blinkCount = 0;
    int blinkTimerID = 0;

  public:
    RGB_LED();
    RGB_LED(byte Red, byte Green, byte Blue, byte intens);
    void changeStaticColor(byte color[]);
    void changeIntensity(byte inten);
    void changeBlinkColor(byte color[], byte times);
    void blink(void);
    void LEDoff(void);
    void LEDon(void);
    void checkLEDstat(void);
};

//indikační RGB LED připojená k serveru
RGB_LED signalLED;

/* ----------PROTOTYPY----------*/
/* gameControl.ino */
void startGame(void); //Spustí hru
void stopGame(void); //Zruší běžící hru
byte getNextPlayer(byte); //Vrátí číslo dalšího hráče (argument fce je číslo předchozího hráče)
void checkGame(byte, byte); //Zkontroluje průběh hry...případně vyplní kód v boardu, argument je poslední pole a číslo hrajícího hráče
void shiftPlayer(void); //Změní číslo hráče a odešle herní desku
bool fillPlayerToken(byte, byte); //Vyplní do herní desky číslo hráče, který dané pole obsadil (argument1 = číslo pole, argument2 = číslo hráče)

/* communication.ino */
void sendBoardR(void); //Odešle data veme beze změny kódu
void sendBoard(byte); //Odešle herní desku všem hráčům (argument číslo řídicího kódu)
void sendBoard(byte, byte); //Odešle herní desku konkrétnímu hráči (argument číslo řídicího kódu a číslo clienta/hráče)
void sendBoardPart(byte, byte); //Odešle danou část herí desky (board) danému hráči
void syncBoardIPs(void); //Synchronizuje herní desku board s připojenými clienty
void checkIncommingData(void); //Kontroluje, zda nějaký client neposlal data
void recieveData(byte); //Přijme data a případně zpracuje, argument je index hráče
void resetClientData(byte); //Smaže přijatá data daného clienta
void processClientData(byte); //Provede požadované úkony pro daného hráče
void disconnectPlayer(byte); //Odpojí dané hráče (včetně resetování boardu a informování ostatních hráčů)
void sendErrMessage(byte); //Pošle chybovou zprávu
byte getHWcontroller(void); //Vrátí číslo použitého ethernet kontroléru

/* boardControl.ino */
void setBoard(void); //Připraví herní pole pro novou hru (reset a doplnění potřebných dat (barvy apod.))
void cleanBoard(void); //Resetuje herní pole (vyplní ho nulami)

/* SerialControl.ino */
void print_WC(void); //Voláno v případě chybného příkazu (ten vypíše společně s chybovou hláškou)
void processBuffik(void); //Zpracuje přijatou zprávu přes sériovou linku
void printLine(byte, byte); //Vypíše několik zadaných znaků za sebou (pro výpis oddělovacích čar na sériovém monitoru)

/*
 * >>>>>>>>>> SETUP <<<<<<<<<<
 */
void setup() {
  delay(100);
  //Sériová linka
  Serial.begin(9600);
  //Alokace paměti pro string buffik
  buffik.reserve(max_buffik);
  //Tlačítka
  pinMode(startPIN, INPUT_PULLUP);
  pinMode(resetPIN, INPUT_PULLUP);
  randomSeed(analogRead(0)); //Seed pro funkci random()
  delay(400);

  //Ethernet.init(10);
  //Nastavení LED
  signalLED = RGB_LED(LED_red, LED_green, LED_blue, 100);
  delay(200);
  signalLED.LEDoff();
  delay(400);


  Serial.println(" >>>>> Startuji piskvorkovy server <<<<< ");

  //Kontrola připojení kabelu (dostupné jen pro některé WIZNET kontroléry)
  if(getHWcontroller() > 1){ //Pokud je kontrolér W5200 nebo W5500 (pro ostatní není funkce podporována)
      if(Ethernet.linkStatus() == LinkOFF){//Kontrola pripojeni kabelu
        Serial.println("Zkontrolujte pripojeni kabelu");
      }
      while(Ethernet.linkStatus() == LinkOFF){
          signalLED.changeStaticColor(LEDcol_red);
          signalLED.LEDon();
          delay(500);
          signalLED.LEDoff();
          delay(500);
      }
  }

  //Ethernet

 #ifdef ETHMODE_DHCP
 //Rezim, kdy je IP adresa přiřazena DHCP serverem
    Serial.println("Ziskavam adresu z DHCP serveru");
    signalLED.changeStaticColor (LEDcol_red);
    signalLED.LEDon();
    delay(100);
    while(!Ethernet.begin(mac)){
      Serial.println("IP adresa nebyla prirazena, zkontrolujte pripojeni!");
      signalLED.LEDoff();
      delay(400);
      signalLED.LEDon();
      delay(400);
      signalLED.LEDoff();
      delay(400);
      signalLED.LEDon();
    }
#elif defined(ETHMODE_STATIC)
 //Pouzije se daná IP adresa
 delay(200);
 Ethernet.begin(mac, serverAddress);
 delay(200);
#else
  #error "Error - je nutne vybrat sitovy rezim (viz. KONFIGURACE - nastavení sítě)"
#endif

  delay(500);
  Serial.print("Server IP adresa: ");
  Serial.println(Ethernet.localIP());
  delay(200);
  do{
    server.begin();
    delay(500);
    Serial.println("Spoustim server");
  }while(!server);
  Serial.println("Server spusten!");
  delay(200);

  //Reset datových polí
  setBoard();
  for(byte i = 0; i < maxPlayers; i++){
    resetClientData(i);
  }

  delay(100);
  signalLED.changeStaticColor (LEDcol_blue);
  delay(50);
}

/*
 * >>>>>>>>>> LOOP <<<<<<<<<<
 */
void loop() {
  if ((millis() - refresh_buttonOff > buttonOff) && !pinReady){ //Obnova funkce tlačítek (zabrání přečtení více stisků současně)
    pinReady = true;
    refresh_buttonOff = millis();
  }
  timer.run(); //Aby timery správně běžely (knihovna simpleTimer)
  checkIncommingData(); //Kontroluje, zda nejsou k dispozici data od klientů
  // --- Připojování nového hráče ---
    if(serverPhase == 0){ //Pokud neběží hra
      EthernetClient newClient = server.accept();
      delay(10);
      if ((newClient)) {
        Serial.println("Pripojen novy uzivatel");
        bool clientOK = true; //Zda client může být připojen (pokud neprojde nějakým testem, změní se na false)
        byte clientIndex = 100; //Index, ktery bude clientovi přiřazen

        //Hledání volné pozice pro nového clienta
        for(int i = 0; i < maxPlayers; i++){
          if(!clients[i]){
            clientIndex = i;
            break;
          }
        }
        if(clientIndex==100){ //Pokud index zůstal 100, není pro clienta místo
          Serial.println("Neni volna pozice pro noveho hrace");
          clientOK = false;
        }

        //Test na duplicitu
        for(byte i = 0; i < maxPlayers; i++){ //Ověření duplicit
            if(clients[i].remoteIP() == newClient.remoteIP()){
               clientOK = false;
               Serial.println("Stejny hrac je jiz pripojen");
               sendBoard(board[gb_code], i+1); //Deska se odešle hráči znovu
               break;
            }
        }

        //Kontrola, zda client poslal pro připojení správný kód (v cyklu je počet pokusů)
        byte checkCode = 0;
        for(int i = 0; i < 200; i++){
          if(newClient.available()){
            checkCode = newClient.read();
            break;
          }
          delay(10);
        }
        //Odstranění zbylých dat od clienta
        while(newClient.available()){
          byte bin = newClient.read();
        }
        //Kontrola, zda přijatý kód pro připojení je správný
        if(checkCode != 100){
          clientOK = false;
        }

        if(clientOK){ //Pokud novy klient prošl testy
          clients[clientIndex] = newClient; //Nový klient je přiřazen na danou pozici
          syncBoardIPs(); //synchronizují se IP adresy
          sendBoard(3);
          signalLED.changeBlinkColor(LEDcol_violet, 3); //Signalizace pomocí LED
          Serial.print("Novy client cislo ");
          Serial.print(clientIndex+1);
          Serial.print(" s IP adresou ");
          Serial.print(clients[clientIndex].remoteIP());
          Serial.print(" USPESNE pripojen \n\n");
        }
        else{
          Serial.print("Client s IP adresou ");
          Serial.print(newClient.remoteIP());
          Serial.print(" NEBYL pripojen \n\n");
          newClient.stop();
        }
      }
    }
    else if(serverPhase == 1){ //Fáze začátek hry
      //Kód vykonávaný v průběhu hry
    }
    else{
      DEBUG_PRINTLN("NEZNAM");
    }

  //Kontroluje odpojení jednotlivých klientů
  for (byte i = 0; i < maxPlayers; i++) {
    if ((clients[i]) && !clients[i].connected()) { //DEFAULT (clients[i]) && !clients[i].connected(), test (board[IPaddr[i]] != 0)
      delay(20);
      disconnectPlayer(i+1);
    }
  }


  //Kontrola stisku tlačítek, nepoužívá se interrupt - mohl by rozhodit odesílání
  if(pinReady){ //Pokud je tlačítko aktivní (zabraňuje vícedotykům)
    if(digitalRead(startPIN) == LOW){
      pinReady = false;
      refresh_buttonOff = millis(); //čas užití tlačítka (pro funkci, která tlačítka po určené době obnoví)
      if(serverPhase == 1){//Pokud je spuštěná hra, přepni na dalšího hráče
          shiftPlayer();
      }
      else{ //Jinak začni hru
        startGame();
      }
    }
    if(digitalRead(resetPIN) == LOW){
      pinReady = false;
      refresh_buttonOff = millis();
      stopGame();
    }
  }
  delay(30);
}

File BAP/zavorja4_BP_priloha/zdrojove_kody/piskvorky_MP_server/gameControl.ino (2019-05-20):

/*>>>>>>> Piškvorky s arduinem po LAN <<<<<<<
*  !!! Součást programu pro server, samostatně nefunkční !!!
*
* - Autor: Jan Závorka
* - Email: zavorja4@fel.cvut.cz
* - Domovská stránka projektu: https://github.com/janzavorka/BP_PROJ
* - Seznam souborů: piskvorky_MP_server.ino; boardControl.ino; communication.ino; gameControl.ino; indicatioLED.ino; SerialControl.ino
*
* --- Popis:
* - Část zodpovědná za řízení průběhu hry
*/

//>>>>> spustí hru <<<<<
 /*   Princip:
  *    - Zajistí nastavení herního pole, vybere prvního hráče a odešle řídicí kód
  */
void startGame (){
  if(serverPhase == 1){
    Serial.println("Aktualne bezi hra");
  }
  else{
    Serial.println("Spoustim hru");
    serverPhase = 1;
    syncBoardIPs();
    byte ONplayers = 0; //Pocet hracu online

    for (byte i = 0; i < maxPlayers; i++){ //Kontrola, zda jsou připojení alespoň dva hráči
      if(clients[i]){
        ONplayers++;
      }
    }

    if(ONplayers < 2){
      Serial.print("Je k dispozici jen ");
      Serial.print(ONplayers);
      Serial.println(" hracu, hra nemuze zacit.");
      signalLED.changeBlinkColor(LEDcol_red, 3);
      stopGame();
      return;
    }
    sendBoard(2); //Pošle všem příkaz k překreslení obrazovky (bez hráče)
    board[gb_round] = 0; //Vynulování počtu odehraných kol
    board[gb_actPlayer] = getNextPlayerNumber(random(1, maxPlayers)); //Náhodně se vybere číslo začínajícího hráče
    DEBUG_PRINT("Zacina hrac: ");
    DEBUG_PRINTLN(board[gb_actPlayer]);
    signalLED.changeStaticColor(LEDcol_green);
    delay(200);
    sendBoard(1);
  }
}
//------------------------------------------------------------------------------------------------------
//>>>>> Zastaví běžící hru <<<<<
 /*   Princip:
  *    - Pošle ukončující řídicí kód
  *    - Změní barvu ndikační LED
  */
void stopGame (){
  Serial.println("Zastavuji hru");
  delay(5);
  sendBoard(3);
  serverPhase = 0;
  signalLED.changeStaticColor(LEDcol_blue);
  setBoard(); //Vyčistí herní pole
}
//------------------------------------------------------------------------------------------------------
//>>>>> Vrátí šíslo dalšího hráče <<<<<
 /*   Princip:
  *    - zkontroluje pole clients, aby se jednalo o hráče, který je připojen
  *    - player1 je číslo předchozího (aktuálně hrajícího hráče)
  *    - Pokud cyklus projde všechyn z pole "clients[]" a dalšího hráče nenalazne, znamená to, že se všichni odpojili a server ukončí hru
  */
byte getNextPlayerNumber(byte player1){
  byte runIndex = 0;
  do{
    player1++;
    if(player1 > maxPlayers){
      player1 = 1;
    }
    if(player1 < 1){
      player1 = maxPlayers;
    }
    if(runIndex > maxPlayers*2){ //Pokud není hráč k dispozici, hra se ukončí
      stopGame();
    }
    runIndex++;
  }while(!clients[player1-1]);
  return player1;
}
//------------------------------------------------------------------------------------------------------
//>>>>> Zkontroluje běh hry <<<<<
 /*   Princip:
  *    - zkontroleuje běh hry
  *    - vyhodnocuje výhru hráče
  *    - vyhodnocuje remízu (vysoký počet herních kol)
  *    - automaticky zapíše do kódu v boardu
  */
void checkGame(byte cross, byte player){
//Vyhodnocení žetonů v poli (děje se pro naposled vyplněný žeton daného hráče)
    byte row = 0;
    byte column = 0;
    byte count = 0; //počet puntíků za sebou
    bool win = false;
    row = cross/11; //v jakém řádku se nachází vyplněný žeton
    column = cross%11; //v jakém sloupci se nachází vyplněný žeton

     for(byte i = 0; i < meshX; i++){ //kontrola celého řádku
        if(board[11*row + i ] == player){
          count++; //Počet žetonů vedle sebe
        }
        else{
          count = 0; //Pokud cizí žeton, počet se vynuluje
        }
        if (count >= crossNum){ //Pokud je dostatečný počet, hráč vyhrál
          win = true;
          break;
        }

     }
    count = 0;
     for(int i = 0; i < meshY; i++){ //kontrola daného sloupce
        if(board[column + i*11 ] == player){
          count++;
        }
        else{
          count = 0;
        }
        if (count >= crossNum){
          win = true;
          break;
        }

     }
     count = 0;

     byte index = 0;
     index = cross % 12;
     while (index < meshX*meshY){ //Kontrola do kříže jeden směr
        if(board[index] == player){
          count++;
        }
        else{
          count = 0;
        }
        index += 12;
        if (count >= crossNum){
          win = true;
          break;
        }
     }

     count = 0;
     index = cross % 10;
     while (index < meshX*meshY){ //Kontrola do kříže druhý směr
        if(board[index] == player){
          count++;
        }
        else{
          count = 0;
        }
        index += 10;
        if (count >= crossNum){
          win = true;
          break;
        }
     }
    if(win){ //Pokud někdo vyhrál, odešle se zpráva
      Serial.print("Vyhral hrac: ");
      Serial.println(player);
      board[gb_actPlayer] = 0;
      sendBoard(100+player);
      signalLED.changeBlinkColor(LEDcol_green, clientMessageLast/500);
      timer.setTimeout(clientMessageLast, stopGame);

    }
    else if(board[gb_round] >= meshX*meshY){ //Pokud hra skončila remízou (jsou obsazena všechna pole)
      board[gb_actPlayer] = 0;
      sendBoard(100);
      signalLED.changeBlinkColor(LEDcol_green, clientMessageLast/400); //Délka signalizace LED dopočtena z délky zobrazení chybové zprávy
      timer.setTimeout(clientMessageLast, stopGame); //Zpráva o remíze se zobrazí na určitou dobu, pak se resetuje hra
    }
    else{ //Jinak pokračuje další hráč
      #ifdef DEBUG
      Serial.println("Nikdo nevyhral, pokracuji");
      #endif

      shiftPlayer();
    }
}
//------------------------------------------------------------------------------------------------------
//>>>>> Posune (předá) hru dalšímu hráči <<<<<
 /*   Princip:
  *    - Vloží do pole číslo dalšího hráče
  */

void shiftPlayer(){
    board[gb_actPlayer] = getNextPlayerNumber(board[gb_actPlayer]); //Získej číslo dalšího hráče
    DEBUG0GAMEFL_PRINT("Dalsi hrac na rade je cislo: ");
    DEBUG0GAMEFL_PRINTLN(board[gb_actPlayer]);
    sendBoard(1); //Odešle desku s číslem dalšího hráče a s povelem k překreslení

}
//------------------------------------------------------------------------------------------------------
//>>>>> Vyplní token do herního pole <<<<<
 /*   Princip:
  *    - podle zadaného hráče a čísla pole vyplní token
  *    - pokud je pole mimo rozsah nebo je obsazené, vrátí false
  */
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

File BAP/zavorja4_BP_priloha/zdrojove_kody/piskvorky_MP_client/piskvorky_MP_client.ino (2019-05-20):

/*>>>>>>> Piškvorky s arduinem po LAN <<<<<<<
*  !!! Součást programu pro klienta, samostatně nefunkční !!!
*
* - Autor: Jan Závorka
* - Email: zavorja4@fel.cvut.cz
* - Domovská stránka projektu: https://github.com/janzavorka/BP_PROJ
* - Seznam souborů: piskvorky_MP_client.ino; communication.ino; gameControl.ino; DisplayControl.ino
*
* --- Popis:
* - Hra piškvorky pro max 5 hráčů
* - Jednotliví hráči jsou vybaveni deskami ArduinoEthernet s dotykovým displejem
* - Hru řídí server postavený na Arduino Due s Ethernet shieldem
* - Komunikace probíhá po lokální síti
*/

//ethernet
#include <Ethernet.h>
//Displej
#include <UTFTGLUE.h>
//Dotyková plocha
#include "TouchScreen.h"

/* ---------- KONFIGURACE - nastavení schémat----------*/
//Jednotlivá schémata pro různá zařízení typu client
//Lze nakonfigurovat MAC adresu a kalibrační hodnoty dotykové plochy pro jednotlivé clienty, pak se přepíná změnou #define CLIENT1 - CLIENT5
//V případě, že není žádný vybrán, použije se defaultní nastavení
#define CLIENT3 //Výběr profilu pro clienta
/* ---------- KONEC - nastavení schémat----------*/


//Font
#if !defined(SmallFont)
extern uint8_t SmallFont[];   //.kbv GLUE defines as GFXFont ref
#endif
/* ---------- KONFIGURACE - nastavení mac adres----------*/
//Nastavení MAC adres pro jednotlivé clienty
//Každý client by měl mít unikatní MAC adresu, u oficiálních Arduino desek bývá štítek nalepen přímo na kitu
//Pro každého clienta je možné nadefinovat vlastní MAC a pak při nahrávání (kompilaci) měnit #define CLIENTx

#ifdef CLIENT1
//Client 1
byte mac[] = {
  0x90, 0xA2, 0xDA, 0x11, 0x08, 0x18
};
#elif defined(CLIENT2)
//Client 2
byte mac[] = {
  0x90, 0xA2, 0xDA, 0x11, 0x09, 0x78
};
#elif defined(CLIENT3)
//Client 3
byte mac[] = {
  0x90, 0xA2, 0xDA, 0x11, 0x08, 0xA0
};
#elif defined(CLIENT4)
//Client 4
byte mac[] = {
  0xDE, 0xAD, 0xBE, 0xEE, 0xFE, 0xBD
};
#elif defined(CLIENT5)
//Client 5
byte mac[] = {
  0xDE, 0xAD, 0xBE, 0xEE, 0xFE, 0xAD
};
#else
//Defaultní hodnoty
#warning "Je pouzita defaultni MAC adresa"
byte mac [] = {
  0xDE, 0xAD, 0xBE, 0xEE, 0xFE, 0xAB
}
#endif
/* ---------- KONEC - nastavení mac adres----------*/

/* ---------- KONFIGURACE - nastavení sítě ----------*/
//Nastavení lokálního síťového režimu a parametrů
//Režimy sítě: ETHMODE_DHCP=client získá IP adresu z DHCP serveru; ETHMODE_STATIC=použije se nastavená IP adresa
//V případě ETHMODE_STATIC lze využít schémata pro jednotlivá zařízení typu client (viz. KONFIGURACE - nastavení schémat)
//IP adresa herního serveru, ke kterému se bude client připojovat

#define ETHMODE_STATIC //Varianty: ETHMODE_DHCP; ETHMODE_STATIC

#ifdef ETHMODE_STATIC
  #ifdef CLIENT1
  IPAddress clientAddress(10,0,0,138);

  #elif defined(CLIENT2)
  IPAddress clientAddress(10,0,0,139);

  #elif defined(CLIENT3)
  IPAddress clientAddress(10,0,0,140);

  #elif defined(CLIENT4)
  IPAddress clientAddress(10,0,0,141);

  #elif defined(CLIENT5)
  IPAddress clientAddress(10,0,0,142);
  #else
  //Defaultní nastavení
  IPAddress clientAddress(10,0,0,100);
  #warning "Pozor - je pouzito defaultni nastaveni IP, pro kazdeho clienta nutno zmenit"
  #endif
#endif


IPAddress serverAddress(10,0,0,8);  //Nastavení IP adresy serveru
unsigned int localPort = 55555;      //Port
/* ---------- KONEC - nastavení sítě ----------*/


EthernetClient client;
bool connectingToServer = false;
bool serverReady = false;


/* ----------Nastavení dotykové plochy----------*/
#define YP A1  // must be an analog pin, use "An" notation!
#define XM A2  // must be an analog pin, use "An" notation!
#define YM 7   // can be a digital pin
#define XP 6   // can be a digital pin
//Maximální a minimální tlak
#define MINPRESSURE 10
#define MAXPRESSURE 1000

int TSx, TSy = 0;
TSPoint touchPoint;
bool touchScreenAct = true; //Aktivuje/deaktivuje dotykovou plochu - zabránění vícedotykům najednou

/* ---------- KONFIGURACE - kalibrace displeje ----------*/
//Kalibrace jednotlivých displajů
//Kalibraci lze provést například pomocí příkladu v knihovně UTFGLU
//MCUFRIEND_kbv -> TouchScreen_calibr_kbv
//Uložené kalibrační hodnoty pro použité displeje
//Pro každého clienta je možné nadefinovat vlastní hodnoty a pak při nahrávání (kompilaci) měnit #define CLIENTx
//Je nutné nastavit orientaci dotykové plochy #define TOUCH_LANDSCAPE nebo #define TOUCH_PORTRAIT, centrálně nebo pro každou variantu zvlášť

#ifdef CLIENT1
//Client 1
#define TOUCH_XMIN 221
#define TOUCH_XMAX 950
#define TOUCH_YMIN 200
#define TOUCH_YMAX 950
#define TOUCH_LANDSCAPE
#elif defined(CLIENT2)
//Client 2
#define TOUCH_XMIN  233
#define TOUCH_XMAX  937
#define TOUCH_YMIN  210
#define TOUCH_YMAX  910
#define TOUCH_LANDSCAPE
#elif defined(CLIENT3)
//Client 3
#define TOUCH_XMIN 230
#define TOUCH_XMAX 960
#define TOUCH_YMIN 220
#define TOUCH_YMAX 920
#define TOUCH_LANDSCAPE
#elif defined(CLIENT4)
//Client 4
#define TOUCH_XMIN 0
#define TOUCH_XMAX 100
#define TOUCH_YMIN 0
#define TOUCH_YMAX 100
#elif defined(CLIENT5)
//Client 5
#define TOUCH_XMIN 0
#define TOUCH_XMAX 100
#define TOUCH_YMIN 0
#define TOUCH_YMAX 100
#else
//Defaultní nastavení, je nutné upravit
#define TOUCH_XMIN 0
#define TOUCH_XMAX 100
#define TOUCH_YMIN 0
#define TOUCH_YMAX 100
#endif
/* ---------- KONEC - kalibrace displeje ----------*/


/* ----------Časové intervaly různých událostí----------*/
#define touchScreenOff 500 //Po jakou dobu bude dotyková plocha deaktivována (zabrání multidotykům)
unsigned long long refreshTouchScreen = 0;

#define tryReconnect 5000 //Po jaké době se client pokusí znovu spojit se serverem
unsigned long long lastReconnect = 0;

/* ----------Barvy----------*/
#define BLACK           0x0000      /*   0,   0,   0 */
#define NAVY            0x000F      /*   0,   0, 128 */
#define DARKGREEN       0x03E0      /*   0, 128,   0 */
#define DARKCYAN        0x03EF      /*   0, 128, 128 */
#define MAROON          0x7800      /* 128,   0,   0 */
#define PURPLE          0x780F      /* 128,   0, 128 */
#define OLIVE           0x7BE0      /* 128, 128,   0 */
#define LIGHTGREY       0xC618      /* 192, 192, 192 */
#define DARKGREY        0x7BEF      /* 128, 128, 128 */
#define BLUE            0x001F      /*   0,   0, 255 */
#define GREEN           0x07E0      /*   0, 255,   0 */
#define CYAN            0x07FF      /*   0, 255,   0 */
#define RED             0xF800      /* 255,   0,   0 */
#define MAGENTA         0xF81F      /* 255,   0, 255 */
#define YELLOW          0xFFE0      /* 255, 255,   0 */
#define WHITE           0xFFFF      /* 255, 255, 255 */
#define ORANGE          0xFD20      /* 255, 165,   0 */
#define GREENYELLOW     0xAFE5      /* 173, 255,  47 */

/* ----------Inicializační funkce----------*/
UTFTGLUE LCD(0x0154,A2,A1,A3,A4,A0);
//Dotyková plocha
TouchScreen Touch(XP, YP, XM, YM, 300);

/* ----------Nastavení displeje----------*/
#define resX 320 //Rozlišení
#define resY 240
//Rozměry sítě
#define meshX 11
#define meshY 8
//Index poslední vykreslené obrazovky (pro správné překreslení)
byte lastPage = 255;
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

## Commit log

2018-11-12 button class update
2019-03-10 Update piskvorky - server: recieving data fix
    [communication.ino, piskvorky_v1_server.ino]
2019-03-12 Update piskvorky-client: server communication fix (#6), player circle color fix (#5)
    [communication.ino, displayControl.ino, gameControl.ino]
2019-03-12 Upload piskvorky-server: indication LED control (#3)
2019-03-12 Update piskvorky-server: recieving client data fix (#4)
    [communication.ino, gameControl.ino, piskvorky_v1_server.ino]
2019-03-13 Update piskvorky-cliet: bug fixes, display calibration, code styling
    [communication.ino, displayControl.ino, gameControl.ino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]
2019-03-26 Upload case
    [Sestava_krabicka.0003.iam, Sestava_krabicka.iam, case_bottom.0002.ipt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]
2019-03-30 Update client case design
    [Sestava_krabicka.0003.iam, Sestava_krabicka.0008.iam, Sestava_krabicka.iam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]
2019-03-31 Update server case design
    [case_bottom.0002.ipt, case_bottom.0006.ipt, case_bottom.0007.ipt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]
2019-03-31 Update server case design - power hole mark
    [case_bottom.0006.ipt, case_bottom.0007.ipt, case_bottom.0008.ipt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]
2019-04-02 Update case design
2019-04-06 Update server case
    [case_bottom.0008.ipt, case_bottom.0011.ipt, case_bottom.ipt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]
2019-04-06 Upload Arduino hole drawing
2019-04-06 Upload Arduino client case v2
    [Sestava_krabicka.0008.iam, Sestava_krabicka.iam, case_bottom.0010.ipt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]
2019-04-08 Update server case - design check
    [case_bottom.0011.ipt, case_bottom.0012.ipt, case_bottom.ipt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]
2019-04-10 Update server case - design correction
    [case_bottom.0012.ipt, case_bottom.0015.ipt, case_bottom.ipt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]
2019-04-10 Update client case design - prototype corrections
    [Sestava_krabicka.0008.iam, Sestava_krabicka.0009.iam, Sestava_krabicka.iam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]
2019-04-11 Update client case design - side support
    [Sestava_krabicka.0009.iam, Sestava_krabicka.0010.iam, Sestava_krabicka.iam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]
2019-04-12 Update server case design - threaded inserts holes
    [Sestava_krabicka.0010.iam, Sestava_krabicka.0011.iam, Sestava_krabicka.iam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]
2019-04-14 Delete divided client program
    All program division for clients (unique MAC addresses, touch screen calibration) are made by preprocessor directive
2019-04-14 Update maual data - LED icons
2019-04-17 Upload material list
    [material_list.ods]
2019-04-17 Second version no needed
    [Sestava_krabicka.0008.iam, Sestava_krabicka.iam, case_bottom.0010.ipt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]
2019-04-17 Update case design
    Fix fillet edge, assembly picture update
    [Sestava_krabicka.0011.iam, Sestava_krabicka.0012.iam, Sestava_krabicka.iam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]
2019-05-04 Update client: directive fix
    [piskvorky_MP_client.ino]
2019-05-04 Update server: net modes added, directive fix
    [piskvorky_MP_server.ino]
2019-05-15 Update BP: added flow charts
2019-05-16 Update BAP: flow charts added, picture moving, game flow text modification, appendix modification
2019-05-17 Update BP: flow chart added, introduction completed.
2019-05-20 Update BAP: errors, attachment files, formating
    [case_bottom.stl, case_top.stl]
